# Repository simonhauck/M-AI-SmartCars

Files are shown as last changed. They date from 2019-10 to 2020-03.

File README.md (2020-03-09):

# M-AI-SmartCars
<p align="center">
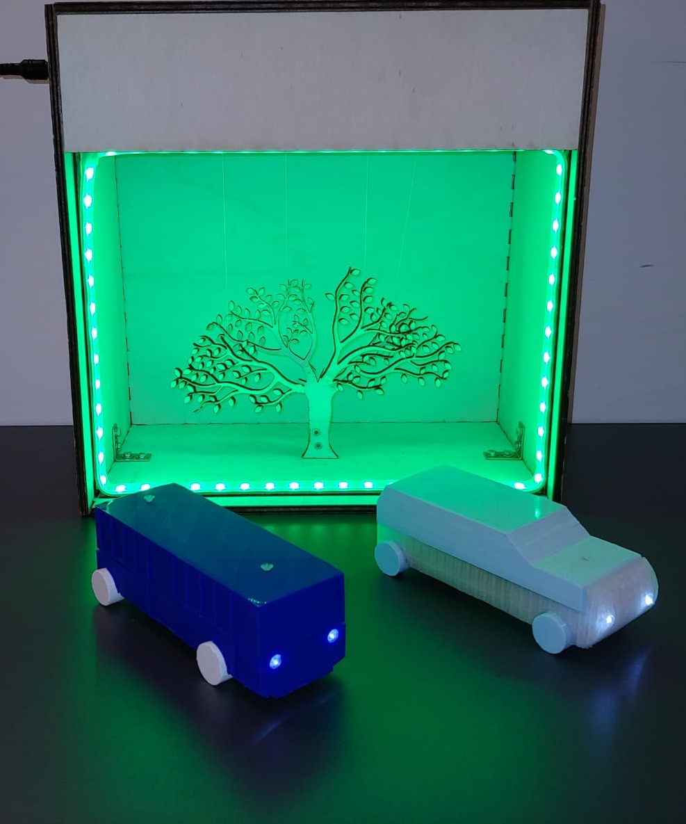
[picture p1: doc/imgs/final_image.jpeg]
  
</p>
This project is part of the course "Makers Lab - Things that think" at the Flensburg University of Applied Sciences. 
We had the motto "Flensburg goes green" and should use various prototype techniques to develop a physical prototype 
that should influence the behavior of the users to act more environmentally friendly.

Our project consist of two parts:
1. Two toy vehicles, a car and a bus, on which we track the driven distance
2. A tree that represents the environment

Our goal was to show children, and also adults the effects of driving for the environment. 
When the vehicles drive, the environment gets worse and the branches of the tree hang low. After a certain time the 
environment gets better and the tree recovers. Of course the bus had a less bad influence then the car.

## How does it work?

### The vehicles
The vehicles are 3D-printed, and contain each an [Arduino MKR 1010 Wifi](https://store.arduino.cc/arduino-mkr-wifi-1010), 
as well as an hall sensor (to be specific the SS 441A), a 3.7V lipo battery and a boost converter. The last one is 
required because the sensor requires 3.7V and with the battery connected the arduino delivers only 3.3V (even from the 5V pin).
Furthermore the vehicles contains two visible LEDs to act as headlights and indicators for the state of the arduino 
(Two in one :D).
The arduino connects on startup to a wireless network of the raspberry pi, that will be used to control the tree. More
on that later. The hall sensor detects if the vehicle is moving and sends the amount of ticks to the raspberry pi.

### The tree
The tree is controlled by a raspberry pi and contains an  LED strip and 4 servo motors. The raspberry pi also acts as an
access point to which the arduinos connect. The server is programmed in python with the flask framework and offers
a simple api to send the amount of ticks of the hall sensor. Depending on the vehicle type the generated pollution is
calculated and stored. The pollution affects the tree only for x seconds (x can be specified in the config file), after
that the entry will be deleted. 

To represent the state of the environment all stored pollution values are summed up and the hardware (the servo 
motors and the led strip) is set accordingly. Like a puppet, the branches of the tree will be moved up and down with
the servo motors. The led stripe is light up, with red and green according to the pollution.

## Structure of the repository
The for you probably most import folder is the src folder. This one contains
1. The 2d folder contains the .dxf file to create the tree and the box with a laser cutter
2. The 3d folder contains the models for the car and the bus. Note that we did some follow up manual work to screw 
both parts together and mount the sensor.
3. The arduino folder contains the wiring diagram and the sketch for the arduino
4. And the pi folder contains, (i think you could have guessed that) the wiring diagram and the python files.
The development server can be started with 
```python
sudo flask run --host=0.0.0.0
```

The other folders are just some stuff for our presentation etc.

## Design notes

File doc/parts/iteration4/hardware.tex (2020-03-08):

% !TeX spellcheck = de_DE
\documentclass[.../Dokumentation.tex]{subfiles}
\begin{document}
    \subsection{Hardware}\label{sec-ita4-hardware}
        \subsubsection*{Visualisierung}
    %Platine, LED Streifen, Autostart %
    Der Programmcode und die benötigte Hardware für die Visualisierung funktionieren bereits, trotzdem müssen noch kleine Optimierungen vorgenommen werden. Zuerst wird die Funktionsweise des LED-Streifens überarbeitet. Zuvor haben alle LEDs dieselbe Farbe angezeigt, welche sich aus Rot und Grün zusammensetzt. Die Farbe Grün ist hierbei intensiver als die Farbe Rot. Infolgedessen wirken die LEDs auch bei mittlerer Verschmutzung grün statt, wie gewünscht, orange.
    Erst bei starker Verschmutzung färben sie sich die LEDs orange und danach rot. Mit der neuen Implementierung zeigen die LEDs unterschiedliche Werte an. Je nach Verschmutzungsgrad färbt sich ein Teil der LEDs rot (Abbildung \ref{fig-hardware-tree-half-ref}). Ist die maximale Verschmutzung erreicht, sind alle LEDs rot. Hierdurch wird die gesamte Verschmutzung eindeutig dargestellt.
    \begin{figure}[H]
    	\begin{center}
    		\includegraphics[
    		width=0.5\linewidth,
    		]{imgs/tree_half_red.PNG}
    		\caption{Visualisierung mit neuer LED-Streifen Implementierung}
    		\label{fig-hardware-tree-half-ref}
    	\end{center}
    \end{figure}
	\noindent
    Im nächsten Schritt wird noch eine Platine für den Raspberry Pi erstellt. Diese kann wie ein Shield auf die Pins gesteckt werden und die Servo-Motoren sowie der LED-Streifen können direkt angeschlossen werden. Dies reduziert die Anzahl an benötigten Kabeln und erhöht die Übersichtlichkeit. Zuletzt wird die Konfiguration des Raspberry Pi überarbeitet. Der Flask-Webserver soll automatisch mit jedem Hochfahren des Systems gestartet werden. Somit muss wie auch bei den Fahrzeugen nur die Stromversorgung hergestellt werden, um den Prototypen zu benutzen.
        
    \subsubsection*{Fahrzeug}
    Für die voll funktionsfähige und getestete Schaltung muss eine Prototyp Platine erstellt werden. Die Basisplatine hat dieselbe Größe wie der Arduino. Somit kann die fertige Platine wie ein Shield auf den Arduino gesteckt werden und verbraucht wenig Platz. Allerdings muss das Layout wegen der begrenzten Größe vorher geplant werden. Eine Skizze hierfür ist in Abbildung \ref{fig-hardware-car-pcb-plan} dargestellt. 
    \begin{figure}[H]
    	\begin{center}
    		\includegraphics[
    		width=0.5\linewidth,
    		]{imgs/car_wiriring_plan.jpeg}
    		\caption{Konzept für die Fahrzeugplatine}
    		\label{fig-hardware-car-pcb-plan}
    	\end{center}
    \end{figure} 
	\noindent
    Die fertige Platine kann auf den Arduino gesteckt werden, welcher zusammen mit dem Akku, dem \textit{Step-Up Boost-Converter}, dem Sensor und den LEDs in das Auto eingebaut wird. Zusätzlich ermöglicht ein Schalter das einfache An- beziehungsweise Ausschalten der Batterie. Alle Verbindungen zwischen den Komponenten sind mit JST-Steckern realisiert. Hierdurch ist es möglich, jede Komponente einzeln auszutauschen, sollte ein Teil defekt sein oder für ein anderes Projekt wiederverwendet werden. Zudem wird so das Zusammensetzen der Fahrzeuge erleichtert, da einige Komponenten wie die LEDs fest verklebt sind.
    Zuletzt wird noch die Konfiguration der Fahrzeuge optimiert. Zuvor haben diese jede Sekunde einmal mal die erfassten Sensordaten gesendet. Da die durchschnittliche Ausführungszeit der \emph{loop}-Funktion bei ca. 100ms liegt, wird dieser Wert auf $250ms$ Sekunden reduziert. Die Fahrzeuge senden häufiger Daten und die Bewegungen des Baums werden infolgedessen weicher.

\end{document}

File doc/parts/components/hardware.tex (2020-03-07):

% !TeX spellcheck = de_DE
\documentclass[.../Dokumentation.tex]{subfiles}
\begin{document}
\subsection{Hardware}\label{sec-components-hardware}
Das Projekt besteht aus zwei Teilen, den Fahrzeugen und der Visualisierung.
Die hierfür benötigte Hardware soll im Folgenden vorgestellt werden.
Die genannten Komponenten beziehen sich auf das Konzept, welches in Kapitel 
\ref{sec-concept} vorgestellt wurde.
\subsubsection{Fahrzeuge}
Die Basis für die Fahrzeuge sollen Microcontroller sein. Diese benötigen 
wenig Strom und ermöglichen so ein längeres Spielvergnügen. 
Für die Fahrzeuge soll der Arduino MKR WiFi 1010 verwendet 
werden. Dieser ist 
ca. 62mm lang und 25mm breit und somit bedeutend kleiner als der Arduino Uno. 
Zusätzlich ist der Arduino besonders für IoT Projekte geeignet, da ein Low 
Power Prozessor (SAMD21) verwendet wird. Das Board besitzt zudem eine 
integrierte Ladeschaltung und einen Anschluss für einen Lithium-Polymer-Akku. 
Hierfür wird ein Modell mit einer Kapazität von 1000mAh verwendet, welches 
einen Kompromiss zwischen der Größe des Akkus und dem Formfaktor bietet. 
Des Weiteren besitzt der verwendete Arduino ein integriertes WiFi-Modul, welches 
später zur Kommunikation mit der Visualisierung verwendet wird.
Neben dem Microcontroller wird jedes Fahrzeug mit einem oder mehreren Magneten sowie einem 
Hall-Sensor ausgestattet. Der Hall-Sensor gibt ein Signal an den Arduino, 
wenn sich ein Magnet in dessen Nähe befindet. Diese werden später zur Erkennung 
von Radumdrehungen verwendet. Zuletzt werden zwei LEDs mit den dazugehörigen 
Widerständen als Scheinwerfer verwendet.

\subsubsection{Visualisierung}
Die Basis für die Visualisierung soll ein Raspbbery Pi 4 sein. An diesen kann 
ein Display angeschlossen werden, welches später die erfassten Daten 
aufbereitet anzeigt. Der Raspberry Pi fungiert zusätzlich als WLAN 
\textit{Access Point}. Die in den Fahrzeugen verwendeten Arduinos können sich 
direkt mit diesem verbinden womit die kabellose Übertragung der Daten 
gewährleistet ist. Dieser Aufbau hat den Vorteil, dass keine weitere 
Hardware wie zum Beispiel ein Router zwischen den Komponenten benötigt wird.

\end{document}

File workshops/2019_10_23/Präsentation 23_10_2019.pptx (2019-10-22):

## Smart Cars

Gruppe Müllteppich

## Fahrzeuge - Stand

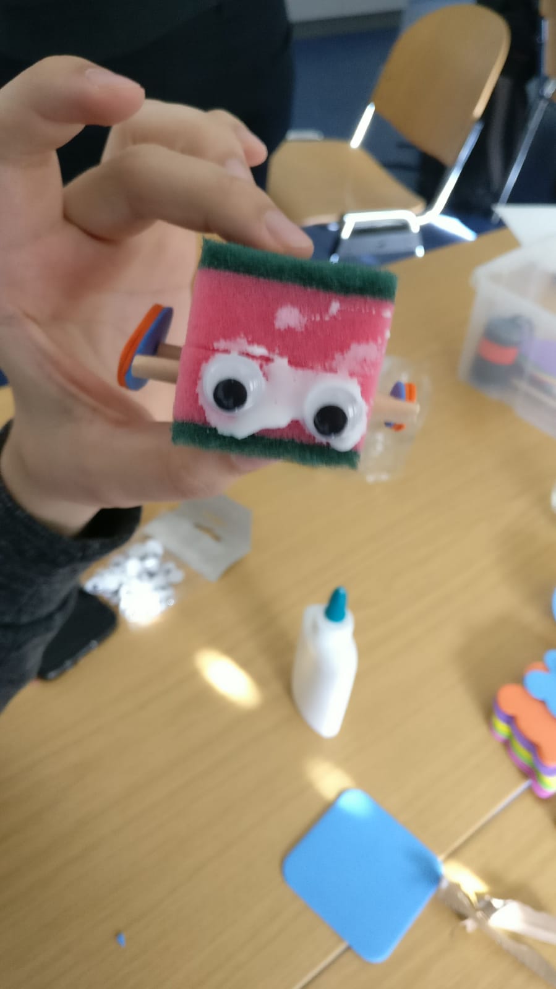
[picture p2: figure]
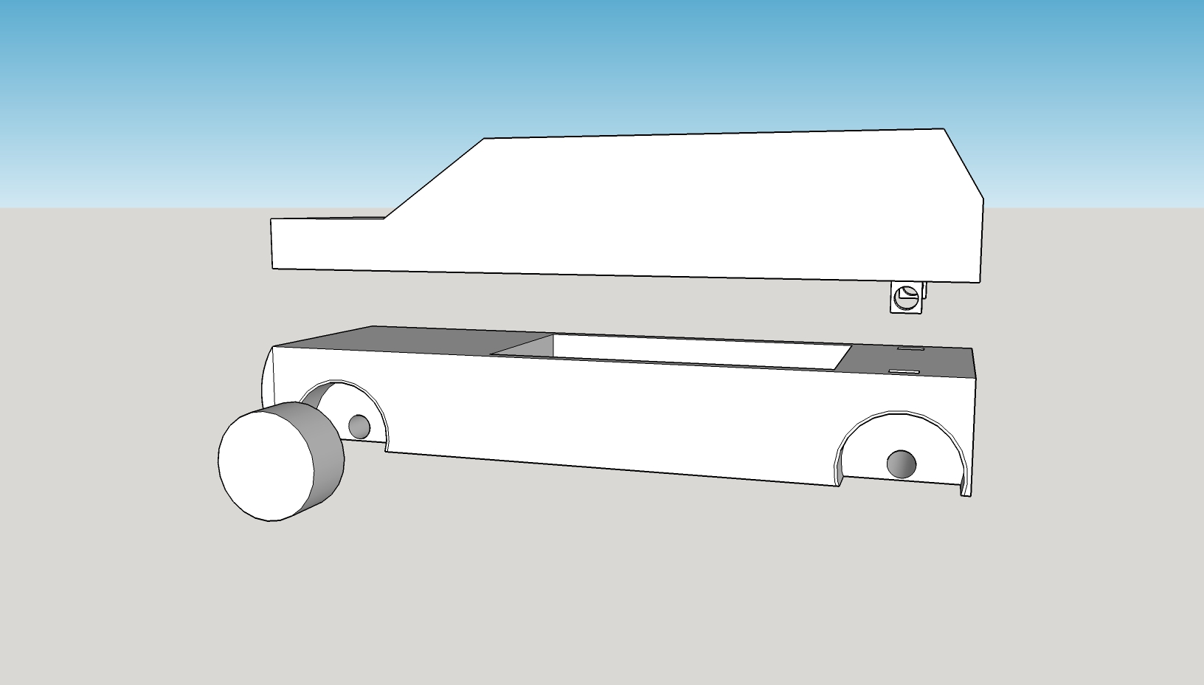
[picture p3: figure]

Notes: Nils

## Fahrzeuge - Stand

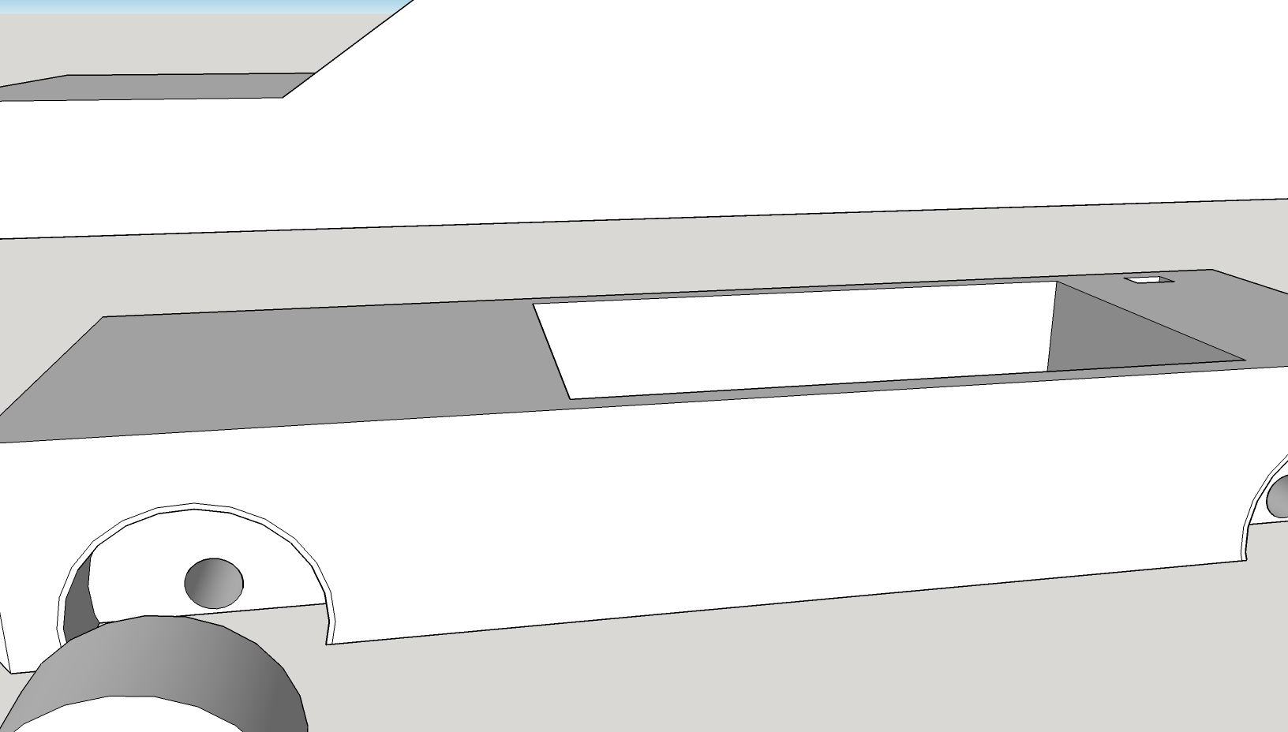
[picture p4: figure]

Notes: Nils

## Fahrzeuge - Stand

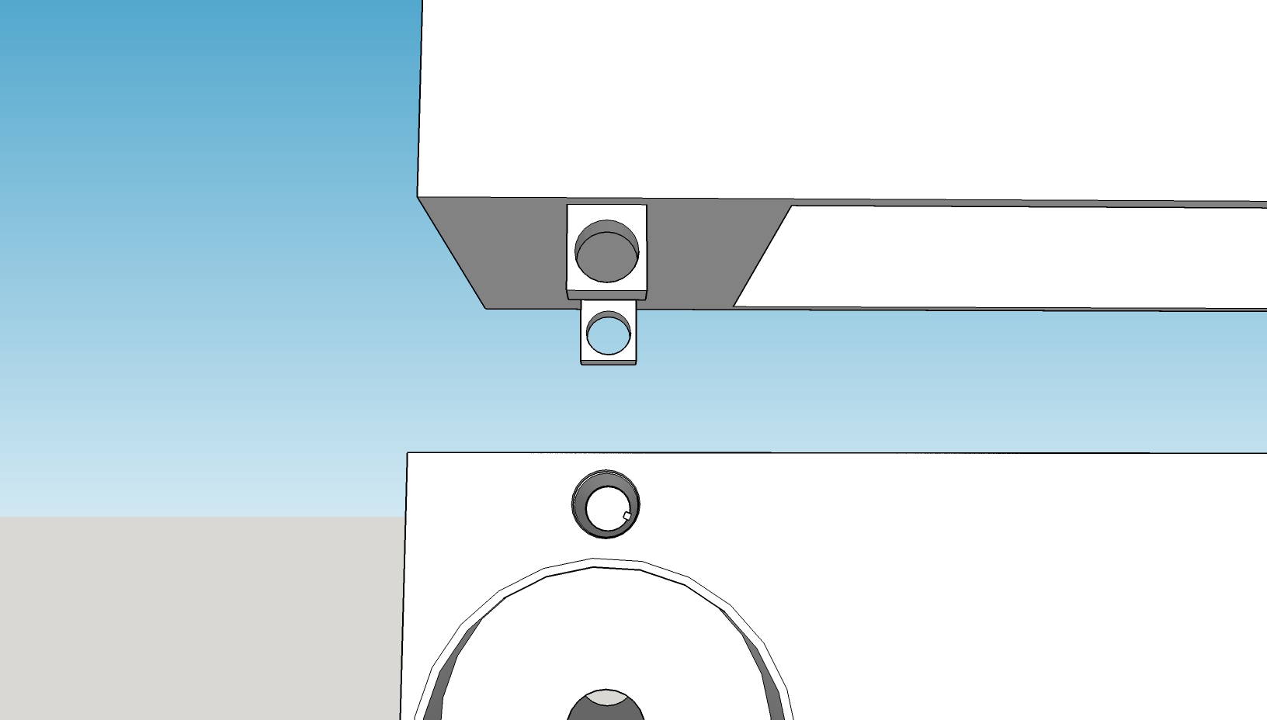
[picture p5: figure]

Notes: Nils

## Fahrzeuge - Stand

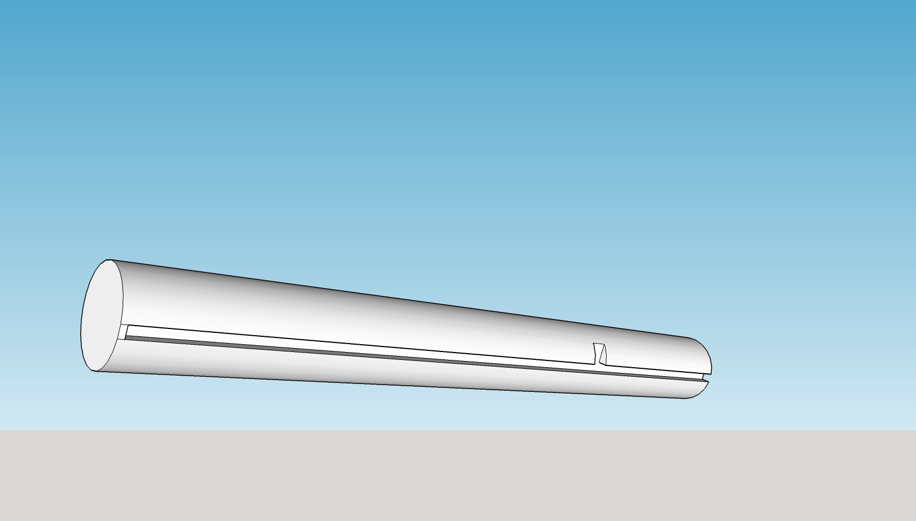
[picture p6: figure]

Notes: Nils

## Fahrzeuge - Herausforderungen

- Formfaktor
- Zusammenführung der Komponenten
- Ladebuchse einbauen

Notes: Nils

## Baum - Stand

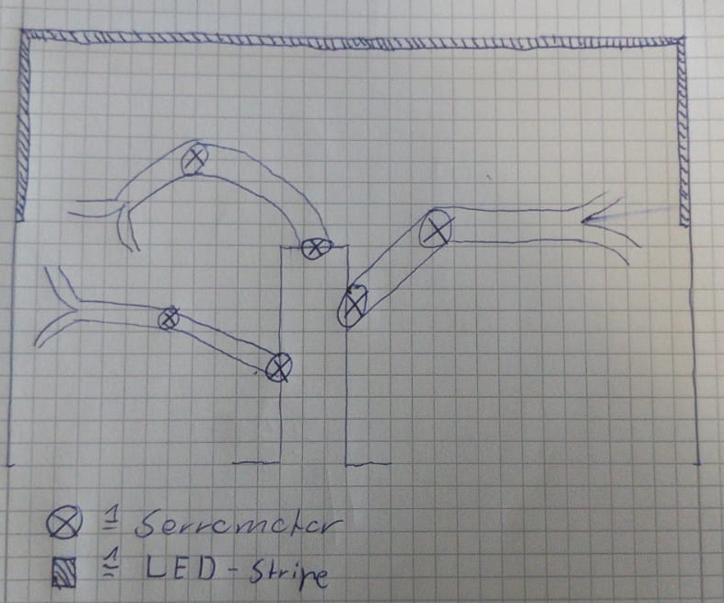
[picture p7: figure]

- Neue Form der Darstellung
- Alternative zu Display und Chart.js

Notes: Nils

## Baum - Herausforderungen

- Umsetzung
  - Lasercutter
  - 3D Druck
- Verbauen der Technik vs. Baum – „Look“
- Gehäuse und LED Integration

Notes: Nils

## Schaltplan - Stand

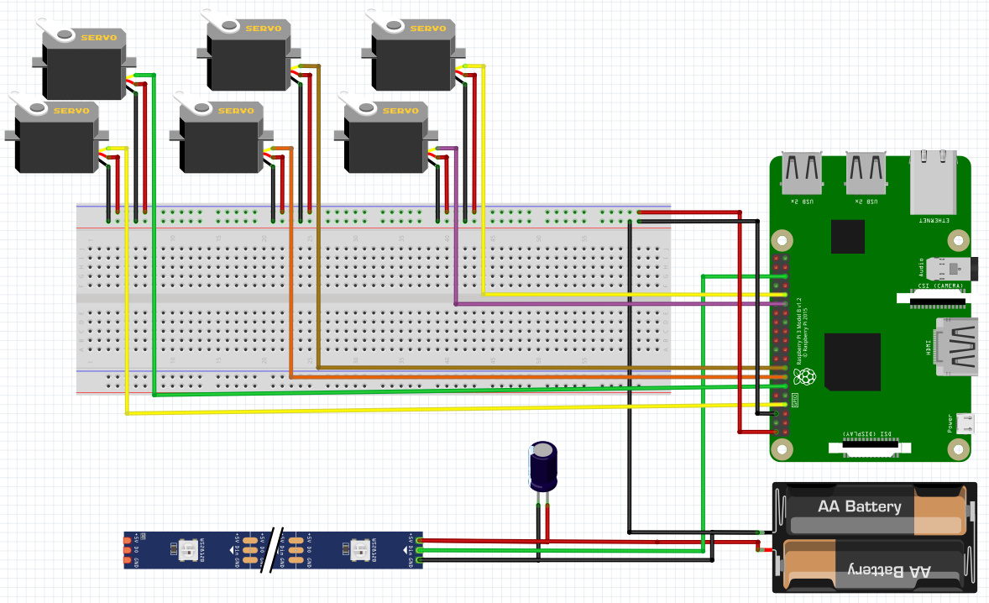
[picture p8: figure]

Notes: Nils

## Schaltplan - Stand

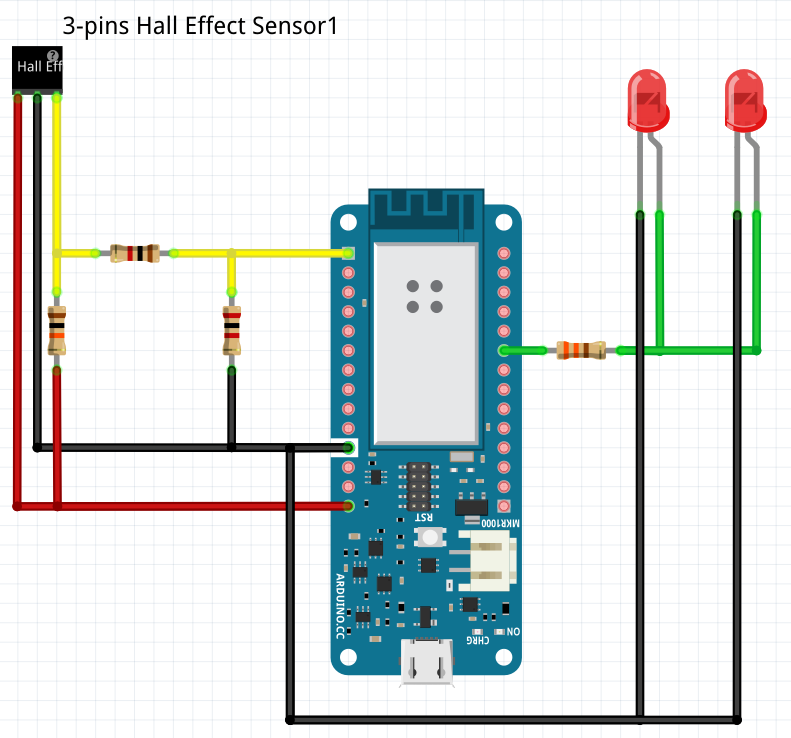
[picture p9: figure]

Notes: Nils

## Schaltplan – Herausforderungen

- Aktueller Microcontroller ungeeignet
  - Max. 3.3V vs 5V
  - Hall-Sensor benötigt mehr Volt
  - Kein Datenblatt zu Sensoren
- Daher bislang keine Tests möglich
- -> Warten auf Hardware

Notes: Nils

## Datemodell Fahrzeuge

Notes: Nils

## Datemodell Baum

- Berechnung der „Verschmutzung“ in letztem Intervall
- Verzögerung
  - Bei Auswirkung
  - Und Regeneration

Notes: Nils

## Untergrund

- Optional: sobald Fahrzeuge und Baum fertig sind
- Realistisch vs Abstrakt
- Da Darstellung bereits abstrakt
  - Abstrakter Untergrund vorzuziehen

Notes: Nils

## Next Steps

- Erster Druck (KW44)
- Backend Implementierung beenden
- Hardware Implementierung beginnen
  - Hall-Sensor testen
  - WIFI testen
  - Scheinwerfer evaluieren

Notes: Nils

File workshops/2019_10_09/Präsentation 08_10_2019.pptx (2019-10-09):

## Smart Cars

Gruppe Müllteppich

## Projektidee

- Verdeutlichung der täglichen Emissionen
- Autofahren macht einen großen Teil aus
- Ziel
  - Veranschaulichen der produzierten Emissionen
  - Steigerung des Umweltbewusstseins
- Zielgruppe:
  - (Junge) Erwachsene
  - Kinder

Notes: Nils

## Projektidee

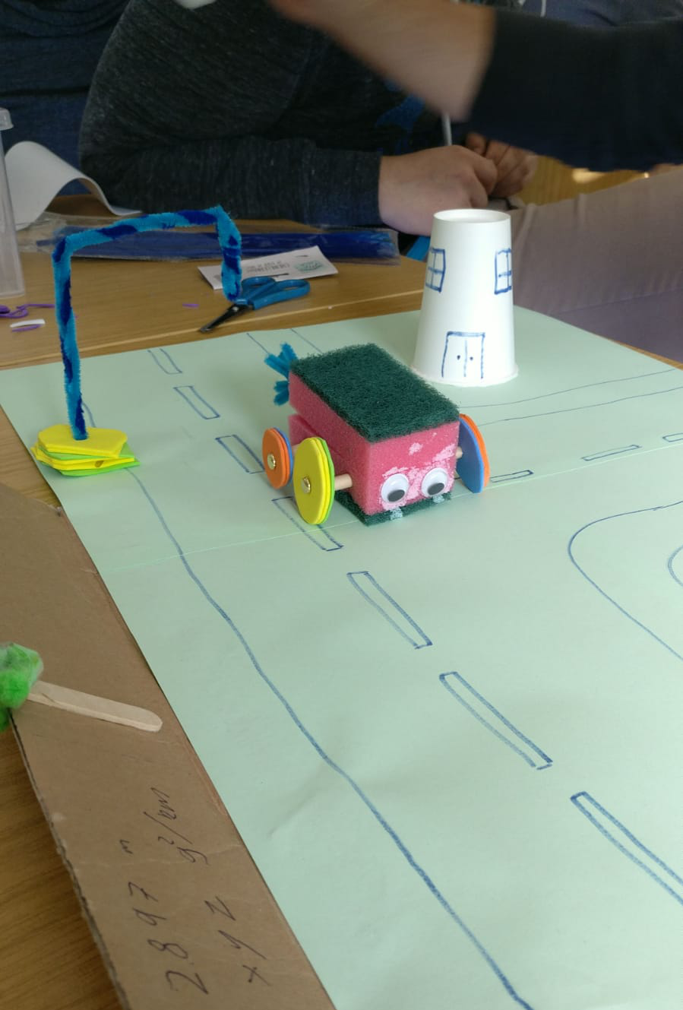
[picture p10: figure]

- Anforderung
  - Einfache Bedienung
    - Keine Konfiguration durch den Nutzer
    - Plug & Play Erfahrung
  - Einfache Visualisierung der Daten

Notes: Nils

## Komponenten & Konzept

- Zwei Pflichtkomponenten
  - 1 – n verschiedene Fahrzeugtypen
    - Verschiedene Emissionsprofile
  - Basis Station
    - Datenspeicherung
    - Datenaufbereitung
- Eine Optionale Komponente
  - Weitere Form der Visualisierung
    - Ballon der verbrauchtes CO2 darstellt
    - LEDs für gesamte CO2 Belastung


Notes: Simon

## Hardware

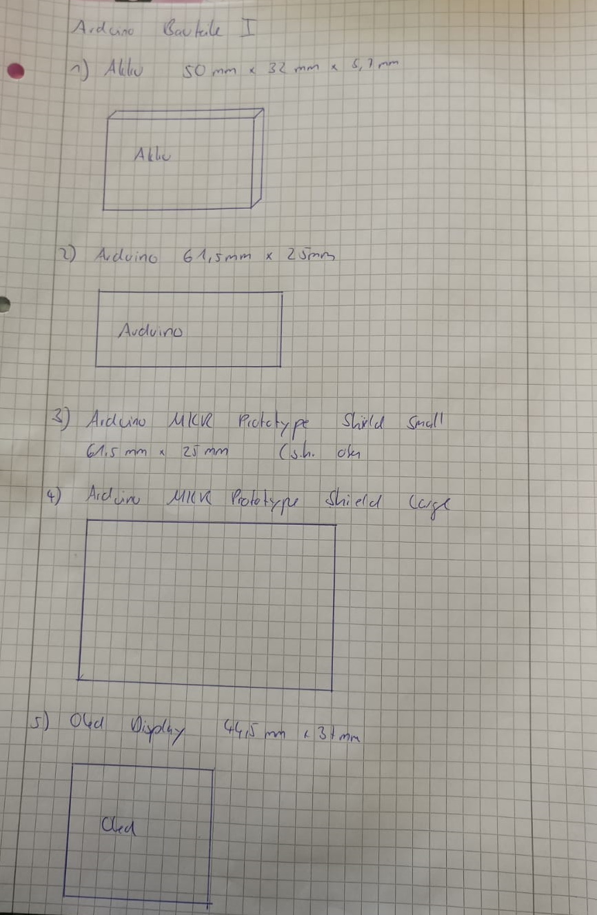
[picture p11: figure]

- Fahrzeuge
  - Arduino mit integriertem Wifi Modul
  - Batterie zur autarken Energieversorgung
  - Sensor zum Erfassen der gefahrenen Strecke / Geschwindigkeit
- Basis Station
  - Raspberry Pi 3B+ mit Wifi Modul
  - Display zur Datenvisualisierung
  - (Optional) Integrierter LEDs
  - (Optional) Luftballon

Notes: Simon

## Aktueller Stand

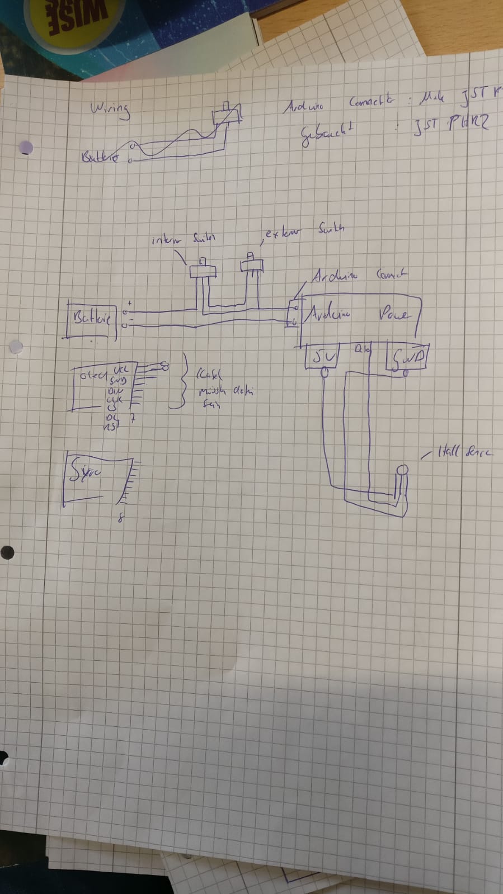
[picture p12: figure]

- Hardware Recherche
  - Auto: Erledigt, benötigt Freigabe
  - Backend: Erledigt, bis auf Ventil
- Fahrzeuge
  - Hardware Skizze
  - Konzeptskizze mit Maßen
- Erste Schritte 3D Modellierung

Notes: Simon

## Next Steps - Backend

- Evaluation
  - Web-Framework
    - Vermutlich Flask
    - Schnittstelle für Sensordaten
    - Darstellung als Website
  - Darstellung
    - Vermutlich ChartJS
  - Hardware
    - (Optional) Library für LEDs
    - (Optional) Steuerung Pumpe/Ventil für Ballon

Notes: Simon

## Next Steps – Auto

- Evaluation
  - 3D Druck für Fahrzeuge
    - Tools zum Erstellen der Modelle (Blender, …)
- Bestellung der Hardware
- Elektronik testen

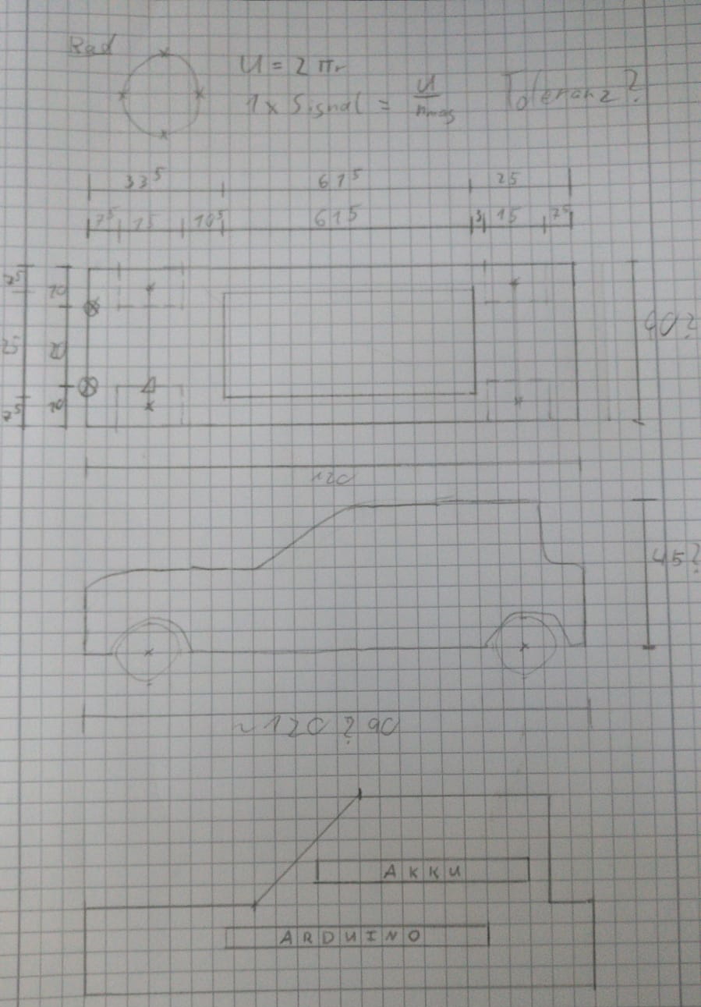
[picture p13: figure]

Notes: Nils

## Next Steps – Allgemein

- Untergrund abklären
- Möglichkeiten des FabLab abklären
- Hardwarebestellung durchführen
- Sonstige Materialien
  - Breadboard, JumperWires, Resistors

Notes: Nils

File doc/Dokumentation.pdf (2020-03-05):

## Hochschule Flensburg

# SmartCars

## Maker’s Lab - Things that Think

## Abschlussbericht

## vorgelegt von:

Simon Hauck | Nils Jensen
660158 | 670758
Hochschule Flensburg | Hochschule Flensburg
simon.hauck@stud.hs-flensburg.de | nils.jensen2@stud.hs-flensburg.de
5. März 2020

## Inhaltsverzeichnis

1 Einleitung | 2
2 Konzept | 3
3 Komponenten | 4
4 1. Design-Iteration | 5
5 2. Design-Iteration | 11
6 3. Design-Iteration | 16
7 4. Design-Iteration | 21
8 Fazit | 27

## 1 Einleitung

Im Zuge der Veranstaltung “Maker’s Lab - Things that Think“ wurde die Entwicklung interaktiver Systeme, bestehend aus Hard- sowie Software, thematisiert. Neben dem Fokus auf der Verwendung von Raspberry Pi beziehungsweise Arduino als Hardware-Komponenten lag ein weiterer Schwerpunkt auf der Verwendung von Techniken und Praktiken aus den Bereichen making und rapid prototyping. Unter Berucksichtigung die- ¨ ser Punkte galt es, eine “anfassbare“ Schnittstelle zwischen Mensch und Computer zu schaffen, welche gleichzeitig thematisch dem Klimapakt Flensburg und seiner Mission entspricht. Nachfolgend soll einerseits die Motivation und andererseits die daraus resultierende Projektidee umschrieben werden.

### 1.1 Motivation

Mit dem Ziel, die Folgen alltäglichen Handelns des Einzelnen fur die Umwelt besser ver- ¨ anschaulichen zu können, soll die tägliche Verwendung des eigenen PKWs thematisiert werden. Bei der späteren Interaktion mit dem fertigen Prototypen soll vor allem der
Fokus darauf liegen, generationsubergreifend eine m ¨ | öglichst intuitive und zugängliche
Bedienung zu bieten. Vor diesem Hintergrund sollen bereits bekannte Konzepte und Komponenten aufgegriffen werden und die Möglichkeit bieten, auf spielerische Art und Weise zu lernen.

### 1.2 Projektidee

Es soll eine Kombination aus Eingabegerät und Darstellung geschaffen werden, die sich grob an der Bewegung von Spielzeug-Autos auf einem, mit einer abstrakten Stadt und ihrer Verkehrsinfrastruktur bedruckten Teppich orientiert. Gleichzeitig soll maßstabsgetreu die Bewegung der Fahrzeuge aufgenommen und in ihre entsprechende CO2-Emmission
ubersetzt werden. Die so anfallende Belastung f ¨ | ur die Umwelt soll auf einem Display ¨
optisch ansprechend aufbereitet und mit anschaulichen, zusätzlichen Informationen zusammen gebracht werden. Hierdurch sollen die Konsequenzen des eigenen Handelns verdeutlicht und so einem Nutzer näher gebracht werden können, als es durch das Auflisten
von Statistiken oder Ahnlichem m ¨ | öglich wäre.

2

## 2 Konzept

Im Folgenden soll nun umrissen werden, wie die in 1.2 formulierte Idee zu realisieren ist. Als Kontaktpunkt des Nutzers mit dem System sollen eins oder mehrere der erwähnten Fahrzeuge eingesetzt werden. Diese sollen per Hand bewegt werden. Im Kontrast hierzu stunde eine Umsetzung, in der die Fahrzeuge zum Beispiel mit Hilfe einer App fern ¨ gesteuert werden können. Dies soll zum Einen eine einfachere, vor allem aber auch kos-
tengunstigere Umsetzung erm ¨ | öglichen und zum Anderen ein intuitiveres Bedienerleb-
nis bieten. Um hierauf aufzubauen und den thematischen Schwerpunkt des Klimapakts Flensburg aufzugreifen, soll die Möglichkeit in Betracht gezogen werden, anstelle eines generischen Teppichs eine maßstabsgetreue Darstellung der Flensburger Innenstadt sowie eventuell des Umlands zu verwenden. Auf diesem Wege wäre es weiter möglich, die Konsequenzen auch kurzerer Fahrten zu verdeutlichen. Die Darstellung mittels des Dis- ¨ plays könnte neben aufbereiteten Zahlen weiter um eine Repräsentation der Emissionen in weniger abstrakter Form, wie eine Menge an bestimmten Lebensmitteln, deren Produktion und Transport gleiche Werte verursachen, ergänzt werden. Weiter könnte das Display um eine zusätzliche Luftpumpe ergänzt werden, welche Ballons entsprechend der Emissionen aufpumpt.

### 2.1 Umsetzung

Um die Anforderungen an die Fahrzeuge erfullen zu k ¨ | önnen, wurde einerseits evaluiert,
fertige Spielzeugautos zu erwerben und um die elektronischen Komponenten zu erwei-
tern, die zur Messung der zuruck gelegten Distanz und der Kommunikation ben ¨ | ötigt
werden. Allerdings hätte sich vorab nicht ohne Zweifel sagen lassen können, ob der fur ¨ diese Erweiterungen erforderliche Platz vorhanden ist oder sich schaffen lässt, ohne das Auto seiner Funktion zu berauben. Andererseits bestand die Option, die Fahrzeuge von Grund auf selbst herzustellen. Auf diese Weise kann sichergestellt werden, dass genug Platz fur die erforderliche Technik vorhanden ist. An dieser Stelle ensteht jedoch ein ¨ Konflikt zwischen dem Platzbedarf der zu ermittelnden Komponenten und einem der Projektidee entsprechenden Formfaktor der Fahrzeuge. Weiter sollen die Fahrzeuge in einer Form geschaffen werden, die es erlaubt, ohne weitere Konfiguration ”los zu fahren”, sobald eine initiale, quasi werksseitige, Konfiguration durchgefuhrt wurde und die ¨ Stromversorgung hergestellt ist. Die Stromversorgung der Fahrzeuge soll mit Hilfe von Akkus umgesetzt werden, damit keine Kabel etwaiger Netzteile bei den Bewegungen
der Fahrzeuge berucksichtigt werden m ¨ | ussen oder diese gar behindern. Ein Verzicht auf ¨
Kabel soll auch in der Kommunikation der Fahrzeuge mit der Steuerung der Darstellung gewahrt bleiben. Hierdurch entsteht die Anforderung, beide Seiten des Systems mit solchen Bauteilen auszustatten, die eine drahtlose Kommunikation erlauben. Die erforderlichen Komponenten sollen so gewählt und installiert werden, dass eine Wartung ohne unverhältnismäßigen Aufwand möglich ist. Weiter soll durch die Durchfuhrung der Mon- ¨ tage gewährleistet werden, dass kostspieligere Bauteile entfernt und anderweitig erneut eingesetzt werden können.

3

## 3 Komponenten

### 3.1 Hardware

Das Projekt besteht aus zwei Teilen, den Fahrzeugen und der Visualisierung. Die hierfur ¨ benötigte Hardware soll im Folgenden vorgestellt werden. Die genannten Komponenten beziehen sich auf das Konzept, welches in Kapitel 2 vorgestellt wurde.

### 3.1.1 Fahrzeuge

Die Basis fur die Fahrzeuge sollen Microcontroller sein. Diese ben ¨ | ötigen wenig Strom
und ermöglichen so ein längeres Spielvergnugen. F ¨ | ur die Fahrzeuge soll der Arduino ¨
MKR Wifi 1010 verwendet werden. Dieser ist ca. 62mm lang und 25mm breit und somit bedeutend kleiner als der Arduino Uno. Zusätzlich ist der Arduino besonders fur IoT ¨ Projekte geeignet, da ein Low Power Prozessor (SAMD21) verwendet wird. Das Board besitzt zudem eine integrierte Ladeschaltung und einen Anschluss fur einen Lithium- ¨
Polymer-Akku. Hierfur wird ein Modell mit einer Kapazit ¨ | ät von 1000mAh verwendet,
welches einen Kompromiss zwischen Größe des Akkus und dem Formfaktor bietet. Des weiteren besitzt der verwendete Arduino ein integriertes Wifi Modul, welches später zur Kommunikation mit der Visualisierung verwendet wird.
Neben dem Microcontroller wird jedes Fahrzeug mit einem oder mehreren Magneten sowie einem Hall-Sensor ausgestattet. Der Hall-Sensor gibt ein Signal an den Arduino, wenn ein Magnet sich in dessen Nähe befindet. Diese werden später zur Erkennung von Radumdrehungen verwendet. Zuletzt werden zwei LEDs mit den dazugehörigen Widerständen als Scheinwerfer verwendet.

### 3.1.2 Visualisierung

Die Basis fur die Visualisierung soll ein Raspbbery Pi 4 sein. An diesen kann ein Dis- ¨ play angeschlossen werden, welches später die erfassten Daten aufbereitet anzeigt. Der Raspberry Pi fungiert zusätzlich als WLAN Access Point. Die in den Fahrzeugen verwendeten Arduinos können sich direkt mit diesem verbinden und somit ist die kabellose
Ubertragung der Daten gew ¨ | ährleistet. Dieser Aufbau hat den Vorteil, dass keine weitere
Hardware, wie zum Beispiel ein Router zwischen den Komponenten, benötigt wird.

### 3.2 Software

Fur das Projekt werden zwei verschiedene Programmiersprachen verwendet. Die Ar- ¨ duinos verwenden standardmäßig eine C- beziehungsweise C++-ähnliche Programmier-
sprache, fur welche die Entwicklungsumgebung ¨ | Arduino IDE verwendet wird. Fur die ¨
Visualisierung stehen verschiedene Programmiersprachen zur Auswahl. Fur dieses Pro- ¨ jekt soll Python 3.7 verwendet werden. Diese Sprache ermöglicht das einfache Erstellen eines Webservers, welcher zum Empfangen der Daten genutzt wird und das Ansteuern der IO-Pins beziehungsweise des Displays von dem Raspberry Pi.

4

### 3.2.1 Modellierung und Slicing

Um die fur die Herstellung der Fahrzeuge mit Hilfe von 3D-Druck ben ¨ | ötigten Modelle
anfertigen zu können, war es erforderlich, eine geeignete Software zur Modellierung auszuwählen.
Zweierlei Lösungen wurden hierfur in Betracht gezogen. Zum Einen ¨ | Blender, da das nach
eingangs erfolgter Recherche erfoderliche Dateiformat stl nativ unterstutzt wird und ¨ derartig weit verbreitete Open Source Lösungen oft eine entsprechend große Community vorweisen können. Zum Anderen SketchUp, welches zwar nur mit verringertem Funkti-
onsumfang frei verfugbar ist, aber besonders durch seine einfache Bedienung ¨ | uberzeugen ¨
kann.
Die Wahl fiel darauf, zunächst erste Gehversuche mit Blender zu unternehmen und im Fall größerer Schwierigkeiten in der Bedienung auf SketchUp zuruck zu greifen, da mit ¨
dieser Software bereits Erfahrungen gesammelt wurden. Die Unterstutzung f ¨ | ur das ¨ | stl
Format muss in diesem Fall jedoch uber Erweiterungen sichergestellt werden. ¨
Zur Vorbereitung etwaiger Modelle fur den Druck war es weiter n ¨ | ötig, eine geeignete
Software fur den ¨ | Slicing-Vorgang zu finden. Nach erfolgter Recherche und auf Anraten
des FabLab der Hochschule Flensburg fiel die Wahl auf Cura. Neben einfacher Hand-
habung uberzeugt ¨ | Cura durch die Unterstutzung der zur Durchf ¨ | uhrung des Projekts ¨
verfugbaren Drucker und dem ¨ | stl- Format.

### 3.3 Werkzeuge

## 4 1. Design-Iteration

### 4.1 Fahrzeuge

Vor Beginn erster Modellierungsarbeiten wurden zunächst bemaßte Skizzen, zu sehen in Abbildung 1, angefertigt. Hierdurch war es möglich, den ermittelten Platzbedarf der Hardware Komponenten abzuschätzen und einen ersten Eindruck der Dimensionen der Fahrzeuge zu erhalten.

5


Abbildung 1: Erste Skizze eines Fahrzeugs

Bei der eigentlichen Modellierung wurde versucht, zunächst mit so wenig Details wie möglich, die grobe Form eines PKW nachzubilden. Hierzu wurde mit Blender zunächst ein Quader geschaffen, der in seinen Dimensionen der Skizze entspricht.
Allerdings zeichnete sich bereits bei der Modellierung dieser Rohform ab, dass die Arbeiten mit Blender in keinem zufriedenstellenden Tempo voran schreiten können. Aus diesem Grund wurde die in 3.2.1 zur Sprache gekommene Ausweichlösung in Form von SketchUp fur den Rest der Arbeiten verwendet. ¨
Der auf diesem Wege, nun in SketchUp, geschaffene Quader wurde in seiner Form dahingehend manipuliert, dass er äußerlich eher als PKW zu erkennen ist. Neben einer angedeuteten Frontsektion mit Motorhaube und abgeschrägter Scheibe wurden bereits
in diesem Schritt Radkästen und Aussparungen fur die sp ¨ | äter benötigten Achsen ge-
schaffen. Bei der Dimensionierung der Räder und infolgedessen auch der Radkästen galt es zu beachten, dass die verwendeten Magneten ausreichend Platz finden, ohne später die strukturelle Integrität des Drucks zu gefährden oder sich so nah bei einander befinden, dass vom Hall-Sensor keine einzelnen Magneten mehr erkannt werden können.
Um den Raum fur die elektronischen Komponenten zu schaffen, wurde das Fahrzeug ho- ¨ rizontal in etwa in der Mitte seiner Höhe in zwei Teilmodelle aufgebrochen. In sowohl die

6

untere als auch die obere Hälfte wurde nun eine rechteckige Aussparung eingearbeitet, die der Skizze aus Abbildung 1 entsprechend, ausreichend Platz bietet. Hierbei galt es
zu beachten, Anderungen an den Dimensionen der einen H ¨ | älfte präzise auf die andere
anzuwenden.
Die hier beschriebenen Arbeitsschritte sind in den Abbildungen 2 und 3 zu sehen.


Abbildung 2: Seitenansicht des ersten Modells


Abbildung 3: Aussparung im ersten Modell

Abbildung 2 zeigt weiter einen ersten Ansatz, um beide Fahrzeughälften miteinander verbinden und so fixieren zu können. In der unteren Hälfte werden Aussparungen vorgesehen, in die entsprechende Elemente der oberen eingelassen werden können. Diese zeichnen sich durch eine ösenartige Form aus. Somit ist es möglich, entsprechend bemessene Bolzen durch beide Hälften zur gleichen Zeit zu fuhren, um diese zu fixieren. ¨
Um zu gewährleisten, dass die aus der Skizze ubernommenen Maße zufriedenstellend ¨ sind, wurde an dieser Stelle mit einem ersten Druck begonnen. Die in Cura verwendeten Einstellungen wurden unter Anleitung des FabLab Personals an den jeweiligen Drucker angepasst. Abbildung 4 zeigt das Ergebnis dieses Drucks.

7

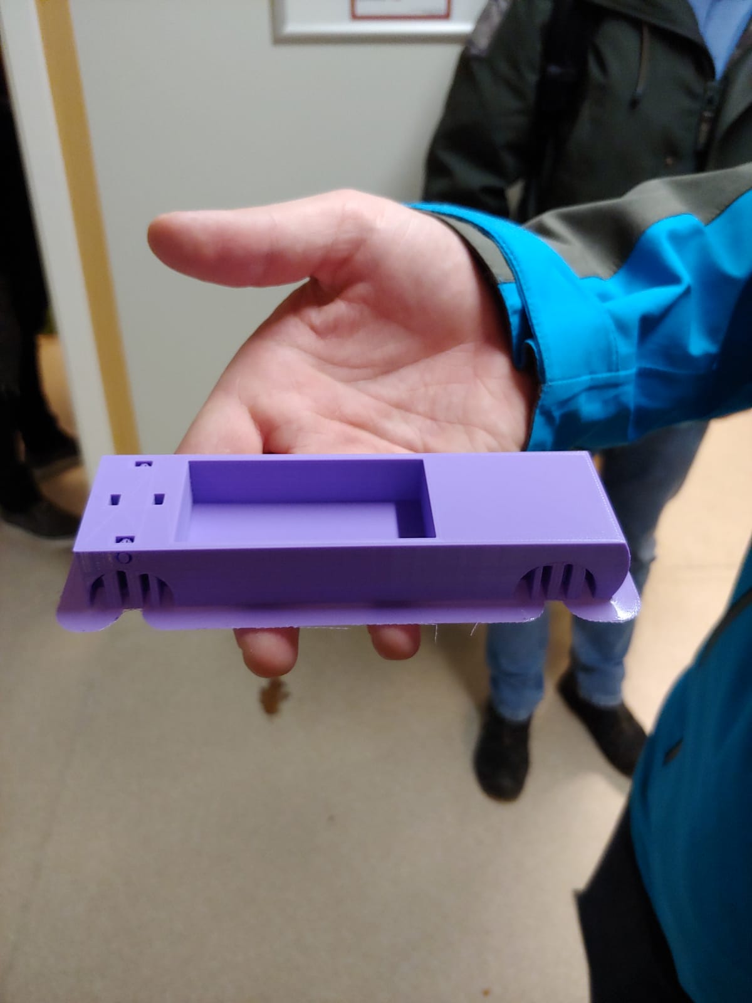
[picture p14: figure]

Abbildung 4: Druck des ersten Modells

### 4.2 Hard- und Software

Fahrzeug

Nachdem die Hardware eingetroffen ist, soll in einem ersten Schritt die Funktionalität des Hall-Sensors testweise implementiert werden. Das Ziel ist herauszufinden, bis zu welchem Abstand der Sensor die Magneten erkennt und ob der Einsatz von mehreren Magneten in den Reifen möglich ist. Fur den Sensor steht nur Dokumentation im Rahmen eines ¨ Datenblattes zur Verfugung. ¨
Hierbei erweist es sich als schwierig, die Bedeutung der drei Pins zu erkennen. Letztendlich stell sich heraus, dass der linke Pin +, der mittlere GND und der letzte das Output Signal ist.
Beim Erstellen der Schaltung entsteht ein weiteres Problem. Der Sensor benötigt fur ¨ den Betrieb mindestens 3.7V . Somit muss der + Pin an den 5V Pin des Arduinos angeschlossen werden. Der Output Pin liefert dementsprechend auch 5V muss mit einem IO-Pin des Arduinos verbunden werden, damit das Signal von diesem eingelesen werden kann. Allerdings vertragen diese maximal 3.3V oder das Board kann beschädigt werden.

8

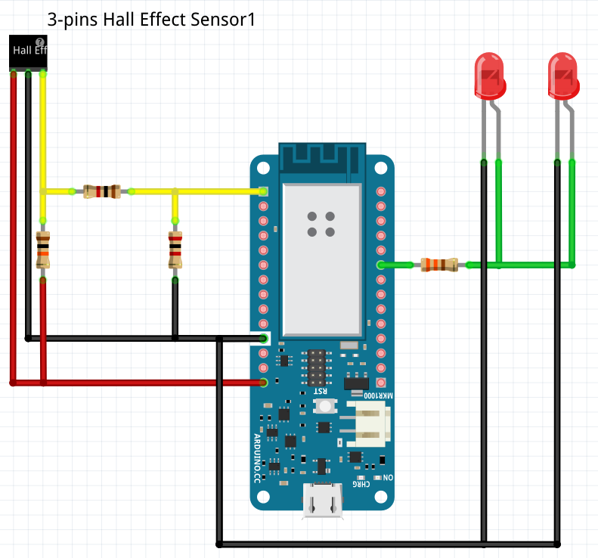
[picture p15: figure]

Abbildung 5: Erstes Konzept des Schaltplans fur die Fahrzeuge ¨

Mit einem 1k Ω und 2k Ω Widerstand können Spannungen von 5V auf 3.3V runter gesetzt werden.Zusätzlich soll ein 10k Ω Pull-Up Widerstand verwendet werden, welcher den verwendeten Pin des Arduinos auf HIGH zieht, solange kein Magnet erkannt ist. Das verwendete Diagramm ist in Abbildung 5 dargestellt. Hierbei werden zusätzlich zwei
LEDs hinzugefugt, welche sp ¨ | äter als Scheinwerfer in dem Fahrzeug verwendet werden.
Beim Testen der Schaltung wird festgestellt, dass die Kombination aus Pegelwandler und dem Pull-Up Widerstand nicht funktioniert und kein Auslesen von Sensorwerten möglich ist.

### 4.3 Darstellung

Da bereits vor der ersten Materialbestellung deutlich wurde, dass geeignete Displays den
finanziellen Rahmen des Projekts sprengen wurden, wurden Konzepte f ¨ | ur alternative ¨
Formen der Visualisierung erarbeitet.
Obwohl die Machbarkeit zu diesem fruhen Zeitpunk der Durchf ¨ | uhrung nicht abschließend ¨
geklärt werden konnte, fiel die Wahl auf eine abstraktere Art der Darstellung in Form eines Baums mit beweglichen Asten. ¨
Bei zunehmenden Emissionen sollen diese Aste mit Hilfe von Servomotoren abgesenkt ¨ und gleichermaßen nach einer bestimmten Zeit wieder angehoben werden können. Um das so entstehende Bild weiter ausprägen zu können, soll der gesamte Baum in einer Kiste montiert werden, welche in ihrem inneren mit LEDs umrandet ist. Diese sollen,
abhängig von der Position der Aste, ihre Farbe von gr ¨ | un zu rot wechseln. Abbildung 6 ¨
zeigt eine fruhe Konzeptskizze der Umsetzung dieses Baums. ¨

9


Abbildung 6: Erste Skizze des neuen Visualisierungskonzepts

### 4.4 Ergebnis

Obwohl die in 4.1 gezeigte Skizze die Dimensionen der zu installierenden Komponenten genau berucksichtigte, war der im Inneren des Fahrzeugs vorgesehene Platz nicht aus- ¨ reichend bemessen. Zu sehen ist diese Abweichung in Abbildung 7. Der Grund hierfur ¨ war, dass die Spezifikationen des gewählten Akkus nicht berucksichtigten, dass der Akku ¨
selbst zusätzlich in einer schutzenden H ¨ | ulle verpackt ist. ¨
Um diese Hulle nicht entfernen zu m ¨ | ussen, wurden die Maße der Aussparung im Inneren ¨
des Fahrzeugs angepasst. Dadurch ergab sich weiter der Bedarf, diesen Zuwachs auch auf die Außenmaße anzuwenden.
Außerdem wurde deutlich, dass das beispielsweise fur die Radk ¨ | ästen benötigte Stutzmaterial ¨
auch in den Hohlräumen der Befestigungsvorrichtung eingesetzt wurde. Cura verfugt ¨
nicht uber die Option, St ¨ | utzmaterial nur punktuell einzusetzen. Es wird entweder an ¨
jeder ermittelten Stelle verwendet oder an keiner.

10

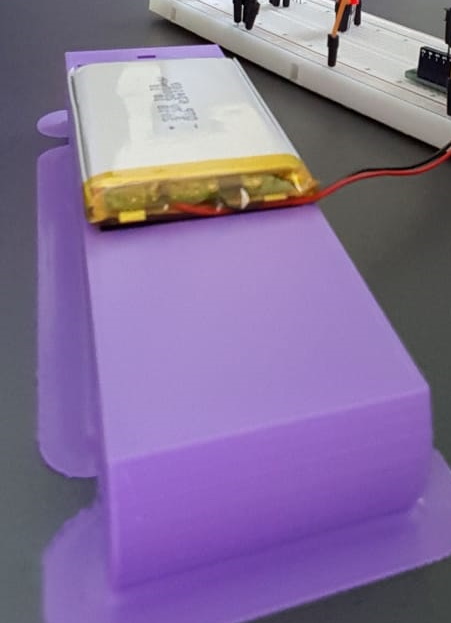
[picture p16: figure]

Abbildung 7: Abweichende Maße des Akkus durch Hulle ¨

Durch die Wahl einer abstrakteren Art der Darstellung fur die anfallenden Emissionen ¨ hätte der persönliche Bezug zu diesen, durch die Bewegung der Fahrzeuge auf der in 2 zur Sprache gekommenen Unterlage, seine Wirkung verlieren können. Obwohl also durch die Umsetzung mit Hall-Sensoren eine recht präzise Messung der zuruckgelegten ¨ Distanz möglich gewesen wäre, fiel an dieser Stelle die Entscheidung, auf jedwede Art von Untergrund fur die Fahrzeuge zu verzichten. ¨

## 5 2. Design-Iteration

### 5.1 Fahrzeuge

Um die in 4.4 identifizierten Probleme hinsichtlich des Platzbedarfs zu lösen, wurden die Maße des Fahrzeugs angepasst. Da der erste Eindruck der Beschaffenheit des in Abbildung 4 gezeigten Drucks hinsichtlich seiner Stabilität die anfänglichen Erwartungen
ubertroffen hat, wurden zun ¨ | ächst die zu den Seiten des Fahrzeugs gelegenen Außenwände
der Aussparung in ihrer Stärke halbiert. Weiter wurde das gesamte Modell in der Länge erweitert und der Hohlraum im Fahrzeug so weit wie möglich in diese Richtung ver-
größert. Hierdurch soll zukunftigen Platz-Engp ¨ | ässen vorgebeugt werden.

11

An dieser Stelle wurde ein weiterer Druck durchgefuhrt, um das Zusammenspiel mit Rei- ¨
fen und Befestigung zu prufen. Hierbei wurden alle Einzelteile f ¨ | ur den Druck in einem ¨
einzigen Drucker arrangiert.

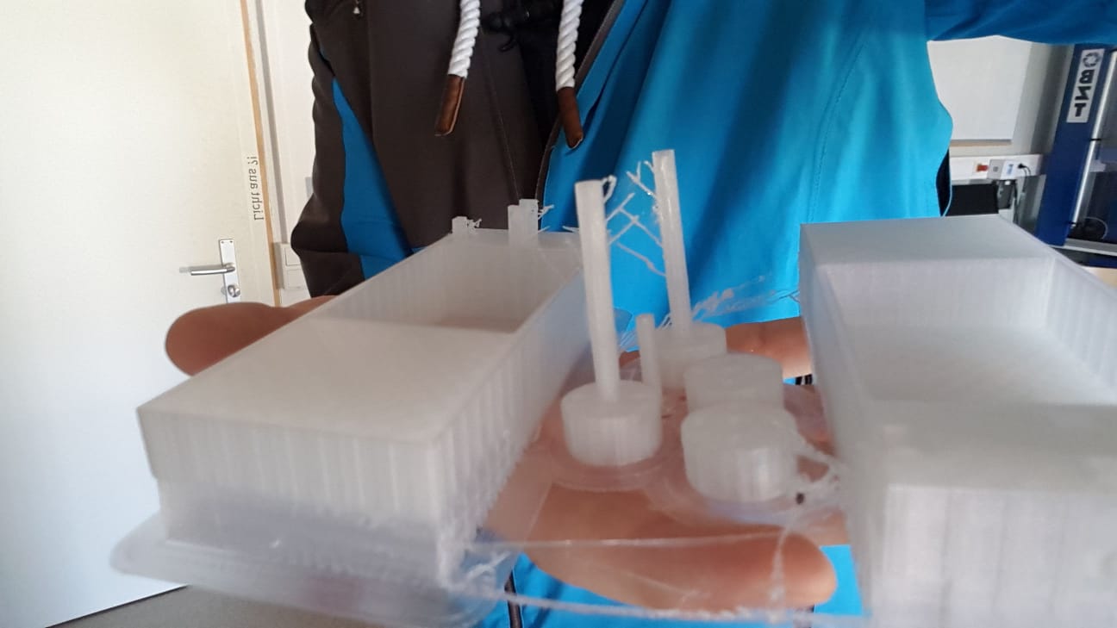
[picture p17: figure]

Abbildung 8: Alle Komponenten eines Fahrzeugs aus einem Druck

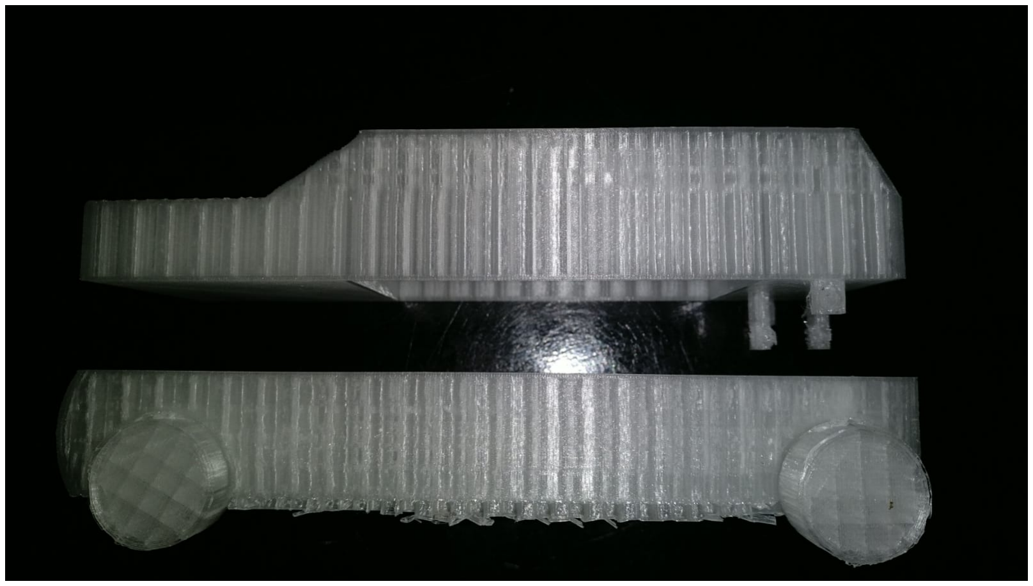
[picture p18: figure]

Abbildung 9: Fahrzeughälften mit montierten Rädern

Während Abbildung 8 das Ergebnis dieses Drucks zeigt, vermittelt Abbildung 9 einen Eindruck von Form und Dimensionen des fertigen Produkts.

12

### 5.2 Hard- und Software

Fahrzeug

Weitere Nachforschungen bezuglich der Fahrzeugschaltung haben ergeben, dass der ¨ | Output
Pin des Hall Sensor mit einem 1k Ω Widerstand an den 3.3V sowie den gewählten IO-Pin angeschlossen werden muss. Das neue Diagramm ist in Abbildung xy dargestellt.
Mit dieser Schaltung funktioniert das Auslesen des Sensors ohne Probleme. Die maximale Distanz, bis zu welcher Magnete erkannt werden können beträgt ca. 1cm. Die Magne-
te mussen sich hierf ¨ | ur direkt vor dem Sensor befinden. Somit ist es m ¨ | öglich, mehrere
Magnete in den Reifen des Fahrzeugs unterzubringen, was eine genauere Messung der
zuruckgelegten Strecke erm ¨ | | öglicht. Zusätzlich werden die LEDs, welche als Scheinwerfer
verwendet werden an je einen eigenen IO-Pin angeschlossen. Somit können diese einzeln angesteuert werden. Diese Eigenschaft wird genutzt um Statusinformationen auszugeben, wie zum Beispiel wenn der Controller sich mit dem Wlan Netzwerk verbindet oder Fehler beim Sendern der Daten auftreten. Somit ist ein leichtes Erkennen von Fehlern möglich, auch wenn das Fahrzeug nicht per USB-Kabel an einen PC angeschlossen ist. Mit der funktionierenden Hardware wird das komplette Programm entworfen. Eine Anderung des Signals vom Hall Sensor wird durch einen Interrupt erkannt. Somit gehen ¨ keine Messerwerte verloren, auch wenn der Arduino eine lange Aktion, wie das Senden von Daten, ausfuhrt. ¨
Der Arduino wartet eine Zeit x ab, welcher von der Konfiguration abhängt. Danach uberpr ¨ uft er, ob das Fahrzeug sich bewegt hat und Messwerte vorliegen. Ist dies der Fall ¨ werden diese in ein JSON Objekt kodiert und anschließend an die Visualisierung gesendet. Liegen mehrere Messwerte vor, werden diese kombiniert. Neben den Messwerten enthalten die Nachrichten zusätzlich den Fahrzeugtyp. Dieser wird fur die Berechnung ¨ der erzeugten Emissionen verwendet.
Zum Senden der Daten wird das integrierte WLAN Modul genutzt. Mit diesem und den erfassten Daten wird ein Post-Request durchgefuhrt. ¨
Ist das Senden erfolgreich, startet der gesamte Prozess von vorne. Verliert der Arduino die Verbindung zum WLAN, versucht er diese wiederherzustellen und zeigt dies durch ein abwechselndes Blinken der LEDs an. In dieser Zeit werden alle vom Sensor erfassten Daten ignoriert. Scheitert der Sendevorgang wird uber die LEDs ein schnelles Blinken ¨ abgegeben und mit dem Programmablauf wird normal fortgefahren.

### 5.3 Darstellung

Die im Zuge der vorangegangenen Iteration erdachte Umsetzung einer abstrakteren Darstellungsweise wurde in diesem Arbeitsschritt vorangetrieben.
Anhand eines ersten Papierprototypen, zu sehen in Abbildung 10, wurde begonnen, das bereits bei der Herstellung der Fahrzeugprototypen gewonnene Wissen auf die Schaffung eines druckfähigen Baummodels anzuwenden.

13

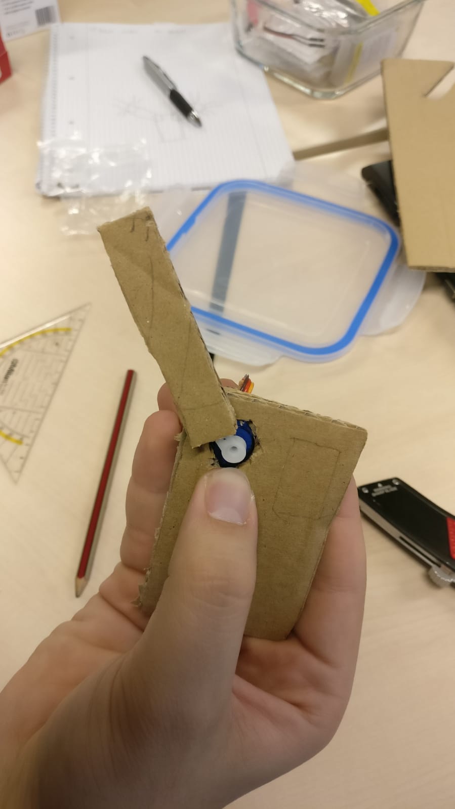
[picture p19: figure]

Abbildung 10: Papierprototyp des Baums

Mit den Maßen der Servomotoren als Referenz wurde mit den Modellierungsarbeiten begonnen. Eben diese Maße fuhrten jedoch dazu, dass die geplante Umsetzung des Baums ¨ zu verhältnismäßig dicken Asten f ¨ uhrt. Die daraus resultierenden Dimensionen, insbe- ¨ sondere in die Tiefe, zeigt Abbildung 11.

14

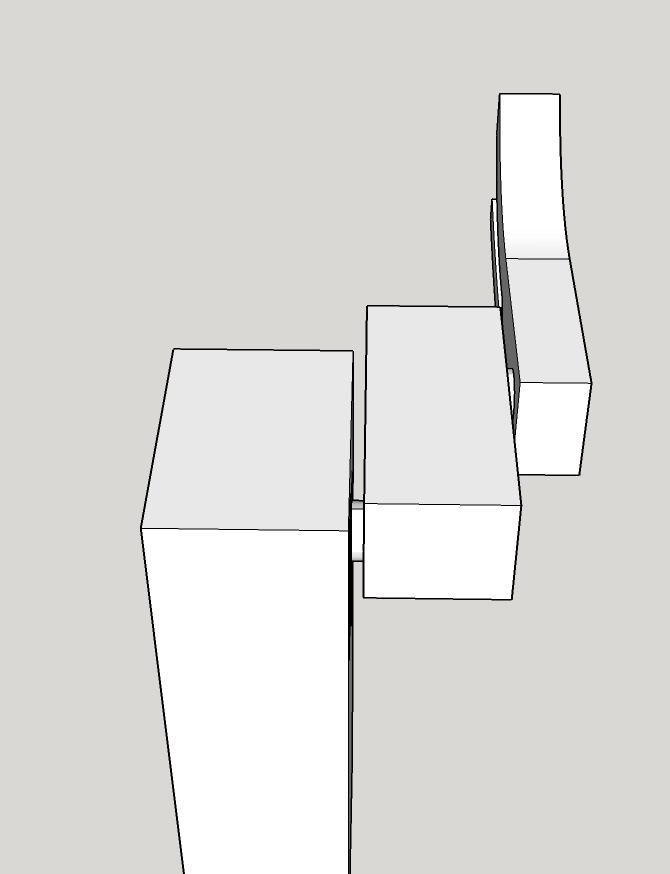
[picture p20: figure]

Abbildung 11: Dimensionen des Baummodels

### 5.4 Ergebnis

Während das in 4 zum Vorschein gekommene Problem des Platzmangels im Fahrzeuginneren gelöst werden konnte, wurde deutlich, dass es nicht möglich ist, wie in 5.1 beschrieben, alle Komponenten in einem Druckvorgang herzustellen. Obwohl die beiden
Hälften des Fahrzeugs mit einer Fullmaterialdichte von 30% eine ausreichende Stabilit ¨ | ät
erreichen, ist dies bei den Achsen und Bolzen zur Befestigung nicht der Fall. Bereits bei der zweiten Montage sind die an den Rädern befindlichen Achsen, wie in Abbildung 12 gezeigt, gebrochen.

15

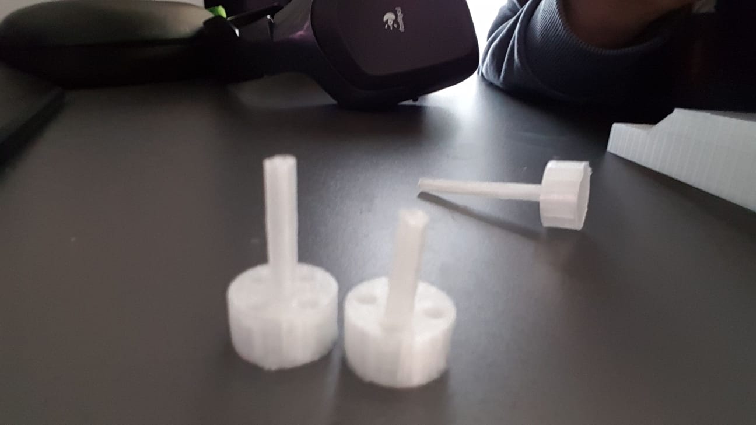
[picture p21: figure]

Abbildung 12: Achsbruch durch Mangel an Fullmaterial ¨

Daruber hinaus konnte auch das Problem des St ¨ | utzmaterials in eigentlich dringend ¨
benötigten Hohlräumen zur Befestigung noch nicht behoben werden. Auch die in 5.3 beschriebene Lösung zur Darstellung der Verschmutzung ist in dieser Form noch nicht zufriedenstellend.

## 6 3. Design-Iteration

### 6.1 Fahrzeuge

Um alle Komponenten so einfach wie möglich montieren zu können, wurden weitere Anpassungen am Modell vorgenommen. Zunächst wurden im Frontbereich Aussparungen fur die LED-“Scheinwerfer“ geschaffen. Hierzu wurde der Durchmesser der LEDs auf- ¨ genommen und in Form von zwei “Tunneln“ durch das Modell eingearbeitet. Mit dem Ziel einen sichereren Halt zu realisiern, wurde dieser Tunnel in etwa hinter der Länge der LEDs verengt. Auf diesem Wege soll eine LED an ihrem Platz bleiben können, während die erforderlichen Kabel trotzdem weiter in das Innere des Fahrzeugs gefuhrt ¨ werden können. Nach dem selben Prinzip wurde daruber hinaus ein Platz zur Montage ¨ des Hall-Sensors im Radkasten geschaffen. Da keine genauen Maße zur Verfugung stan- ¨ den, wurde der Platzbedarf näherungsweise per Hand bestimmt und etwas erweitert, um etwaigen Messfehlern vorzubeugen. Da sich das Problem um die ubereifrige Platzie- ¨
rung von Stutzmaterial durch ¨ | Cura in den vorherigen Iterationen nicht ausmerzen ließ,
sollte dieser Stand des Modells nun zu Evaluationszwecken gänzlich ohne Stutzmaterial ¨ gedruckt werden.

### 6.2 Hard- und Software

Visualisierung

Die erste funktionsfähige Fahrzeugsoftware bildet die Grundlage fur die Implementation ¨
der Visualisierung. Die Basis hierfur ist das Webframework ¨ | Flask. Mit diesem wird eine
REST-Schnittstelle entworfen, welche die gesendeten Fahrzeugdaten empfängt.
In einer Konfigurationsdatei werden die verschiedenen Fahrzeugtypen und die zugehörigen

16

Fahrzeugeigenschaften gespeichert. Die Eigenschaften umfassen eine eindeutige ID, den Namen des Typs, den Radius der Räder, die Anzahl an Magneten in diesen und die verursachte Verschmutzung pro gefahrenem Zentimeter. Somit muss der Programmcode
auch bei zukunftigen ¨ | Anderungen nicht angepasst werden und verschiedene Fahrzeugty- ¨
pen können einfach eingefugt und abgebildet werden. ¨
Wenn ein Fahrzeug sich bewegt, sendet es die Anzahl an erfassten Magnetkontakten und die ID des Fahrzeugs an den Raspberry Pi. Dieser berechnet im ersten Schritt, mithilfe der spezifizierten Werten in der Konfigurationsdatei, die verursachte Verschmutzung. Das Ergebnis wird im zweiten Schritt mit einem Zeitstempel versehen und gespeichert. Da die Messwerte nur wenige Sekunden aktuell sind und keine persistente Speicherung benötigen, wird keine Datenbank aufgesetzt. Die Werte werden lediglich im RAM gespeichert.
Das Programm startet zu Beginn einen weiteren Thread. Dieser ist fur die Steuerung der ¨
Hardwarekomponenten verantwortlich. Hierfur wird alle ¨ | x Sekunden eine Funktion auf-
gerufen. Diese iteriert zuerst uber alle gespeicherten Verschmutzungseintr ¨ | äge und löscht
die veralteten. Hierfur wird die aktuelle Systemzeit und der Zeitstempel des Eintrags ¨ verglichen. Die Gultigkeit von diesen kann in der Konfigurationsdatei angepasst werden. ¨ Danach werden die verbleibenden gultigen Werte addiert und ergeben die gesamte Ver- ¨ schmutzung. Diese wird an die einzelnen Hardware Komponenten weitergeleitet.
Fur die Steuerung der Servo Motoren wird ein PWM Signal verwendet. Mit der zuvor ¨ berechneten Verschmutzung wird die Rotation von diesen bestimmt. Dabei entspricht 0° keiner und 180° der maximalen Verschmutzung.
Fur die LEDs wird der WS2812B LED-Streifen von der Firma Adafruit verwendet. Die- ¨
ser wird uber die dazugeh ¨ | örige Python Bibliothek angesteuert. Je nach Verschmutzung
setzt sich die Farbe aus Grun und Rot zusammen. ¨
Die hierfur verwendet Schaltung ist in Abbildung xy dargestellt. Diese enth ¨ | ält zusätzlich
einen Kondensator und eine Schnittstelle fur eine externe Stromversorgung. Der Kon- ¨ densator soll Schwankungen der Spannung ausgleichen. Das Netzteil wird verwendet, da der Raspberry Pi nicht genug Strom fur die LEDs bereitstellen kann. Mit der vorgestell- ¨ ten Schaltung kann das externe Netzteil zusätzlich den Raspberry Pi uber den 5V Pin ¨
mit Strom versorgen. Somit wird nur ein Netzeil fur alle Komponenten ben ¨ | ötigt.

Fahrzeug

Beim Testen der Visualisierung mit der Fahrzeugschaltung ist ein Problem aufgetreten. Ist das Fahrzeug mit einem USB Kabel an den PC angeschlossen funktioniert die Sensorerkennung. Wird diese nur mit dem Akku betrieben, können keine Sensorwerte erkannt werden.
Beim Ausmessen der verfugbaren Spannung zeigt sich, dass im Betrieb mit dem Akku ¨
nur 3.3V an dem 5V Pin verfugbar sind. Wie in Kapitel 4.2 beschrieben, ben ¨ | ötigt der
Hall-Sensor mindestens 3.7V .
Zum lösen dieses Problems muss die Spannung angehoben werden, was kein triviales Problem ist. Der erste Lösungsansatz ist ein Logic-Level-Converter, welcher zwischen dem Sensor und dem Arduino eingebaut werden kann. Dieser kann Signale in bidirektio-

17 naler Richtung zwischen zwei Spannungen, wie zum Beispiel 5V ←→ 3.3V wandeln. Das Problem hierbei ist, dass an einem Pin des Moduls eine 5V Spannung angelegt werden muss, welche nicht verfugbar ist. ¨
Der zweite Ansatz ist das verwenden eines Step − U pBoost − Converters, mit welchem das Problem erfolgreich gelöst werden kann. Das in Abbildung xy dargestellte Modul wird in diesem Fall verwendet. Dieses akzeptiert eine Eingangsspannung zwischen 2 − 24V und hat eine Ausgangsspannung von 5 − 28V . Die Ausgangsspannung kann mit einem Potentiometer eingestellt werden. Die Schaltung des Fahrzeugs wird mit diesem Modul abgeändert. Die neue Version ist in Abbildung xy dargestellt. Der + und GND Pin des Sensors werden an den Output des Step − U pBoost − Converters angeschlossen, welcher auf 5V eingestellt wird. Die benötigte Eingangsspannung fur das Modul wird vom ¨ 3.3V Pin des Arduinos geliefert. Somit funktioniert die Schaltung sowohl im Betrieb mit einem USB Kabel als auch mit einem Akku.

### 6.3 Darstellung

Da wegen der Dimensionen der Servomotoren keine zufriedenstellende Lösung mit in den Asten integrierten Motoren gefunden werden konnte, wurde ein neues Konzept erarbei- ¨ tet. Während an der Idee, den Baum in einer mit LEDs umrandeten Kiste zu montieren,
festgehalten wurde, sah der neue Ansatz vor, die Aste des Baums ¨ | uber Schn ¨ | ure oder ¨
Ahnliches zu bewegen. Diese sollen idealerweise von oberhalb des Baums, bewegt durch ¨ die Servomotoren, eine marionettenartige Funktionalität herstellen. Der schematische Aufbau dieser Lösung ist in Abbildung 13 dargestellt.

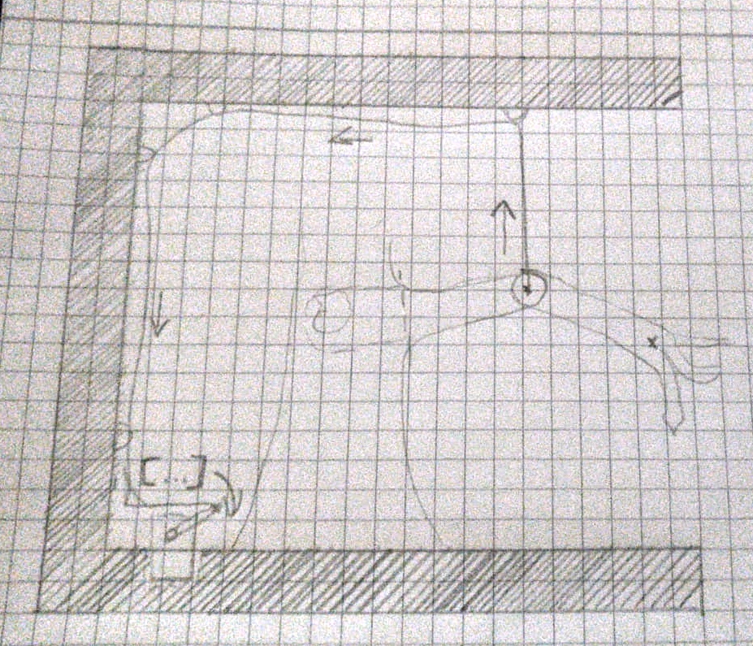
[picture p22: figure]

Abbildung 13: Uberarbeitetes Darstellungskonzept ¨

Aufgrund der Tatsache, dass sich keine geeignete Umsetzung des Baums mittels 3D Druck erzielen ließ, wurde ein Bild einer Baumsilhouette gesucht. Mit diesem war es, ein geeignetes Format vorausgesetzt möglich, einen qualitativ hochwertigen Baum mit

18

Hilfe des Lasercutters des FabLabs herzustellen. Auf dem gleichen Weg war es weiter ein Leichtes, die benötigte Kiste zu realisieren. In Abbildung 14 ist ein erster Eindruck hiervon zu sehen.

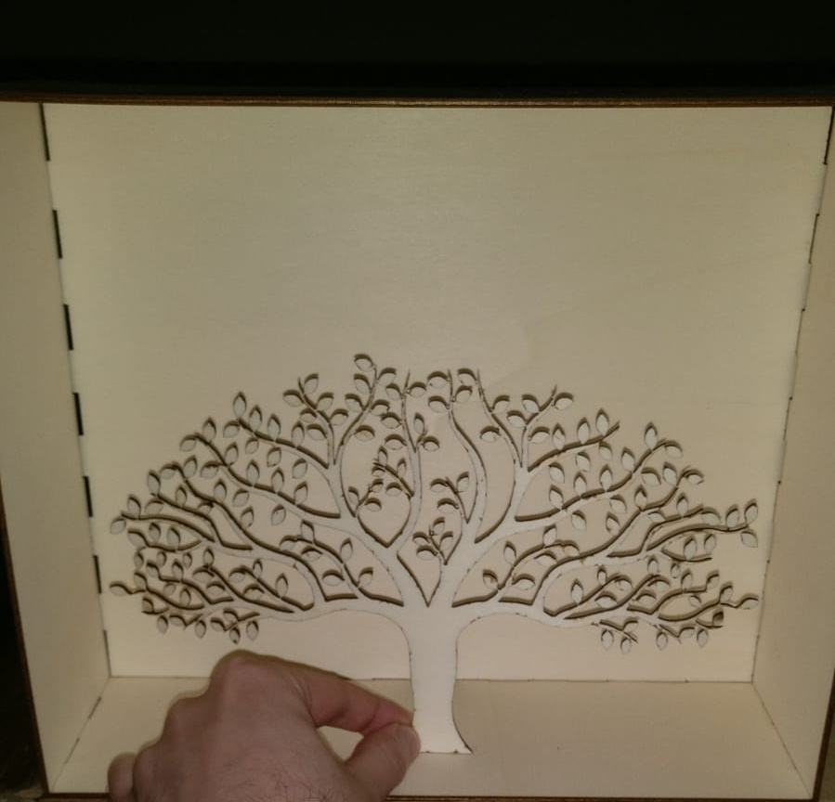
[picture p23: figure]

Abbildung 14: Ausgeschnittener Baum in Kiste

### 6.4 Ergebnis

Obgleich die gewunschten Freir ¨ | äume im Fahrzeuginneren erhalten werden konnten, in-
dem ohne Stutzmaterial gedruckt wurde, ergaben sich hierdurch neue Probleme. Da nun ¨
gar keine Stutzen mehr gesetzt wurden, konnten einige Außenfl ¨ | ächen wie beispielsweise
an der Motorhaube nicht zufriedenstellend gedruckt werden. Auch die Unterseite des Fahrzeugs ist betroffen, wenn auch weniger stark. Beide Stellen sind in Abbildung 15 zu sehen. Des Weiteren wurde deutlich, dass sich durch Zusammenspiel aus modellierten Maßen und den vom Drucker erreichbaren Präzisionsintervallen Aussparungen ergaben, die kleiner als geplant produziert wurden. Hiervon betroffen waren die Scheinwerfer und der Hall-Sensor.

19

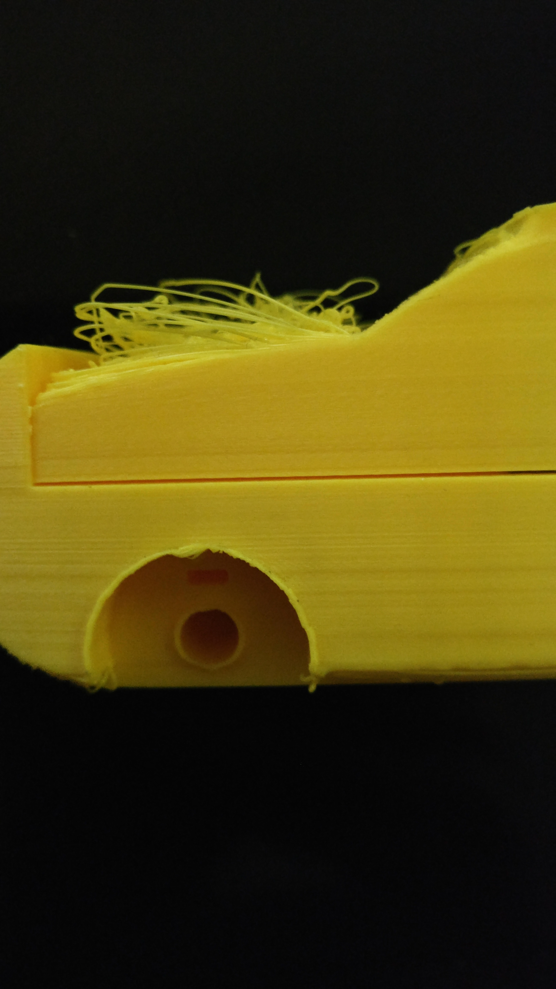
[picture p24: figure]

Abbildung 15: Probleme beim Druck ohne Stutzmaterial ¨

Während der neue Ansatz zur Visualisierung konzeptionell durchaus vielversprechend schien, so konnte mit den in Abbildung 14 gezeigten Bauteilen nicht fortgefahren werden. Sowohl die Box als auch der Baum selbst wurden aus Holzplatten von 3mm Stärke ausgeschnitten. Insbesondere der Baum war auf Grund der Kombination aus filigranen
Blättern und Asten mit dem zu schwach gew ¨ | ählten Material nicht weiter zu verwenden.
Bereits durch den Transport aus den Räumlichkeiten des FabLab verlor er eine Vielzahl
an Blättern. Weiter hätten die Aste geteilt werden m ¨ | ussen, um das in 6.3 vorgestellte ¨
Konzept umzusetzen.
Die Box selbst wurde als zu instabil beurteilt, als dass sie die Montage der Motoren und des Raspberry Pi hätte verkraften können.

20

## 7 4. Design-Iteration

### 7.1 Fahrzeuge

Da die vorangegangene Iteration 6 gezeigt hat, dass auch ohne Stutzmaterial kein zu- ¨ friedenstellendes Ergebnis erzielt werden kann, wurde der Versuch unternommen, ein alternative Befestigungslösung zu erarbeiten. Die dem Druck mit Stutzmaterial zugrun- ¨ de liegende Problematik äußert sich in den horizontal durch das Fahrzeug gefuhrten ¨ Hohlräumen fur die Bolzen. Deshalb wurde der Versuch unternommen, diese nun verti- ¨
kal anzubringen. Daruber hinaus sollte zus ¨ | ätzliche Stabilität in Längsrichtung gewonnen
werden, indem eine Vorrichtung zum “Einhängen“ geschaffen wird. Beides ist in den Abbildungen 16 und 17 zu sehen.

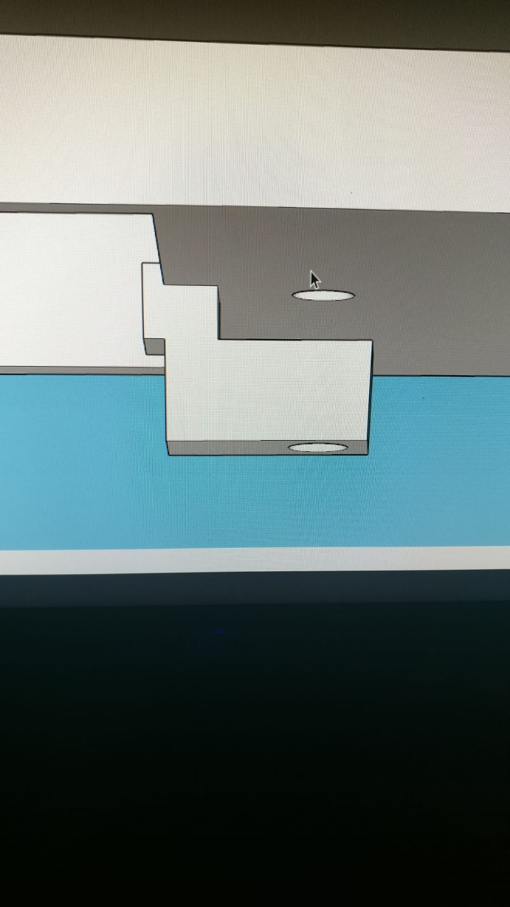
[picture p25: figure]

Abbildung 16: Neues Befestigungskonzept (obere Hälfte)

21


Abbildung 17: Neues Befestigungskonzept (untere Hälfte)

Außerdem wurden die Aussparungen fur Scheinwerfer und Hall-Sensor erweitert, um ¨ umständlichen Berechnungen und Probedrucken entgegen zu wirken.

### 7.2 Hardware

Visualisierung

Der Programmcode und die benötigte Hardware fur die Visualisierung funktionieren be- ¨ reits, trotzdem mussen noch kleine Optimierungen vorgenommen werden. Zuerst wird die ¨ Funktionsweise des LED-Streifens uberarbeitet. Zuvor haben alle LEDs dieselbe Farbe ¨
angezeigt, welche sich aus Rot und Grun zusammensetzt. Die Farbe Gr ¨ | un ist viel domi- ¨
nanter, sodass die LEDs auch bei mittlerer Verschmutzung noch die Farbe grun anzeigen. ¨ Erst bei starker Verschmutzung färben sie sich orange und danach rot. Mit der neuen

22

Implementierung zeigen die LEDs unterschiedliche Werte an. Je nach Verschmutzungsgrad färbt sich ein Teil der LEDs rot (Abbildung xy). Ist die maximale Verschmutzung erreicht, sind alle LEDs rot. Hierdurch wird die gesamte Verschmutzung eindeutig dargestellt
Im nächsten Schritt wird noch eine Platine fur den Raspberry Pi erstellt. Diese kann wie ¨ ein Shield auf die Pins gesteckt werden und die Servo Motoren sowie der LED-Streifen können direkt angeschlossen werden. Dies reduziert die Anzahl an benötigten Kabeln und erhöht die Ubersichtlichkeit. ¨
Zuletzt wird die Konfiguration des Raspberry Pi uberarbeitet. Der Flask-Webserver soll ¨ automatisch mit jedem hochfahren des Systems gestartet werden. Somit muss, wie auch bei den Fahrzeugen, nur die Stromversorgung hergestellt werden, um den Prototypen zu benutzen.

Fahrzeug

Fur die voll funktionsf ¨ | ähige und getestete Schaltung muss eine Prototyp Platine erstellt
werden. Die Basisplatine hat dieselbe Größe wie der Arduino. Somit kann die fertige Platine wie ein Shield auf den Arduino gesteckt werden und verbraucht wenig Platz. Allerdings muss das Layout wegen der begrenzten Größe vorher geplant werden. Eine Skizze hierfur ist in Abbildung xy dargestellt. Die fertige Platine kann auf den Arduino ¨ gesteckt werden, welcher zusammen mit dem Akku, dem Step − U pBoost − Converter, dem Sensor und den LEDs in das Auto eingebaut wird. Zusätzlich ermöglicht ein Schalter das einfache an- beziehungsweise ausschalten der Batterie.
Alle Verbindungen zwischen den Komponenten sind mit JST-Steckern realisiert. Dies ermöglicht es, jede Komponente einzeln austauschen, sollte ein Teil defekt sein oder fur ¨ ein anderes Projekt wiederverwendet werden. Zudem wird so das Zusammensetzen der Fahrzeuge erleichtert, da einige Komponenten wie die LEDs fest in diesen verklebt sind. Zuletzt wird noch die Konfiguration der Fahrzeuge optimiert. Zuvor haben diese jede Sekunde 1 mal die erfassten Sensordaten gesendet. Da die durchschnittliche Ausfuhrungszeit ¨ der loop-Funktion bei ca. 100ms liegt, wird dieser Wert auf 250ms Sekunden reduziert. Die Fahrzeuge senden häufiger Daten und die Animation bei der Visualisierung werden infolgedessen weicher.

### 7.3 Darstellung

Aufbauend auf den in 6 gewonnenen Erkenntnissen wurden ein neuer Baum und eine neue Box aus 6mm dickem Holz ausgeschnitten. Obgleich auch hier wieder einige Blätter verloren gingen, war das Resultat weitaus stabiler und wurde fur die folgenden Monta- ¨ geschritte als geeignet befunden.
Das in 13 gezeigte Konzept sah noch eine Montage der Servomotoren hinter dem Baum, am Boden der Kiste vor. Um die Bewegung einfacher umsetzen zu können und die Montage des Raspberry Pis im Inneren zu erleichtern, wurde aus Holzresten des FabLab eine
Art Zwischenboden uber dem Baum geschaffen. Die Aufh ¨ | ängung der Aste soll auf diesem ¨
Weg ohne weitere Umwege am Rand der Box realisiert werden können.

23

### 7.4 Ergebnis

Mit den in 7.1 vorgenommenen Anderungen am Modell konnte zwar gen ¨ | ugend Platz f ¨ | ur ¨
die Montage der kleineren Komponenten geschaffen werden, jedoch musste nun mit einer Klebepistole nachgeholfen werden, um einen sicheren Halt der Bauteile zu gewährleisten. Auch wenn die vertikale Anordnung der Befestigung die Problematik um das Stutzmaterial ¨ lösen konnte, wurde der Mangel an Fullung, der in Abbildung 16 gezeigten Vorrichtung, ¨ bei der Montage zum Verhängnis. Da eine Erhöhung der Fulldichte bei den ohnehin ¨ schon größeren Fahrzeughälften die Druckzeit unverhältnismäßig verlängert hätte und die vorgesehenen Schächte fur die Bolzen einwandfrei waren, wurde eine rustikalere Form ¨ der Befestigung gewählt. In den Räumen der Analog-Werkstatt des FabLab fanden sich geeignete Werkzeuge. Nach kurzer Recherche nach den genauen Maßen wurden die bereits vorhandenen Löcher in der unteren Hälfte und die eigentlich fur Bolzen vorgesehe- ¨ nen Schächte mittels eines Bohrers erweitert. In die untere Hälfte wurden nun fur M3 ¨ Schrauben passende Muttern eingearbeitet. Unter Zuhilfenahme eines Hammers und der Heißklebepistole konnten diese fest mit dem Druck vereint werden. Mittels den Maßen
des Fahrzeugs entsprechend gekurzten Schrauben war es nun m ¨ | öglich, die Hälften sicher
zu vereinigen.
Abbildung 18 zeigt das Ergebnis all dieser Arbeitsschritte. Auch die transparenten Plastik-Muttern sind hier zu erkennen.

24


Abbildung 18: Befestigung mit konventionellen Mitteln

Da das erste Fahrzeug die gestellten Anforderungen erfullt, wurde ein weiteres in Form ¨ eines Busses hergestellt. Hierzu war es ausreichend, die äußere Form des Modells zu bearbeiten und einige Details hinzuzufugen, die den Wiedererkennungswert steigern. ¨ Hinsichtlich der Befestigung wurde jedoch gleich auf die oben ausgefuhrte Methode mit ¨ Schrauben und Muttern gesetzt.
Auch die stabileren Ausfuhrungen von Baum und Box konnten nun montiert werden. ¨ Zunächst wurden die Aste des Baums an ihren jeweils dicksten Stellen mit einer feinen ¨ Holzsäge getrennt. An beiden so entstandenen Verbindungsstellen wurden mit einem Bohrer Löcher geschaffen, die in ihrem Durchmesser leicht uber die Maße einer M3- ¨ Schraube hinaus gehen. Solche Schrauben wurden nun durch die Löcher gefuhrt und ¨
die Aste mit Muttern in Position gebracht. Auf diese Weise konnten die ¨ | Aste beweglich ¨
gemacht werden.
Der Baum selbst wurde mit Hilfe eines einfachen Winkels an seiner endgultigen Position ¨ fixiert.
Auf die gleiche Weise wurde der in 7.3 erdachte Zwischenboden montiert. Im Anschluss konnten die Servomotoren hier angebracht werden. Um diese etwas kostspieligeren Komponenten wiederverwendbar zu halten, kam erneut die Klebepistole zum Einsatz.
Die Verbindung zwischen den Servomotoren und den Asten, die sie bewegen sollen, ¨

25

ubernahm konventioneller Faden, auch wenn die Befestigung ¨ | uber Knoten unerwartet ¨
zeitintensiv war. Der Grund hierfur war, dass es sich schwierig gestaltete, ein Gleichge- ¨ wicht zwischen erforderlichem Halt und optisch ansprechender Anfangs- sowie Endposition zu finden.
Weiter fand die Steuerung der Visualisierung ihren Platz auf Abstandhaltern auf dem Zwischenboden, welche ebenfalls mit Schmelzkleber fixiert wurden. In die Außenwand der Kiste wurde auf dieser Höhe ein Loch gebohrt, um die Stromversorgung ins Innere
fuhren zu k ¨ | önnen. Abschließend wurde der LED-Streifen um den Baum herum montiert,
wobei statt der oberen Hulle der Box nun die Unterseite des Zwischenbodens gew ¨ | ählt
wurde. Auch hier konnte sicher gestellt werden, dass das Bauteil erneut verwendbar ist, indem die Befestigung mit doppelseitigem Klebeband realisiert wurde.
Um den Fokus des Betrachters nicht vom Baum abzulenken, wurde weiter eine Blende installiert, welche die Vorgänge auf dem Zwischenboden verbirgt.

26

## 8 Fazit

Der im Zuge der vier genannten Iterationen entwickelte und geschaffene Prototyp wird nachfolgend mit Bezug auf die Projektidee bewertet. Mit den beiden Fahrzeugen ist eine anfassbare Schnittstelle zum System realisiert worden. Die Fahrzeuge sind mittels 3D-Druck hergestellt und mit je einem Arduino ausgestattet. Hierdurch ist die drahtlose Kommunikation mit dem dahinterstehenden System möglich. Die Kombination aus der verwendeten Hardware und dem Herstellungsprozess der Fahrzeuge ermöglicht es, den gewunschten Formfaktor zu erreichen. Trotz der verbauten Hardware sind die Fahrzeuge ¨ leicht und können auch von Kindern in eine Hand genommen und bedient werden. Zur Inbetriebnahme muss lediglich die Stromversorgung der Fahrzeuge mittels eines Schalters hergestellt werden. Die Arduinos sind so programmiert und konfiguriert, dass sie automatisch die Kommunikation mit dem dahinterliegenden System aufnehmen.
Dieses System ubernimmt Empfang und Verarbeitung der ¨ | ubermittelten Daten sowie ¨
die Koordination der Darstellung. Obwohl die ursprungliche Idee der Verwendung eines ¨ Displays verworfen werden musste, wird eine gleichwertige Darstellung auf Basis eines beweglichen Baums erzielt. Auch wenn es so nicht mehr möglich ist, genaue Messwerte anzuzeigen, wird der Umwelteinfluss verschiedener Fahrzeugtypen deutlich. Dieser Eindruck wurde durch den Kontakt mit projektfremden Personen, unter anderem im FabLab, bestätigt. Wie zuvor bei den Fahrzeugen auch, muss fur den Betrieb lediglich ¨ der Raspberry Pi mit Strom versorgt werden.
Abschließend lässt sich festhalten, dass die zu Beginn formulierte Idee trotz angefallener Anderungen erfolgreich umgesetzt werden konnte. Die Komponenten des Gesamtsystems ¨ interagieren reibungslos miteinander und können den gewunschten Lerneffekt bieten, be- ¨ ziehungsweise damit zu einer Verhaltensänderung anregen.

### 8.1 Ausblick

Da im Rahmen der Veranstaltung auf Grund der begrenzten Zeit und Ressourcen nur die Entwicklung eines einfachen Prototypen möglich ist, werden im Folgenden etwaige Erweiterungen und Optimierungen vorgestellt.

- Anpassung des SUV-Modells:
Das erste SUV-Fahrzeugmodell diente nur zum Herstellen der Funktionalität. Deshalb wurde auf eine detailreiche Modellierung verzichtet. Vor einem weiteren Druck des Modells sollte es uberarbeitet werden. ¨
- Weitere Fahrzeugtypen:
Da die fur die Funktion erforderliche Elektronik einen fest definierten Platzbedarf ¨ hat, können weitere Fahrzeuge einfach erstellt werden. Hierzu muss lediglich die äußere Form angepasst und auf dem Arduino der Fahrzeugtyp hinterlegt werden.
- Baum:
Fur den Baum wurde eine Vorlage aus dem Internet verwendet. F ¨ | ur einen lang- ¨

27 fristigen Einsatz sollte eine auf den Anwendungskontext zugeschnittene Version erstellt werden.

- Kiste fur den Baum ¨ | :
Fur eine einfachere Montage und ein stimmigeres Gesamtbild kann die Kiste mit ¨ Aussparungen und Einbauhilfen fur die Komponenten ausgestattet werden. Somit ¨ sind keine manuellen Anpassungen mehr nötig.
- Display:
Mit weiteren finanziellen Mitteln kann die Darstellung, entsprechend dem ursprunglichen Konzept, um ein Display erweitert werden. ¨
- Unterlage:
Mit dem Hall-Sensor kann die gefahrene Strecke sehr genau ermittelt werden. Stunden eine maßstabsgetreue Karte als Unterlage und das oben genannte Display ¨
zur Verfugung, k ¨ | önnten gefahrene Strecken und deren Emissionen genau berechnet
und abgebildet werden.
- Platine:
Da die manuelle Fertigung der Platinen sehr aufwändig ist, sollten diese bei größeren Produktionsmengen professionell hergestellt werden.

28

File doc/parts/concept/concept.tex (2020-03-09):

% !TeX spellcheck = de_DE
\documentclass[.../Dokumentation.tex]{subfiles}
\begin{document}
\section{Konzept}\label{sec-concept}
Im Folgenden soll nun umrissen werden, wie die in \ref{sec-intr-idea} 
formulierte Idee zu realisieren ist.
Als Kontaktpunkt des Nutzers mit dem System sollen eines oder mehrere 
der erwähnten Fahrzeuge eingesetzt werden. Diese sollen per Hand bewegt werden. 
Im Kontrast hierzu stünde eine Umsetzung, in der die Fahrzeuge zum Beispiel mit 
Hilfe einer App und entsprechender Technik ferngesteuert werden können.
Diese Wahl soll zum einen eine einfachere, vor allem aber auch kostengünstigere 
Umsetzung ermöglichen und zum Anderen ein intuitiveres Bedienerlebnis bieten.
Um hierauf aufzubauen und den thematischen Schwerpunkt des Klimapakts Flensburg 
aufzugreifen, wird die Möglichkeit in Betracht gezogen, anstelle 
eines generischen Teppichs eine maßstabsgetreue Darstellung der Flensburger 
Innenstadt sowie eventuell des Umlands zu verwenden.
Auf diesem Wege wäre es weiter möglich, die Konsequenzen auch kürzerer Fahrten 
zu verdeutlichen.
Die Darstellung mittels des Displays könnte neben aufbereiteten Zahlen weiter 
um eine Repräsentation der Emissionen in weniger abstrakter Form wie eine 
Menge an bestimmten Lebensmitteln, deren Produktion und Transport gleiche Werte 
verursachen, ergänzt werden.
\end{document}

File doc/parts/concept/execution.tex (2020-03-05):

\documentclass[.../Dokumentation.tex]{subfiles}
\begin{document}
\subsection{Umsetzung}\label{sec-concept-execution}
Um die Anforderungen an die Fahrzeuge erfüllen zu können, wurde 
einerseits evaluiert, fertige Spielzeugautos zu erwerben und um die 
elektronischen Komponenten zu erweitern, die zur Messung der zurückgelegten 
Distanz und der Kommunikation benötigt werden. Allerdings hätte sich vorab 
nicht ohne Zweifel sagen lassen können, ob der für diese Erweiterungen 
erforderliche Platz vorhanden ist oder sich schaffen lässt, ohne das Auto 
seiner Funktion zu berauben. 
Andererseits bestand die Option, die Fahrzeuge von 
Grund auf selbst herzustellen. 
Auf diese Weise kann sichergestellt werden, 
dass genug Platz für die erforderliche Technik vorhanden ist.
An dieser Stelle ensteht jedoch ein Konflikt zwischen dem Platzbedarf der zu 
ermittelnden Komponenten und 
einem der Projektidee entsprechenden Formfaktor der Fahrzeuge.
Weiter sollen die Fahrzeuge in einer Form geschaffen werden, die es erlaubt, 
ohne weitere Konfiguration "loszufahren", sobald eine initiale, 
gleichsam werksseitige, Konfiguration durchgeführt wurde und die 
Stromversorgung hergestellt ist. 
Die Stromversorgung der Fahrzeuge soll mit Hilfe von Akkus umgesetzt werden, 
damit keine Kabel etwaiger Netzteile bei den Bewegungen der Fahrzeuge 
berücksichtigt werden müssen oder diese gar behindern.
Ein Verzicht auf Kabel soll auch in der Kommunikation der Fahrzeuge mit 
der Steuerung der Darstellung gewahrt bleiben.
Hierdurch entsteht die Anforderung, beide Seiten des Systems mit solchen 
Bauteilen auszustatten, die eine drahtlose Kommunikation erlauben.
Die erforderlichen Komponenten sollen so gewählt und installiert werden, 
dass eine Wartung ohne unverhältnismäßigen Aufwand möglich ist. Weiter soll 
durch die Durchführung der Montage gewährleistet werden, dass kostspieligere 
Bauteile entfernt und anderweitig erneut eingesetzt werden können.
\end{document}

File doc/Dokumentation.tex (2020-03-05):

\documentclass[a4paper, 11pt]{article}
\usepackage{float}
\usepackage{amsmath,amssymb,amsfonts}
\usepackage{algorithmic}
\usepackage{graphicx}
\usepackage{textcomp}
\usepackage{xcolor}
\usepackage{float}
\usepackage{amsthm}
\usepackage{geometry} 
\usepackage{pgfplots}
\usepackage{tikz}
\usepackage{listings}
\usepackage{authblk}
\usepackage{import}
\usepackage{subfiles}
\usepackage{hyperref}
\usepackage[ngerman]{babel}
\usepackage{gensymb}

\lstloadlanguages{Python}
\definecolor{bluekeywords}{rgb}{0,0,1}
\definecolor{greencomments}{rgb}{0,0.5,0}
\definecolor{redstrings}{rgb}{0.64,0.08,0.08}
\definecolor{xmlcomments}{rgb}{0.5,0.5,0.5}
\definecolor{types}{rgb}{0.17,0.57,0.68}

\lstset{language=Python,
    captionpos=b,
    frame=lines,
    showspaces=false,
    showtabs=false,
    breaklines=true,
    showstringspaces=false,
    breakatwhitespace=true,
    escapeinside={(*@}{@*)},
    commentstyle=\color{greencomments},
    morekeywords={partial, var, value, get, set},
    keywordstyle=\color{bluekeywords},
    stringstyle=\color{redstrings},
    basicstyle=\ttfamily\small,
}
\begin{document}
\pagenumbering{arabic}
\begin{titlepage}
    \begin{center}
        \vspace{3cm}
        {\LARGE\bfseries Hochschule Flensburg \par}
        \vspace{1.5cm}
        {\huge\bfseries SmartCars\par}
        \vspace{0.5cm}
        {\LARGE\bfseries Maker's Lab - Things that Think \par}
        \vspace{0.25cm}
        {\LARGE Abschlussbericht\par}
        \vspace{2cm}
        {\Large vorgelegt von: \par}
        \vspace{1cm}
        {\bfseries Simon Hauck \hfill \bfseries Nils Jensen\par}
        { 660158 \hfill  670758\par}
        { Hochschule Flensburg \hfill Hochschule Flensburg \par}
        { simon.hauck@stud.hs-flensburg.de \hfill  nils.jensen2@stud.hs-flensburg.de\par}
        \vfill
        \vfill
    % Bottom of the page
        {\large \today\par}
    \end{center}
\end{titlepage}
    \clearpage
    \thispagestyle{empty}
    \tableofcontents
    \pagebreak
    % Einleitung
    \subfile{parts/introduction/introduction.tex}    
        % Motivation
        \subfile{parts/introduction/motivation.tex}
        % Projektidee (Schwammprototyp)
        \subfile{parts/introduction/idea.tex}
    \pagebreak
    % Konzept
    \subfile{parts/concept/concept.tex}
        % Umsetzung
        \subfile{parts/concept/execution.tex}
        % etc
        % TODO maybe
    \pagebreak
    % Komponenten
    \subfile{parts/components/components.tex}
        % Hardware
        \subfile{parts/components/hardware.tex}
        % Software
        \subfile{parts/components/software.tex}
        % Werkzeuge
        %\subfile{parts/components/tools.tex}
    % 1. Iteration                          flieder
    \subfile{parts/iteration1/iteration.tex}
        % Auto
        \subfile{parts/iteration1/cars.tex}
        % Elektronik
        \subfile{parts/iteration1/hardware.tex}
        % Software
        %\subfile{parts/iteration1/software.tex}
        % Darstellung 
        \subfile{parts/iteration1/visualization.tex}
        % Lessons Learned / Ergebnis
        \subfile{parts/iteration1/iteration_result.tex}
    % 2. Iteration                          transparent
        \subfile{parts/iteration2/iteration.tex}
        % Auto
        \subfile{parts/iteration2/cars.tex}
        % Elektronik
        \subfile{parts/iteration2/hardware.tex}
        % Software
        %\subfile{parts/iteration2/software.tex}
        % Darstellung 
        \subfile{parts/iteration2/visualization.tex}
        % Lessons Learned / Ergebnis
        \subfile{parts/iteration2/iteration_result.tex}
    % 3. Iteration                          gelb
    \subfile{parts/iteration3/iteration.tex}
        % Auto
        \subfile{parts/iteration3/cars.tex}
        % Elektronik
        \subfile{parts/iteration3/hardware.tex}
        % Software
        %\subfile{parts/iteration3/software.tex}
        % Darstellung 
        \subfile{parts/iteration3/visualization.tex}
        % Lessons Learned / Ergebnis
        \subfile{parts/iteration3/iteration_result.tex}
    % 4. Iteration                          gemischt
    \subfile{parts/iteration4/iteration.tex}
        % Auto
        \subfile{parts/iteration4/cars.tex}
        % Elektronik
        \subfile{parts/iteration4/hardware.tex}
        % Software
        %\subfile{parts/iteration4/software.tex}
        % Darstellung 
        \subfile{parts/iteration4/visualization.tex}
        % Lessons Learned / Ergebnis
        \subfile{parts/iteration4/iteration_result.tex}
    % Ergebnis
    \newpage
    \subfile{parts/result/result.tex}
    % Ausblick 
    \subfile{parts/outlook/outlook.tex}
\end{document}

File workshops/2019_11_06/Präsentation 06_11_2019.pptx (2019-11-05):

## Smart Cars

Gruppe Müllteppich

## Fahrzeuge - Stand


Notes: Nils

## Fahrzeuge - Stand


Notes: Nils

## Baum - Stand


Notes: Nils

## Baum - Stand


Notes: Nils

## Schaltplan - Stand


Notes: Simon

## Schaltplan - Stand


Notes: Simon

## Next Steps

- Auto anpassen
- Baum Konzept 2.0
- 2. Auto
- Kompletter Autodruck (2. Hälfte, Räder, Befestigungsbolzen, ..)
- Arduino Optimierungen

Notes: Simon

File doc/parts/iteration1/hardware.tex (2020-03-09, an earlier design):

% !TeX spellcheck = de_DE
\documentclass[.../Dokumentation.tex]{subfiles}
\begin{document}
\subsection{Hard- und Software}
\label{sec-ita1-hardware}

\subsubsection*{Fahrzeug}
Nachdem die Hardware eingetroffen ist, soll in einem ersten Schritt 
die Funktionalität des Hall-Sensors testweise implementiert werden. Das Ziel 
ist herauszufinden, bis zu welchem Abstand der Sensor die Magneten erkennt und 
ob der Einsatz von mehreren Magneten in den Reifen möglich ist. Für den Sensor 
steht nur Dokumentation im Rahmen eines Datenblattes zur Verfügung. Hierbei erweist es sich als schwierig, die Bedeutung der drei Pins zu 
erkennen. Letztendlich stellt sich heraus, dass der linke Pin $+$, der 
mittlere \textit{GND} und der rechte das $Output$ Signal ist.\\
Beim Erstellen der Schaltung entsteht ein weiteres Problem. Der Sensor benötigt für den Betrieb mindestens $3.7V$. Somit muss der $+$-Pin an den $5V$ Pin des 
Arduinos angeschlossen werden. Der $Output$-Pin liefert dementsprechend auch $5V$ und muss mit einem IO-Pin des Arduinos verbunden werden, damit das 
Signal von diesem eingelesen werden kann. Laut Datenblatt dürfen an die Pins maximal $3.3V$ angelegt werden, ansonsten droht eine Beschädigung des Arduinos.
\begin{figure}[H]
\begin{center}
    \includegraphics[
    width=0.5\linewidth,
    ]{imgs/hardware_car_iteration1.png}
    \caption{Erstes Konzept des Schaltplans für die Fahrzeuge}
    \label{fig-hardware-car-iteration1}
\end{center}
\end{figure}
\noindent
Mit einem Spannungsteiler, bestehend aus einem $1k\ \Omega$ und einem $2k\ \Omega$ Widerstand, können $5V$ 
auf $3.3V$ runter-gesetzt werden. Zusätzlich soll ein 
$10k\ \Omega$ Pull-Up Widerstand verwendet werden, welcher den verwendeten Pin 
des Arduinos auf \textit{HIGH} setzt, solange kein Magnet erkannt ist. Die verwendete Schaltung ist in Abbildung \ref{fig-hardware-car-iteration1} dargestellt. 
Hierbei werden zusätzlich zwei LEDs hinzugefügt, welche später als Scheinwerfer im Fahrzeug verwendet werden. 
\end{document}

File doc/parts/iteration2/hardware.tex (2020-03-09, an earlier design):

% !TeX spellcheck = de_DE
\documentclass[.../Dokumentation.tex]{subfiles}
\begin{document}
    \subsection{Hard- und Software}\label{sec-ita2-hardware}
    \subsubsection*{Fahrzeug}
    Weitere Nachforschungen bezüglich der Fahrzeugschaltung haben ergeben, dass der $Out\-put$-Pin des Hall-Sensor mit einem $1k\ \Omega$  Widerstand an den $3.3V$- sowie den gewählten IO-Pin angeschlossen werden muss. Das neue Diagramm ist in Abbildung \ref{fig-hardware-car-iteration2} dargestellt.
       	\begin{figure}[H]
    	\begin{center}
    		\includegraphics[
    		width=0.7\linewidth,
    		]{imgs/hardware_car_iteration2.PNG}
    		\caption{Schaltung für die Fahrzeuge in der zweiten Iteration }
    		\label{fig-hardware-car-iteration2}
    	\end{center}
    \end{figure}
    \noindent
    Mit dieser Schaltung funktioniert das Auslesen des Sensors ohne Probleme. Die maximale Distanz, bis zu welcher Magnete erkannt werden können, beträgt ca. $1 cm$. Die Magnete müssen sich hierfür direkt vor dem Sensor befinden. Somit ist es möglich, mehrere Magnete in den Rädern des Fahrzeugs unterzubringen, was eine genauere Messung der zurückgelegten Strecke ermöglicht. Zusätzlich werden die LEDs, welche als Scheinwerfer verwendet werden an, je einen eigenen IO-Pin angeschlossen. Somit können diese einzeln angesteuert werden. Diese Eigenschaft wird genutzt, um Statusinformationen auszugeben, zum Beispiel wenn der Controller sich mit dem WLAN Netzwerk verbindet oder Fehler beim Senden der Daten auftreten. Somit ist ein leichtes Erkennen von Fehlern möglich, auch wenn das Fahrzeug nicht per USB-Kabel an einen Computer angeschlossen ist. 
    Mit der funktionierenden Hardware wird das komplette Programm entworfen. Eine Änderung des Signals vom Hall-Sensor wird durch einen \emph{Interrupt} erkannt. Somit gehen keine Messwerte verloren, auch wenn der Arduino eine andere Funktion wie das Senden von Daten ausführt. Der Arduino wartet eine Zeit $x$ ab, welche von der Konfiguration abhängt. Danach überprüft er, ob das Fahrzeug sich bewegt hat und Messwerte vorliegen. Ist dies der Fall, werden die Daten in ein JSON-Objekt kodiert und anschließend an die Visualisierung gesendet. Liegen mehrere Messwerte vor, werden diese kombiniert. Neben den Messwerten enthalten die Nachrichten zusätzlich den Fahrzeugtyp, welcher für die Berechnung der erzeugten Emissionen verwendet wird. Zum Senden der Daten wird das integrierte WLAN-Modul genutzt, welches einen \emph{Post-Request} durchführt. 
   	Ist das Senden erfolgreich, startet der gesamte Prozess von vorne. Verliert der Arduino die Verbindung zum WLAN, versucht er diese wiederherzustellen und zeigt dies durch ein abwechselndes Blinken der LEDs an. In dieser Zeit werden alle vom Sensor erfassten Daten ignoriert. Scheitert der Sendevorgang, wird über die LEDs ein schnelles  Blinken abgegeben und mit dem Programmablauf wird normal fortgefahren. 

\end{document}

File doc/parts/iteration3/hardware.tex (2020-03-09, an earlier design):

% !TeX spellcheck = de_DE
\documentclass[.../Dokumentation.tex]{subfiles}
\begin{document}
    \subsection{Hard- und Software}
    \label{sec-ita3-hardware}
    \subsubsection*{Visualisierung}
    Die erste funktionsfähige Fahrzeugsoftware bildet die Grundlage für die Implementation der Visualisierung. Die Basis hierfür ist das Webframework \emph{Flask}. Mit diesem wird eine REST-Schnittstelle entworfen, welche die gesendeten Fahrzeugdaten empfängt. \\
    In einer Konfigurationsdatei werden die verschiedenen Fahrzeugtypen und die zugehöri\-gen Fahrzeugeigenschaften gespeichert. Die Eigenschaften umfassen eine eindeutige ID, den Namen des Typs, den Radius der Räder, die Anzahl an Magneten in diesen und die verursachte Umweltverschmutzung pro gefahrenem Zentimeter. Somit muss der Programmcode auch bei zukünftigen Änderungen nicht angepasst werden und verschiedene Fahrzeugtypen können einfach eingefügt und abgebildet werden. Wenn ein Fahrzeug sich bewegt, sendet es die Anzahl an erfassten Magnetkontakten und die ID des Fahrzeugs an den Raspberry Pi. Dieser berechnet im ersten Schritt mithilfe der spezifizierten Werten in der Konfigurationsdatei die verursachte Umweltverschmutzung. Das Ergebnis wird im zweiten Schritt mit einem Zeitstempel versehen und gespeichert. Da die Messwerte nur wenige Sekunden aktuell sind und keine persistente Speicherung benötigen, wird keine Datenbank aufgesetzt. Die Werte werden lediglich im RAM gespeichert.\\
    Das Programm startet zu Beginn einen weiteren Thread. Dieser ist für die Steuerung der Hardware-Komponenten verantwortlich. Hierfür wird alle $x$ Sekunden eine Funktion aufgerufen. Diese iteriert zuerst über alle gespeicherten Verschmutzungseinträge und löscht die veralteten. Hierfür wird die aktuelle Systemzeit und der Zeitstempel des Eintrags verglichen. Die Gültigkeit von diesen kann in der Konfigurationsdatei angepasst werden. Danach werden die verbleibenden, gültigen Werte addiert und ergeben die gesamte Verschmutzung. Diese wird an die einzelnen Hardware Komponenten weitergeleitet. Für die Steuerung der Servo Motoren wird ein PWM Signal verwendet. Mit der zuvor berechneten Verschmutzung wird die Rotation von diesen bestimmt. Dabei entspricht $0 \degree$ keiner und $180 \degree$ der maximalen Verschmutzung. Für die LEDs wird der WS2812B LED-Streifen der Firma Adafruit verwendet. Dieser wird über die dazugehörige Python Bibliothek angesteuert. Je nach Verschmutzung setzt sich die Farbe aus grün und rot zusammen. Die hierfür verwendet Schaltung ist in Abbildung \ref{fig-tree_iteration3_wiring} dargestellt. 
       	\begin{figure}[H]
    	\begin{center}
    		\includegraphics[
    		width=0.8\linewidth,
    		]{imgs/tree_wiriring_iteration3.PNG}
    		\caption{Schaltung für den Baum}
    		\label{fig-tree_iteration3_wiring}
    	\end{center}
    \end{figure}
    \noindent
   	Diese enthält zusätzlich einen Kondensator und eine Schnittstelle für eine externe Stromversorgung. Der Kondensator soll Schwankungen der Spannung ausgleichen. Das Netzteil wird verwendet, da der Raspberry Pi nicht genug Strom für die LEDs bereitstellen kann. Mit der vorgestellten Schaltung kann das externe Netzteil zusätzlich den Raspberry Pi über den $5V$-Pin mit Strom versorgen. Somit wird nur ein Netzteil für alle Komponenten  benötigt.
   	
   	\subsubsection*{Fahrzeug}
   	Beim Testen der Visualisierung mit der Fahrzeugschaltung ist ein Problem aufgetreten. Ist das Fahrzeug mit einem USB Kabel an einen Computer angeschlossen, funktioniert die Sensorerkennung. Wird diese nur mit dem Akku betrieben, können keine Sensorwerte erkannt werden. Beim Ausmessen der verfügbaren Spannung zeigt sich, dass im Betrieb mit dem Akku nur $3.3V$ an dem $5V$-Pin verfügbar sind. Wie in Kapitel \ref{sec-ita1-hardware} beschrieben, benötigt der Hall-Sensor mindestens $3.7V$.\\
   	Zum Lösen dieses Problems muss die Spannung angehoben werden. Der erste Lösungs\-ansatz ist ein \emph{Logic-Level-Converter}, welcher zwischen dem Sensor und dem Arduino eingebaut werden kann. Dieser kann Signale in bidirektionaler Richtung zwischen zwei Spannungen, wie zum Beispiel $5V \longleftrightarrow 3.3V$, wandeln. Das Problem hierbei ist, dass an einem Pin des Moduls eine $5V$ Spannung angelegt werden muss, welche nicht verfügbar ist. Der zweite Ansatz ist das Verwenden eines \textit{Step-Up Boost-Converters}, mit welchem das Problem erfolgreich gelöst werden kann.
   	Dieses Modul akzeptiert eine Eingangsspannung zwischen $2-24V$ und hat eine Ausgangsspannung von $5-28V$. Die Ausgangsspannung kann mit einem Potentiometer eingestellt werden. Die Schaltung des Fahrzeugs wird mit diesem Modul abgeändert. Die neue Version ist in Abbildung \ref{fig-hardware-car-iteration3} dargestellt.
   	\begin{figure}[H]
   		\begin{center}
   			\includegraphics[
   			width=0.8\linewidth,
   			]{imgs/car_wiring_iteration3.png}
   			\caption{Schaltung eines Fahrzeugs mit Boost-Converter}
   			\label{fig-hardware-car-iteration3}
   		\end{center}
   	\end{figure}
   \noindent
   	Der $+$- und \textit{GND}-Pin des Sensors werden an den Output des \textit{Step-Up Boost-Converters} angeschlossen, welcher auf $5V$ eingestellt wird. Die benötigte Eingangsspannung für das Modul wird vom $3.3V$-Pin des Arduinos geliefert. Somit funktioniert die Schaltung sowohl im Betrieb mit einem USB-Kabel als auch mit einem Akku. 

\end{document}

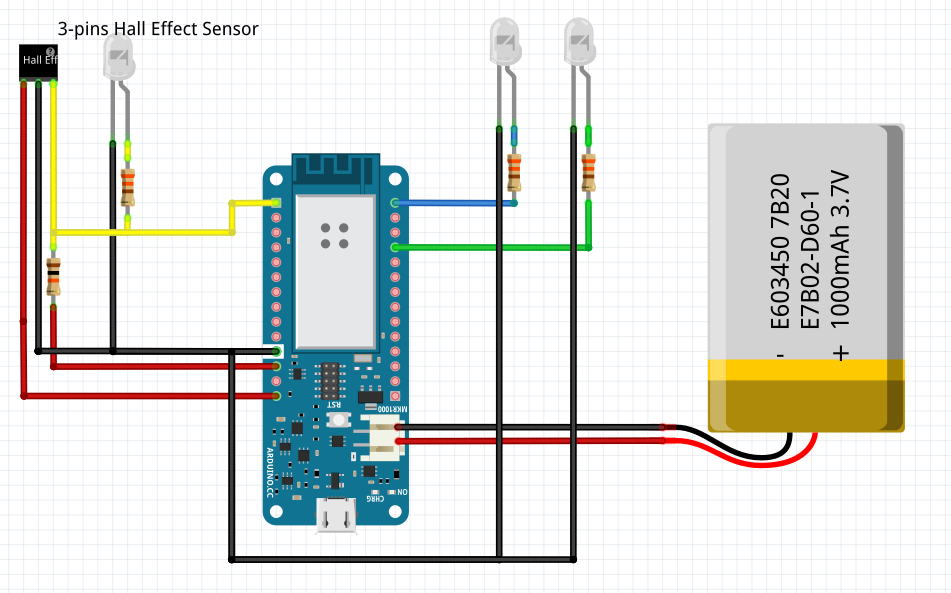
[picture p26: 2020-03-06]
doc/imgs/hardware_car_iteration2.PNG

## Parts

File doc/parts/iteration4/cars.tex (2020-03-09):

\documentclass[.../Dokumentation.tex]{subfiles}
\begin{document}
\subsection{Fahrzeuge}\label{sec-ita4-cars}
Da die vorangegangene Iteration in Kapitel \ref{sec-ita3} gezeigt hat, dass auch ohne 
Stützmaterial kein zufriedenstellendes Ergebnis erzielt werden kann, 
wurde der Versuch unternommen, eine alternative Befestigungslösung zu erarbeiten. 
Die dem Druck mit Stützmaterial zugrunde liegende Problematik äußert sich in 
den horizontal durch das Fahrzeug geführten Hohlräumen für die Bolzen.
Deshalb wurde der Versuch unternommen, diese nun vertikal anzubringen.
Darüber hinaus sollte zusätzliche Stabilität in Längsrichtung gewonnen werden, 
indem eine Vorrichtung zum \grqq Einhängen\grqq{} geschaffen wird. 
Beides ist in den Abbildungen \ref{fig-new-fixture-upper} und 
\ref{fig-new-fixture-lower} zu sehen.
\begin{figure}[H]
\begin{center}
    \includegraphics[
        width=0.4\linewidth,
    ]{imgs/new_fixture_upper.jpg}
    \caption{Neues Befestigungskonzept (obere Hälfte)}
    \label{fig-new-fixture-upper}
\end{center}
\end{figure}
\noindent
\begin{figure}[H]
\begin{center}
    \includegraphics[
        width=0.4\linewidth,
    ]{imgs/new_fixture_lower.jpg}
    \caption{Neues Befestigungskonzept (untere Hälfte)}
    \label{fig-new-fixture-lower}
\end{center}
\end{figure}
\noindent 
Außerdem wurden die Aussparungen für Scheinwerfer und Hall-Sensor erweitert, 
um umständlichen Berechnungen und Probedrucken entgegenzuwirken.
\end{document}

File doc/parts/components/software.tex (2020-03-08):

% !TeX spellcheck = de_DE
\documentclass[.../Dokumentation.tex]{subfiles}
\begin{document}
\subsection{Software}\label{sec-components-software}
Für das Projekt werden zwei verschiedene Programmiersprachen verwendet. 
Die Arduinos verwenden standardmäßig eine C- beziehungsweise C++-ähnliche 
Programmiersprache, für welche die Entwicklungsumgebung 
\textit{Arduino IDE} verwendet wird. 
Für die Visualisierung stehen verschiedene Programmiersprachen zur Auswahl. 
Für dieses Projekt soll Python 3.7 verwendet werden. Mit dieser Sprache wird das einfache Erstellen eines Webservers, welcher zum Empfangen 
der Daten genutzt wird und das Ansteuern der IO-Pins beziehungsweise des 
Displays vom Raspberry Pi ermöglicht.

\subsubsection{Modellierung und Slicing}\label{sec-components-software-model}
Um die Fahrzeuge mit Hilfe von 3D-Druck herstellen zu können, musste eine 
Software gefunden werden mit der die benötigten Modelle erschaffen und angepasst 
werden können. Zweierlei Lösungen wurden hierfür in Betracht gezogen.
Zum einen \textit{Blender}\footnote{https://www.blender.org/},
da das erfoderliche Dateiformat 
\textit{stl} nativ unterstützt wird und derartig weit verbreitete Open 
Source Lösungen oft eine entsprechend große Community vorweisen können.
Zum anderen \textit{SketchUp} \footnote{https://www.sketchup.com/de},
welches zwar nur mit verringertem 
Funktionsumfang frei verfügbar ist, aber besonders durch seine einfache 
Bedienung überzeugt. Die Wahl fiel darauf, zunächst erste Gehversuche mit \textit{Blender} 
zu unternehmen und im Fall größerer Schwierigkeiten in der Bedienung auf 
\textit{SketchUp} zurückzugreifen, da bei dieser Software auf bereits 
vorhandene Erfahrungen zurückgegriffen werden kann. 
Die Unterstützung für das \textit{stl}-Format 
muss in diesem Fall jedoch über Erweiterungen sichergestellt werden. Zur Vorbereitung etwaiger Modelle für den Druck war es weiter nötig, 
eine geeignete Software für den \textit{Slicing}-Vorgang zu finden.
Nach erfolgter Recherche und auf Anraten des \textit{FabLab} der Hochschule 
Flensburg fiel die Wahl auf 
\textit{Cura}\footnote{https://ultimaker.com/de/software/ultimaker-cura}.
Neben einfacher Handhabung überzeugt \textit{Cura} durch die Unterstützung 
der zur Durchführung des Projekts verfügbaren Drucker und dem 
\textit{stl}-Format.
\end{document}

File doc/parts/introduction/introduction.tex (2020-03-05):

% !TeX spellcheck = de_DE
\documentclass[.../Dokumentation.tex]{subfiles}
\begin{document}
\section{Einleitung}\label{sec-intr}
Im Zuge der Veranstaltung \grqq Maker's Lab - Things that Think\grqq{} wird die 
Entwicklung interaktiver Systeme, bestehend aus Hard- sowie Software, 
thematisiert.
Neben dem Fokus auf der Verwendung von Raspberry Pi und Arduino als 
Hardware-Komponenten liegt ein weiterer Schwerpunkt auf der 
Verwendung von Techniken und Praktiken aus den Bereichen \textit{making} und 
\textit{rapid prototyping}.
Unter Berücksichtigung dieser Punkte gilt es, eine \grqq anfassbare\grqq{} Schnittstelle 
zwischen Mensch und Computer zu schaffen, welche gleichzeitig thematisch dem 
Klimapakt Flensburg und seiner Mission entspricht.
Nachfolgend soll einerseits die Motivation und andererseits die daraus 
resultierende Projektidee umschrieben werden.
\end{document}

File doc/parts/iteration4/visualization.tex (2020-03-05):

\documentclass[.../Dokumentation.tex]{subfiles}
\begin{document}
\subsection{Darstellung}\label{sec-ita4-visualization}
Aufbauend auf den in \ref{sec-ita3} gewonnenen Erkenntnissen wurden ein neuer 
Baum und eine neue Box aus 6mm dickem Holz ausgeschnitten. Obgleich auch hier 
wieder einige Blätter verloren gingen, war das Resultat weitaus stabiler und 
wurde für die folgenden Montageschritte als geeignet befunden.\\
Das in \ref{fig-treeNew} gezeigte Konzept sah noch eine Montage der 
Servomotoren hinter dem Baum, am Boden der Kiste vor. 
Um die Bewegung einfacher umsetzen zu können und die Montage des Raspberry 
Pis im Inneren zu erleichtern, wurde aus Holzresten des \textit{FabLab}s eine 
Art Zwischenboden über dem Baum geschaffen. Die Aufhängung der Äste soll 
auf diesem Weg ohne weitere Umwege am Rand der Box realisiert werden können.
\end{document}

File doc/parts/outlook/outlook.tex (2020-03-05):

% !TeX spellcheck = de_DE
\documentclass[.../Dokumentation.tex]{subfile}
\begin{document}
\subsection{Ausblick}\label{sec-outlook}
Da im Rahmen der Veranstaltung auf Grund der begrenzten Zeit und Ressourcen nur die Entwicklung eines einfachen Prototypen möglich ist, werden im Folgenden etwaige Erweiterungen und Optimierungen vorgestellt.
\begin{itemize}
	\item \textbf{Anpassung des SUV-Modells}:\\
	Das erste SUV-Fahrzeugmodell diente nur zum Herstellen der Funktionalität. 
	Deshalb wurde auf eine detailreiche Modellierung verzichtet. 
	Vor einem weiteren Druck des Modells sollte es überarbeitet werden.
	\item \textbf{Weitere Fahrzeugtypen}:\\
	Da die für die Funktion erforderliche Elektronik einen fest definierten 
	Platzbedarf hat, können weitere Fahrzeuge einfach erstellt werden. Hierzu 
	muss lediglich die äußere Form angepasst und auf dem Arduino der 
	Fahrzeugtyp hinterlegt werden. 
	\item \textbf{Baum}:\\
	Für den Baum wurde eine Vorlage aus dem Internet verwendet. Für einen 
	langfristigen Einsatz sollte eine auf den Anwendungskontext zugeschnittene 
	Version erstellt werden.
	\item \textbf{Kiste für den Baum}:\\
	Für eine einfachere Montage und ein stimmigeres Gesamtbild kann die Kiste 
	mit Aussparungen und Einbauhilfen für die Komponenten ausgestattet werden. 
	Somit sind keine manuellen Anpassungen mehr nötig.
	\item \textbf{Display}:\\
	Mit weiteren finanziellen Mitteln kann die Darstellung, entsprechend dem 
	ursprünglichen Konzept, um ein Display erweitert werden.
	\item \textbf{Unterlage}:\\
	Mit dem Hall-Sensor kann die gefahrene Strecke sehr genau ermittelt werden. 
	Stünden eine maßstabsgetreue Karte als Unterlage und das oben genannte 
	Display zur Verfügung, könnten gefahrene Strecken und die Emissionen daraus
	genau berechnet und abgebildet werden.
	\item \textbf{Platine}:\\
	Da die manuelle Fertigung der Platinen sehr aufwändig ist, sollten diese 
	bei größeren Produktionsmengen professionell hergestellt werden.
\end{itemize}
   
\end{document}

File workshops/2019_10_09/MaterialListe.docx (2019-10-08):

Bestell Liste

Name | Anzahl | Preis pro Stück | Link zum Produkt
Arduino MKR Wifi 1010 | 4 | 33,20 € | https://www.exp-tech.de/plattformen/arduino/9177/arduino-mkr-wifi-1010
Akku Pack | 4 | 6,95 | https://www.exp-tech.de/zubehoer/batterien-akkus/lipo-akkus/6329/lipo-akku-2000mah-3.7-v-2-mm-jst
Arduino MKR Prototype Shield (klein) | 5 | 8,21 € | https://www.exp-tech.de/module/prototyping/7825/mkr-proto-shield-fuer-arduino-mkr1000-klein
Slide Switch Steckanschluss | 5 | 1,40 € | https://www.exp-tech.de/zubehoer/tasterschalter/5075/mini-slide-switch-3-pin-spdt-0.3a-3-pack
Slide Switch Lötanschluss | 5 | 0,19 € | https://www.reichelt.de/schiebeschalter-miniatur-loetanschluss-1x-um-t-215-p19975.html?&trstct=pol_3
HallSensor Unipolar | 5 | 1,35 € | https://www.reichelt.de/hallsensor-unipolar-digital-to-92-ss-441-a-p151345.html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
Magnet | 10 | 0,95 € | https://www.reichelt.de/magnet-4mm-staerke-2mm-magnet-4-2-p151644.html?&trstct=pos_0
Led Stripe | 2 | 19,22 € | https://www.exp-tech.de/zubehoer/led-leuchtmittel/8712/adafruit-neopixel-led-side-light-strip-black-60-led
Led Stripe Adapter | 2 | 1,10 € | https://www.reichelt.de/kupplung-aussen-5-5-mm-innen-2-1-mm-delock-65421-p127462.html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
Led Netzteil | 2 | 7,85 € | https://www.exp-tech.de/zubehoer/netzteile/7423/hnp06-050l6-5v-1.5a-steckernetzteil-7.5w
Beschleunigungssensor | 5 | 3,50 € | https://www.reichelt.de/entwicklerboards-beschleunigung-gyroskop-mit-header-mpu-60-debo-sens-3axish-p266105.html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
Kondensator | 3 | 0,23 € | https://www.reichelt.de/elko-1000-f-6-3-v-105-c-rad-lxz-6-3-1k0-p166328.html?r=1
Raspberry Pi | 1 | 36,50 € | https://www.reichelt.de/raspberry-pi-3-b-4x-1-4-ghz-1-gb-ram-wlan-bt-raspberry-pi-3b-p217696.html

Kabel

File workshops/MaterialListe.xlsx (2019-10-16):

Absolutes Minimum 1 Auto
Name | Anzahl | Preis pro Stück | Preis Gesamt | Link zum Produkt
Arduino MKR Wifi 1010 | 1 | 33.20 € | 33.20 € | https://www.exp-tech.de/plattformen/arduino/9177/arduino-mkr-wifi-1010
Akku Pack | 1 | 6.95 € | 6.95 € | https://www.exp-tech.de/zubehoer/batterien-akkus/lipo-akkus/6329/lipo-akku-2000mah-3.7-v-2-mm-jst
Akku Verlängerungskabel | 1 | 2.08 € | 2.08 € | https://www.exp-tech.de/plattformen/adafruit-flora/4945/jst-ph-akku-verlaengerungskabel-500mm
Arduino MKR Prototype Shield (klein) | 2 | 8.21 € | 16.42 € | https://www.exp-tech.de/module/prototyping/7825/mkr-proto-shield-fuer-arduino-mkr1000-klein
Slide Switch Steckanschluss | 2 | 1.40 € | 2.80 € | https://www.exp-tech.de/zubehoer/tasterschalter/5075/mini-slide-switch-3-pin-spdt-0.3a-3-pack
Slide Switch Lötanschluss | 2 | 0.19 € | 0.38 € | https://www.reichelt.de/schiebeschalter-miniatur-loetanschluss-1x-um-t-215-p19975.html?&trstct=pol_3
HallSensor Unipolar | 2 | 1.35 € | 2.70 € | https://www.reichelt.de/hallsensor-unipolar-digital-to-92-ss-441-a-p151345.html?PROVID=2788&r=1
Magnet | 5 | 0.95 € | 4.75 € | https://www.reichelt.de/magnet-4mm-staerke-2mm-magnet-4-2-p151644.html?&trstct=pos_0
Led Stripe | 1 | 19.22 € | 19.22 € | https://www.exp-tech.de/zubehoer/led-leuchtmittel/8712/adafruit-neopixel-led-side-light-strip-black-60-led
Led Stripe Adapter | 1 | 1.10 € | 1.10 € | https://www.reichelt.de/kupplung-aussen-5-5-mm-innen-2-1-mm-delock-65421-p127462.html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
Led Netzteil | 1 | 7.85 € | 7.85 € | https://www.exp-tech.de/zubehoer/netzteile/7423/hnp06-050l6-5v-1.5a-steckernetzteil-7.5w
Kondensator | 3 | 0.23 € | 0.69 € | https://www.reichelt.de/elko-1000-f-6-3-v-105-c-rad-lxz-6-3-1k0-p166328.html?r=1
Raspberry Pi | 1 | 36.50 € | 36.50 € | https://www.reichelt.de/raspberry-pi-3-b-4x-1-4-ghz-1-gb-ram-wlan-bt-raspberry-pi-3b-p217696.html
Servo Motoren | 6 | 4.00 € | 24.00 €
 |  | Gesamt Kosten: | 158.64 €
2 Autos
Name | Anzahl | Preis pro Stück | Preis Gesamt | Link zum Produkt
Arduino MKR Wifi 1010 | 2 | 33.20 € | 66.40 € | https://www.exp-tech.de/plattformen/arduino/9177/arduino-mkr-wifi-1010
Akku Pack | 2 | 5.80 € | 11.60 € | https://www.exp-tech.de/zubehoer/batterien-akkus/lipo-akkus/5801/lipo-akku-1000mah-3.7-v-2-mm-jst
Akku Verlängerungskabel | 2 | 2.08 € | 4.16 € | https://www.exp-tech.de/plattformen/adafruit-flora/4945/jst-ph-akku-verlaengerungskabel-500mm
Arduino MKR Prototype Shield (klein) | 3 | 8.21 € | 24.63 € | https://www.exp-tech.de/module/prototyping/7825/mkr-proto-shield-fuer-arduino-mkr1000-klein
Slide Switch Steckanschluss | 3 | 1.40 € | 4.20 € | https://www.exp-tech.de/zubehoer/tasterschalter/5075/mini-slide-switch-3-pin-spdt-0.3a-3-pack
Slide Switch Lötanschluss | 3 | 0.19 € | 0.57 € | https://www.reichelt.de/schiebeschalter-miniatur-loetanschluss-1x-um-t-215-p19975.html?&trstct=pol_3
HallSensor Unipolar | 3 | 1.35 € | 4.05 € | https://www.reichelt.de/hallsensor-unipolar-digital-to-92-ss-441-a-p151345.html?PROVID=2788&r=1
Magnet | 9 | 0.95 € | 8.55 € | https://www.reichelt.de/magnet-4mm-staerke-2mm-magnet-4-2-p151644.html?&trstct=pos_0
Led Stripe | 1 | 19.22 € | 19.22 € | https://www.exp-tech.de/zubehoer/led-leuchtmittel/8712/adafruit-neopixel-led-side-light-strip-black-60-led
Led Stripe Adapter | 1 | 1.10 € | 1.10 € | https://www.reichelt.de/kupplung-aussen-5-5-mm-innen-2-1-mm-delock-65421-p127462.html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
Led Netzteil | 1 | 7.85 € | 7.85 € | https://www.exp-tech.de/zubehoer/netzteile/7423/hnp06-050l6-5v-1.5a-steckernetzteil-7.5w
Kondensator | 3 | 0.23 € | 0.69 € | https://www.reichelt.de/elko-1000-f-6-3-v-105-c-rad-lxz-6-3-1k0-p166328.html?r=1
Raspberry Pi | 1 | 36.50 € | 36.50 € | https://www.reichelt.de/raspberry-pi-3-b-4x-1-4-ghz-1-gb-ram-wlan-bt-raspberry-pi-3b-p217696.html
Servo Motoren | 6 | 4.00 € | 24.00 €
 |  | Gesamt Kosten: | 213.52 €
3 Autos
Name | Anzahl | Preis pro Stück | Preis Gesamt | Link zum Produkt
Arduino MKR Wifi 1010 | 3 | 33.20 € | 99.60 € | https://www.exp-tech.de/plattformen/arduino/9177/arduino-mkr-wifi-1010
Akku Pack | 3 | 5.80 € | 17.40 € | https://www.exp-tech.de/zubehoer/batterien-akkus/lipo-akkus/5801/lipo-akku-1000mah-3.7-v-2-mm-jst
Akku Verlängerungskabel | 3 | 2.08 € | 6.24 € | https://www.exp-tech.de/plattformen/adafruit-flora/4945/jst-ph-akku-verlaengerungskabel-500mm
Arduino MKR Prototype Shield (klein) | 4 | 8.21 € | 32.84 € | https://www.exp-tech.de/module/prototyping/7825/mkr-proto-shield-fuer-arduino-mkr1000-klein
Slide Switch Steckanschluss | 4 | 1.40 € | 5.60 € | https://www.exp-tech.de/zubehoer/tasterschalter/5075/mini-slide-switch-3-pin-spdt-0.3a-3-pack
Slide Switch Lötanschluss | 4 | 0.19 € | 0.76 € | https://www.reichelt.de/schiebeschalter-miniatur-loetanschluss-1x-um-t-215-p19975.html?&trstct=pol_3
HallSensor Unipolar | 4 | 1.35 € | 5.40 € | https://www.reichelt.de/hallsensor-unipolar-digital-to-92-ss-441-a-p151345.html?PROVID=2788&r=1
Magnet | 14 | 0.95 € | 13.30 € | https://www.reichelt.de/magnet-4mm-staerke-2mm-magnet-4-2-p151644.html?&trstct=pos_0
Led Stripe | 1 | 19.22 € | 19.22 € | https://www.exp-tech.de/zubehoer/led-leuchtmittel/8712/adafruit-neopixel-led-side-light-strip-black-60-led
Led Stripe Adapter | 1 | 1.10 € | 1.10 € | https://www.reichelt.de/kupplung-aussen-5-5-mm-innen-2-1-mm-delock-65421-p127462.html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
Led Netzteil | 1 | 7.85 € | 7.85 € | https://www.exp-tech.de/zubehoer/netzteile/7423/hnp06-050l6-5v-1.5a-steckernetzteil-7.5w
Kondensator | 3 | 0.23 € | 0.69 € | https://www.reichelt.de/elko-1000-f-6-3-v-105-c-rad-lxz-6-3-1k0-p166328.html?r=1
Raspberry Pi | 1 | 36.50 € | 36.50 € | https://www.reichelt.de/raspberry-pi-3-b-4x-1-4-ghz-1-gb-ram-wlan-bt-raspberry-pi-3b-p217696.html
Servo Motoren | 6 | 4.00 € | 24.00 €
 |  | Gesamt Kosten: | 270.50 €

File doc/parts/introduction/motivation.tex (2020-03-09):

\documentclass[.../Dokumentation.tex]{subfiles}
\begin{document}
\subsection{Motivation}\label{sec-intr-motivation}
Mit dem Ziel, die Folgen alltäglichen Handelns des Einzelnen für die Umwelt 
besser veranschaulichen zu können, soll die tägliche 
Verwendung des eigenen PKWs thematisiert werden.
Bei der späteren Interaktion mit dem fertigen Prototypen soll vor 
allem der Fokus darauf liegen, generationsübergreifend eine möglichst intuitive 
und zugängliche Bedienung zu bieten.
Vor diesem Hintergrund sollen bereits bekannte Konzepte und Komponenten 
aufgegriffen werden welche die Möglichkeit bieten, auf spielerische Art und 
Weise zu lernen.
\end{document}

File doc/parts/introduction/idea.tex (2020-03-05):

\documentclass[.../Dokumentation.tex]{subfiles}
\begin{document}
\subsection{Projektidee}\label{sec-intr-idea}
Es soll eine Kombination aus Eingabegerät und Darstellung geschaffen werden, 
die sich grob an der Bewegung von Spielzeug-Autos auf einem 
mit einer abstrakten Stadt und ihrer Verkehrsinfrastruktur bedruckten Teppich 
orientiert. Gleichzeitig soll maßstabsgetreu die Bewegung der Fahrzeuge 
aufgenommen und in ihre entsprechende CO\textsubscript{2}-Emmission übersetzt 
werden. Die so anfallende Belastung für die Umwelt soll auf einem Display 
optisch ansprechend aufbereitet und mit anschaulichen, zusätzlichen 
Informationen zusammengebracht werden. 
Hierdurch sollen die Konsequenzen des eigenen Handelns verdeutlicht 
und so einem Nutzer näher gebracht werden können, als es durch das 
Auflisten von Statistiken oder Ähnlichem möglich wäre. In Abbildung 
\ref{fig-sponge} ist ein erster \textit{Low-Fidelity}-Prototyp der hier 
beschriebenen Idee zu sehen
\begin{figure}[H]
    \begin{center}
    \includegraphics[
        width=0.5\linewidth,
    ]{imgs/sponge_prototype.jpeg}
    \caption{Erster Prototyp}
    \label{fig-sponge}
\end{center}
\end{figure}
\end{document}

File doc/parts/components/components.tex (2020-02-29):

\documentclass[.../Dokumentation.tex]{subfiles}
\begin{document}
\section{Komponenten}\label{sec-components}
\end{document}

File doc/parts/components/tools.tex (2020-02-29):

\documentclass[.../Dokumentation.tex]{subfiles}
\begin{document}
    \subsection{Werkzeuge}\label{sec-components-tools}
\end{document}

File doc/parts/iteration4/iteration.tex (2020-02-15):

\documentclass[.../Dokumentation.tex]{subfiles}
\begin{document}
    \section{4. Design-Iteration}\label{sec-ita4}
\end{document}

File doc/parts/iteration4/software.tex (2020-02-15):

\documentclass[.../Dokumentation.tex]{subfiles}
\begin{document}
    \subsection{Software}\label{sec-ita4-software}
\end{document}

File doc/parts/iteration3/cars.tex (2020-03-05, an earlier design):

\documentclass[.../Dokumentation.tex]{subfiles}
\begin{document}
\subsection{Fahrzeuge}\label{sec-ita3-cars}
Um alle Komponenten so einfach wie möglich montieren zu können, wurden 
weitere Anpassungen am Modell vorgenommen. 
Zunächst wurden im Frontbereich Aussparungen für die LED-\grqq 
Scheinwerfer\grqq{} geschaffen. Hierzu wurde der Durchmesser der LEDs 
aufgenommen und in Form von zwei \grqq Tunneln\grqq{} durch das Modell 
eingearbeitet. Mit dem Ziel einen sichereren Halt zu realisiern, wurde dieser 
Tunnel in etwa hinter der Länge der LEDs verengt. Auf diesem Wege soll eine 
LED an ihrem Platz bleiben können, während die erforderlichen Kabel trotzdem 
weiter in das Innere des Fahrzeugs geführt werden können.
Nach demselben Prinzip wurde darüber hinaus ein Platz zur Montage des 
Hall-Sensors im Radkasten geschaffen. Da keine genauen Maße zur Verfügung 
standen, wurde der Platzbedarf näherungsweise per Hand bestimmt und etwas 
erweitert, um etwaigen Messfehlern vorzubeugen.
Da sich das Problem um die übereifrige Platzierung von Stützmaterial durch 
\textit{Cura} in den vorherigen Iterationen nicht umgehen ließ, sollte 
dieser Stand des Modells nun zu Evaluationszwecken gänzlich ohne Stützmaterial 
gedruckt werden.
\end{document}

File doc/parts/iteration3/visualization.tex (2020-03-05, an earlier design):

\documentclass[.../Dokumentation.tex]{subfiles}
\begin{document}
\subsection{Darstellung}\label{sec-ita3-visualization}
Da wegen der Dimensionen der Servomotoren keine zufriedenstellende Lösung 
mit in den Ästen integrierten Motoren gefunden werden konnte, wurde ein neues 
Konzept erarbeitet.
Während an der Idee, den Baum in einer mit LEDs umrandeten Kiste zu montieren, 
festgehalten wurde, sah der neue Ansatz vor, die Äste des Baums über Schnüre 
oder Ähnliches zu bewegen.
Diese sollen idealerweise von oberhalb des Baums, bewegt durch die Servomotoren, 
eine marionettenartige Funktionalität herstellen.
Der schematische Aufbau dieser Lösung ist in Abbildung \ref{fig-treeNew} 
dargestellt.
\begin{figure}[H]
\begin{center}
    \includegraphics[
        width=0.5\linewidth,
    ]{imgs/treeNew.jpg}
    \caption{Überarbeitetes Darstellungskonzept}
    \label{fig-treeNew}
\end{center}
\end{figure}
\noindent
Aufgrund der Tatsache, dass sich keine geeignete Umsetzung des Baums  
mittels 3D-Druck erzielen ließ, wurde ein Bild einer Baumsilhouette gesucht.
Mit diesem war es unter der Vorraussetzung eines geeigneten Formats möglich, 
einen qualitativ 
hochwertigen Baum mit Hilfe des Lasercutters des \textit{FabLab}s herzustellen.
Auf dem gleichen Weg war es weiter ein Leichtes, die benötigte Kiste zu 
realisieren \footnote{https://de.makercase.com/\#/basicbox}.
In Abbildung \ref{fig-tree-in-box} ist ein erster Eindruck hiervon zu sehen.
\begin{figure}[H]
\begin{center}
    \includegraphics[
        width=0.5\linewidth,
    ]{imgs/tree_in_box.jpeg}
    \caption{Ausgeschnittener Baum in Kiste}
    \label{fig-tree-in-box}
\end{center}
\end{figure}
\end{document}

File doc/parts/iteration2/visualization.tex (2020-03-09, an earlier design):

\documentclass[.../Dokumentation.tex]{subfiles}
\begin{document}
\subsection{Darstellung}\label{sec-ita2-visualization}
Die im Zuge der vorangegangenen Iteration erdachte Umsetzung einer abstrakteren 
Darstellungsweise wurde in diesem Arbeitsschritt vorangetrieben. 
Anhand eines ersten Papierprototypen, zu sehen in Abbildung 
\ref{fig-tree-paper}, wurde begonnen, das bereits bei der Herstellung der 
Fahrzeugprototypen gewonnene Wissen auf die Schaffung eines druckfähigen 
Baummodels anzuwenden.
\begin{figure}[H]
\begin{center}
    \includegraphics[
        width=0.35\linewidth,
    ]{imgs/tree_paper.jpg}
    \caption{Papierprototyp des Baums}
    \label{fig-tree-paper}
\end{center}
\end{figure}
\noindent
Mit den Maßen der Servomotoren als Referenz wurde mit den Modellierungsarbeiten 
begonnen. Ebendiese Maße bedingten jedoch verhältnismäßig dicke Äste in der 
geplanten Umsetzung des Baums. 
Die daraus resultierenden Dimensionen, insbesondere in die Tiefe, zeigt 
Abbildung \ref{fig-tree-side}.
\begin{figure}[H]
\begin{center}
    \includegraphics[
        width=0.5\linewidth,
    ]{imgs/tree_side.jpg}
    \caption{Dimensionen des Baummodels}
    \label{fig-tree-side}
\end{center}
\end{figure}
\end{document}

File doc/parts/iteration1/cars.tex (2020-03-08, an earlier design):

\documentclass[.../Dokumentation.tex]{subfiles}
\begin{document}
\subsection{Fahrzeuge}\label{sec-ita1-cars}
Vor Beginn erster Modellierungsarbeiten wurden zunächst bemaßte Skizzen, 
zu sehen in Abbildung \ref{fig-car-sketch}, angefertigt. 
Hierdurch war es möglich, den ermittelten Platzbedarf der Hardware-Komponenten abzuschätzen und einen ersten Eindruck der Dimensionen der 
Fahrzeuge zu erhalten.\\
\begin{figure}[H]
    \begin{center}
    \includegraphics[
        width=0.5\linewidth,
    ]{imgs/car_sketch.jpeg}
    \caption{Erste Skizze eines Fahrzeugs}
    \label{fig-car-sketch}
\end{center}
\end{figure}
\noindent
Bei der eigentlichen Modellierung wurde versucht, zunächst mit so wenig 
Details wie möglich, die grobe Form eines PKWs nachzubilden. Hierzu wurde mit 
\textit{Blender} zunächst ein Quader geschaffen, der in seinen Dimensionen 
der Skizze entspricht.\\
Allerdings zeigte sich, dass das Tempo der Modellierung mit \textit{Blender} 
auf Grund mangelnder Erfahrung in der Bedienung unverhältnismäßig langsam und 
somit als nicht zufriedenstellend zu bewerten ist.
Aus diesem Grund wurde die in 
\ref{sec-components-software-model} zur Sprache gekommene Ausweichlösung in 
Form von \textit{SketchUp} für den Rest der Arbeiten verwendet.\\
Der auf diesem Wege, nun in \textit{SketchUp}, geschaffene Quader wurde in 
seiner Form dahingehend manipuliert, dass er äußerlich eher als PKW zu erkennen 
ist. Neben einer angedeuteten Frontsektion mit Motorhaube und abgeschrägter 
Scheibe wurden bereits in diesem Schritt Radkästen und Aussparungen für die 
später benötigten Achsen geschaffen. 
Bei der Dimensionierung der Räder und infolgedessen auch der Radkästen galt 
es zu beachten, dass die verwendeten Magneten ausreichend Platz finden, 
ohne später die strukturelle Integrität des Drucks zu gefährden oder sich so 
nah bei einander befinden, dass vom Hall-Sensor keine einzelnen Magneten 
mehr erkannt werden können.\\
Um den Raum für die elektronischen Komponenten zu schaffen, wurde das Fahrzeug 
horizontal in etwa in der Mitte seiner Höhe in zwei Teilmodelle aufgebrochen.
In beide Hälften wurde nun eine rechteckige 
Aussparung eingearbeitet, die der Skizze aus Abbildung \ref{fig-car-sketch} 
entsprechend, ausreichend Platz bietet.
Hierbei galt es zu beachten, Änderungen an den Dimensionen der einen 
Hälfte präzise auf die andere anzuwenden. Die hier beschriebenen Arbeitsschritte sind in den Abbildungen 
\ref{fig-car-side} und \ref{fig-car-slot} zu sehen.
\begin{figure}[H]
\begin{center}
    \includegraphics[
        width=0.5\linewidth,
    ]{imgs/car_side.jpg}
    \caption{Seitenansicht des ersten Modells}
    \label{fig-car-side}
\end{center}
\end{figure}
\begin{figure}[H]
\begin{center}
    \includegraphics[
        width=0.5\linewidth,
    ]{imgs/car_hardware_slot.jpg}
    \caption{Aussparung im ersten Modell}
    \label{fig-car-slot}
\end{center}
\end{figure}
\noindent
Abbildung \ref{fig-car-side} zeigt weiter einen ersten Ansatz, um beide 
Fahrzeughälften miteinander verbinden und so fixieren zu können. 
In der unteren Hälfte werden Aussparungen vorgesehen, in die entsprechende 
Elemente der oberen eingelassen werden können. Diese zeichnen sich durch eine 
ösenartige Form aus. Somit ist es möglich, entsprechend bemessene Bolzen 
gleichzeitig durch beide Hälften zu führen, um diese zu fixieren. Um zu gewährleisten, dass die aus der Skizze übernommenen Maße 
passend sind, wurde an dieser Stelle mit einem ersten Druck begonnen.
Die in \textit{Cura} verwendeten Einstellungen wurden unter Anleitung 
des \textit{FabLab}-Personals an den jeweiligen Drucker angepasst. 
Abbildung \ref{fig-car-firstPrint} zeigt das Ergebnis dieses Drucks.
\begin{figure}[H]
    \begin{center}
        \includegraphics[
            width=0.5\linewidth,
        ]{imgs/car_firstPrint.jpg}
        \caption{Druck des ersten Modells}
        \label{fig-car-firstPrint}
    \end{center}
    \end{figure}
\end{document}

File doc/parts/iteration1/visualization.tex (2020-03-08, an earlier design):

\documentclass[.../Dokumentation.tex]{subfiles}
\begin{document}
\subsection{Darstellung}\label{sec-ita1-visualization}
Da bereits vor der ersten Materialbestellung deutlich wurde, 
dass geeignete Displays den finanziellen Rahmen des Projekts sprengen 
würden, wurden Konzepte für alternative Formen der Visualisierung erarbeitet.
Obwohl die Machbarkeit zu diesem frühen Zeitpunkt der Durchführung nicht 
abschließend geklärt werden konnte, fiel die Wahl auf eine abstraktere Art 
der Darstellung in Form eines Baums mit beweglichen Ästen.
Bei zunehmenden Emissionen sollen diese Äste mit Hilfe von 
Servomotoren abgesenkt und gleichermaßen nach einer bestimmten Zeit wieder 
angehoben werden können. Um das so entstehende Bild weiter ausprägen zu können, 
soll der gesamte Baum in einer Kiste montiert werden, welche in ihrem inneren 
mit LEDs umrandet ist. Diese sollen, abhängig von der Position der Äste, 
ihre Farbe von grün zu rot wechseln.
Abbildung \ref{fig-tree-sketch} zeigt eine frühe Konzeptskizze der Umsetzung 
dieses Baums.
\begin{figure}[H]
    \begin{center}
    \includegraphics[
        width=0.5\linewidth,
    ]{imgs/tree_sketch.jpg}
    \caption{Erste Skizze des neuen Visualisierungskonzepts}
    \label{fig-tree-sketch}
    \end{center}
\end{figure}
\end{document}

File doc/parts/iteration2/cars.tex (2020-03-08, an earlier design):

\documentclass[.../Dokumentation.tex]{subfiles}
\begin{document}
\subsection{Fahrzeuge}\label{sec-ita2-cars}
Um die in \ref{sec-ita1-result} identifizierten Probleme hinsichtlich des 
Platzbedarfs zu lösen, wurden die Maße des Fahrzeugs angepasst.
Da der erste Eindruck der Beschaffenheit des in Abbildung 
\ref{fig-car-firstPrint} gezeigten Drucks hinsichtlich seiner Stabilität 
die anfänglichen Erwartungen übertroffen hat, wurden zunächst die zu den Seiten 
des Fahrzeugs gelegenen Außenwände der Aussparung in ihrer Stärke halbiert.
Weiter wurde das gesamte Modell in der Länge erweitert und der Hohlraum im 
Fahrzeug so weit wie möglich in diese Richtung vergrößert. Hierdurch soll 
zukünftigen Platz-Engpässen vorgebeugt werden. An dieser Stelle wurde ein weiterer Druck durchgeführt, um das 
Zusammenspiel mit Rädern und Befestigung zu prüfen. Hierbei wurden alle 
Einzelteile für den Druck in einem einzigen Drucker arrangiert.
\begin{figure}[H]
\begin{center}
    \includegraphics[
        width=0.5\linewidth,
    ]{imgs/car_2ndPrint.jpeg}
    \caption{Alle Komponenten eines Fahrzeugs aus einem Druck}
    \label{fig-car-2ndPrint}
\end{center}
\end{figure}
\begin{figure}[H]
\begin{center}
    \includegraphics[
        width=0.5\linewidth,
        angle=90,
        origin=c,
    ]{imgs/car_2ndPrint_assembled.jpeg}
    \vspace*{-2.75cm}
    \caption{Fahrzeughälften mit montierten Rädern}
    \label{fig-car-2ndPrint-assembled}
\end{center}
\end{figure}
\noindent
Während Abbildung \ref{fig-car-2ndPrint} das Ergebnis dieses Drucks zeigt, 
vermittelt Abbildung \ref{fig-car-2ndPrint-assembled} einen Eindruck 
von Form und Dimensionen des fertigen Produkts.
\end{document}

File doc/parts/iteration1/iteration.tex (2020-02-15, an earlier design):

\documentclass[.../Dokumentation.tex]{subfiles}
\begin{document}
    \section{1. Design-Iteration}\label{sec-ita1}
\end{document}

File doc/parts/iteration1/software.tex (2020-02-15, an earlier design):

\documentclass[.../Dokumentation.tex]{subfiles}
\begin{document}
    \subsection{Software}\label{sec-ita1-software}
\end{document}

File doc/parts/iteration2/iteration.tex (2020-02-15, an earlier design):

\documentclass[.../Dokumentation.tex]{subfiles}
\begin{document}
    \section{2. Design-Iteration}\label{sec-ita2}
\end{document}

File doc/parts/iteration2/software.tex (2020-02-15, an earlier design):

\documentclass[.../Dokumentation.tex]{subfiles}
\begin{document}
    \subsection{Software}\label{sec-ita2-software}
\end{document}

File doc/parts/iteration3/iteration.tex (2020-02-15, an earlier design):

\documentclass[.../Dokumentation.tex]{subfiles}
\begin{document}
    \section{3. Design-Iteration}\label{sec-ita3}
\end{document}

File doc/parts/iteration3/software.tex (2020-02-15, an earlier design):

\documentclass[.../Dokumentation.tex]{subfiles}
\begin{document}
    \subsection{Software}\label{sec-ita3-software}
\end{document}

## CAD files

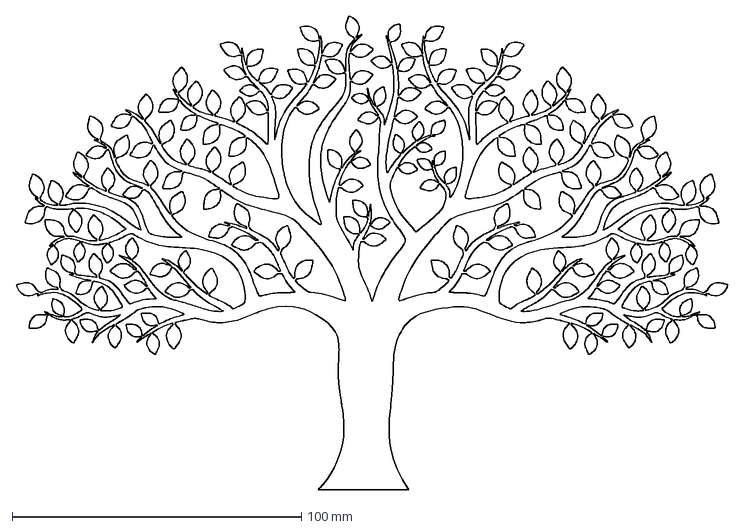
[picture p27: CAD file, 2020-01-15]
src/2d/tree.dxf
245.9 x 163.8 mm

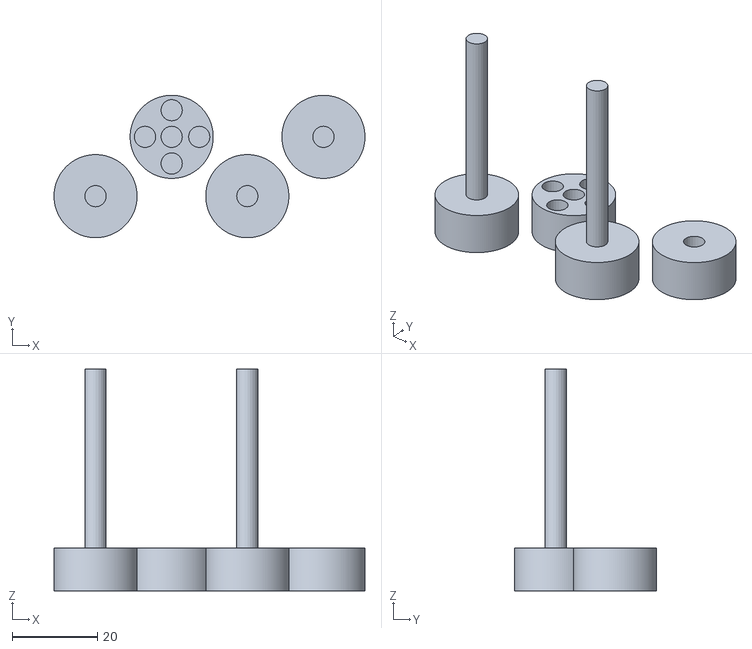
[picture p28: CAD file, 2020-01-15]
src/3d/raw/stl/wheels.stl
73.0 x 33.4 x 52.0

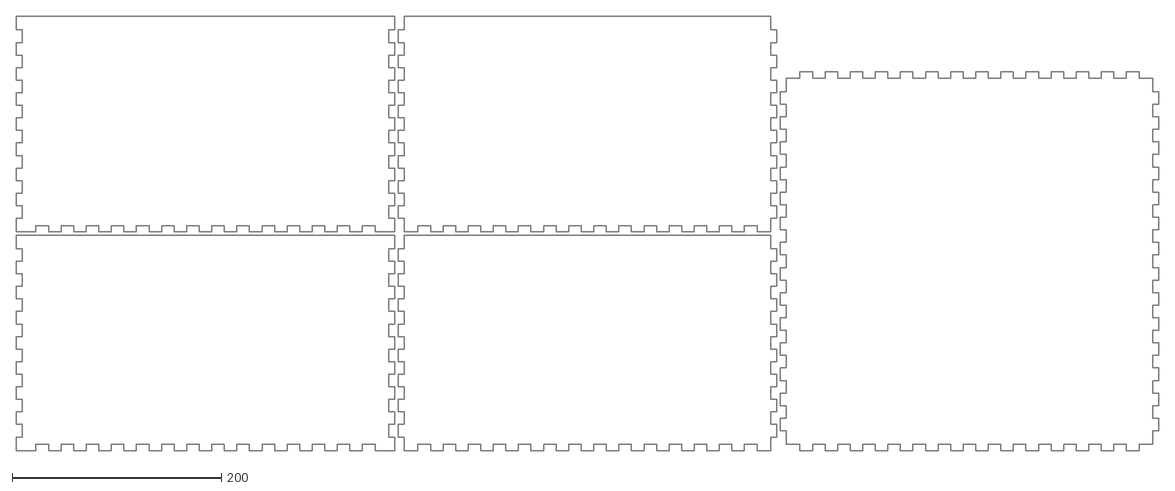
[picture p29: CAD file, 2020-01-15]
src/2d/box.dxf
1092.0 x 415.0

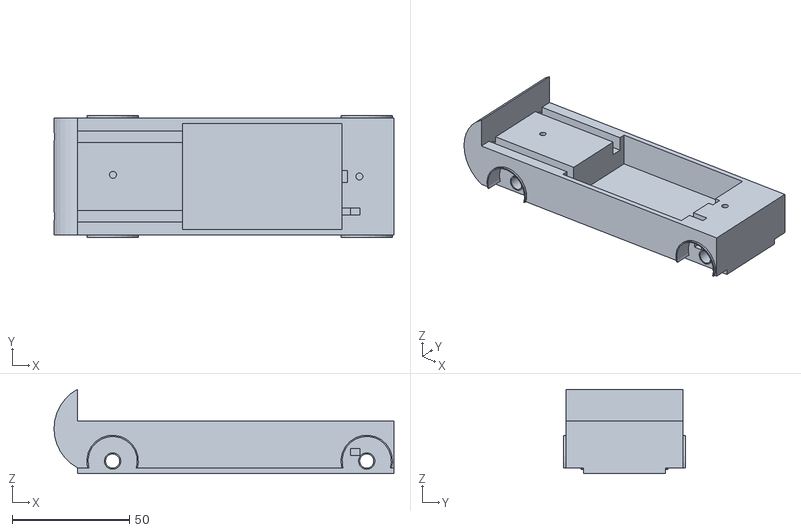
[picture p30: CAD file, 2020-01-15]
src/3d/raw/stl/lower_alt.stl
145.0 x 52.0 x 36.0

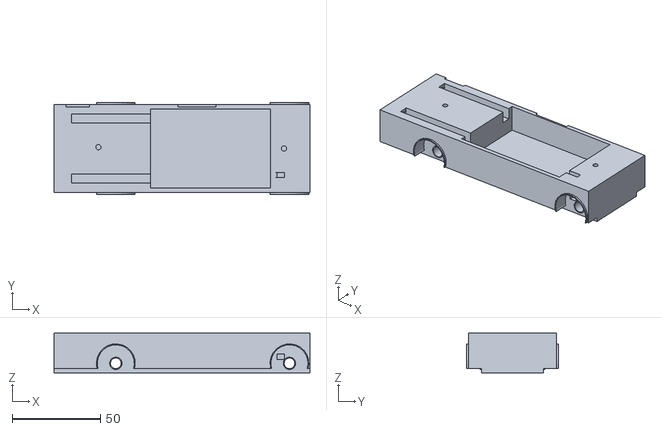
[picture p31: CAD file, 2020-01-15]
src/3d/raw/stl/bus_lower.stl
145.0 x 52.0 x 22.5

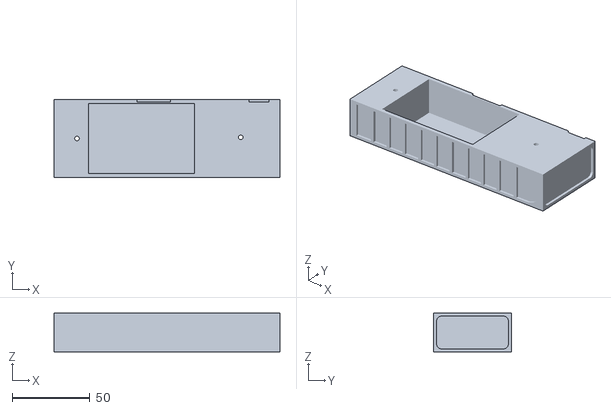
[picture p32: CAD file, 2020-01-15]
src/3d/raw/stl/bus_upper.stl
145.0 x 50.0 x 25.0

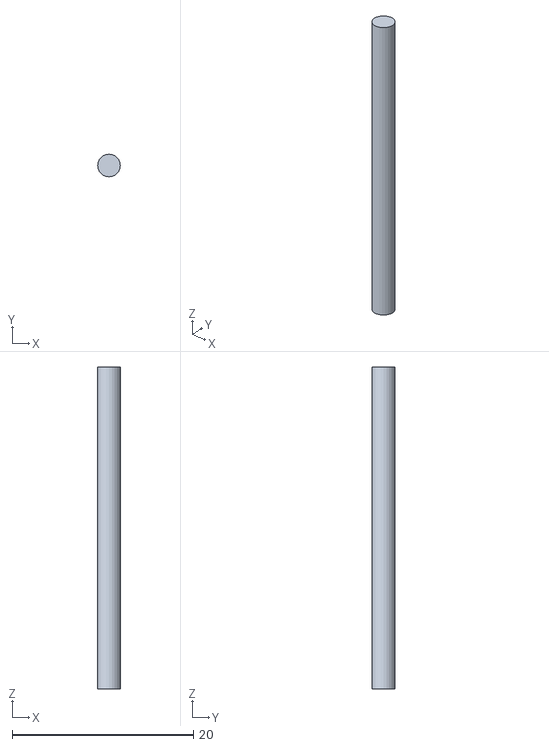
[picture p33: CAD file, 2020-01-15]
src/3d/raw/stl/fastening_vertical_long.stl
2.50 x 2.50 x 35.5

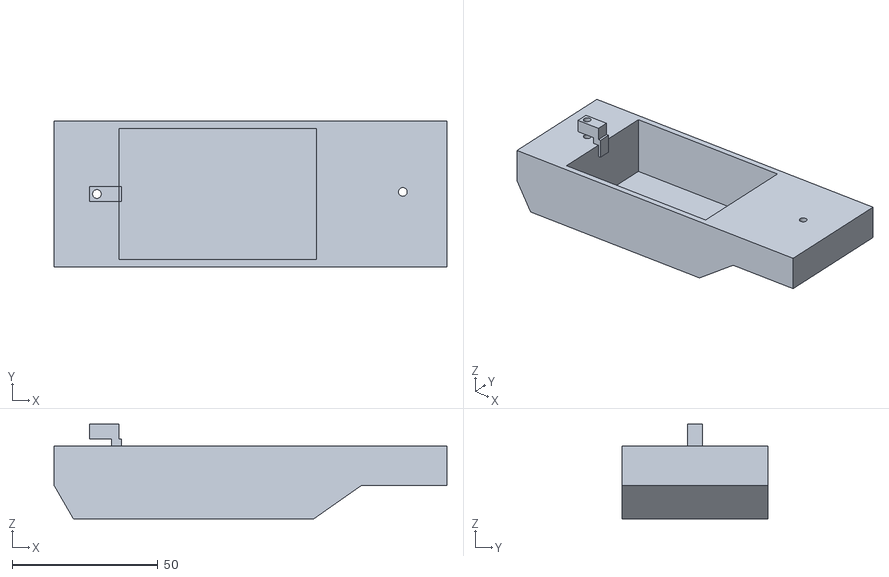
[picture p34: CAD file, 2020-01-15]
src/3d/raw/stl/upper_alt.stl
135.0 x 50.0 x 32.5

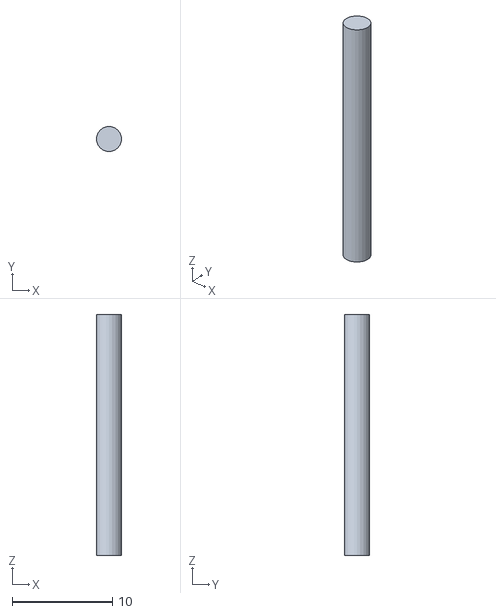
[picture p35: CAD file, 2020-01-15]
src/3d/raw/stl/fastening_vertical_short.stl
2.50 x 2.50 x 24.0

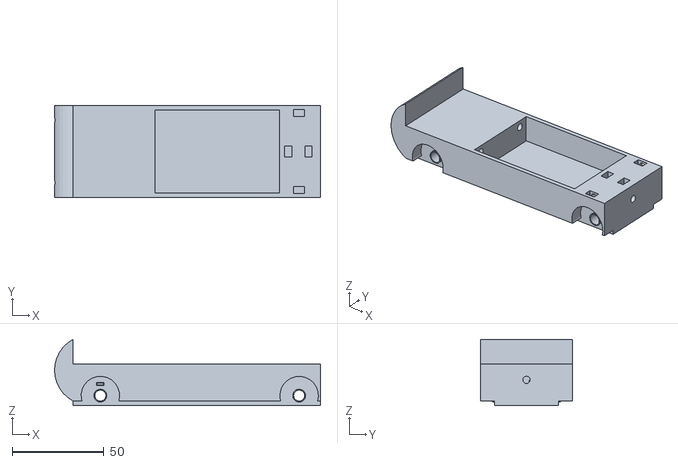
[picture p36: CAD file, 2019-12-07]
src/3d/raw/stl/lower.stl
145.0 x 50.0 x 36.0

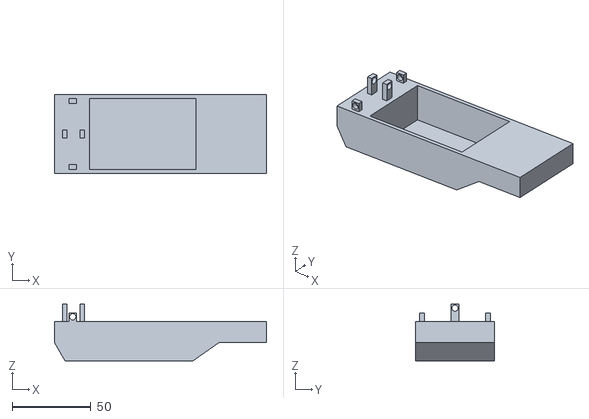
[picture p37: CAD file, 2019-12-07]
src/3d/raw/stl/upper.stl
135.0 x 50.0 x 36.0

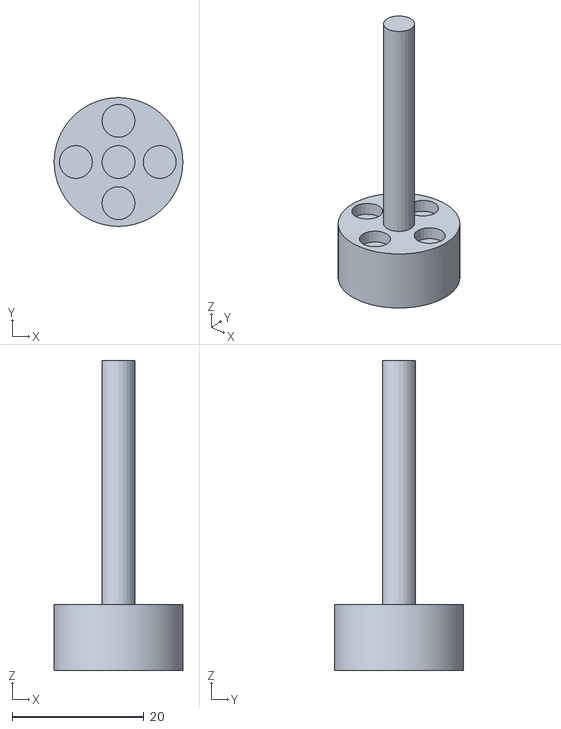
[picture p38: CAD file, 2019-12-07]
src/3d/raw/stl/wheel_axis.stl
19.5 x 19.5 x 47.0

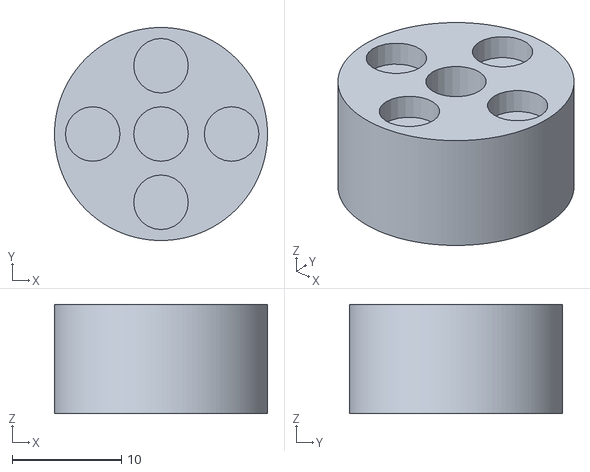
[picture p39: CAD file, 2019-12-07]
src/3d/raw/stl/wheel.stl
19.5 x 19.5 x 10.0

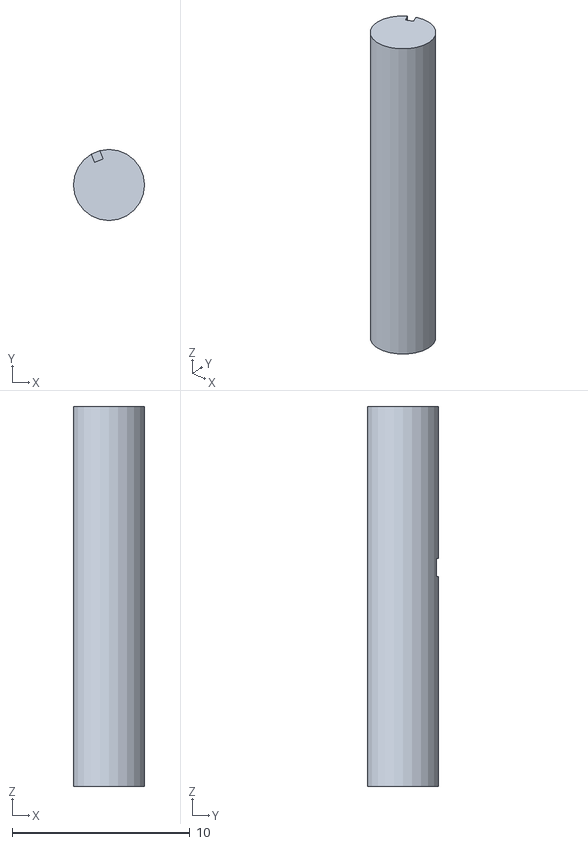
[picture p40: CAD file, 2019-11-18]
src/3d/raw/stl/fastening_back_back2front.stl
4.00 x 4.00 x 21.4

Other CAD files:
src/3d/raw/stl/fastening_back_left2right.stl
src/3d/raw/draft.skp
src/3d/raw/tree.skp

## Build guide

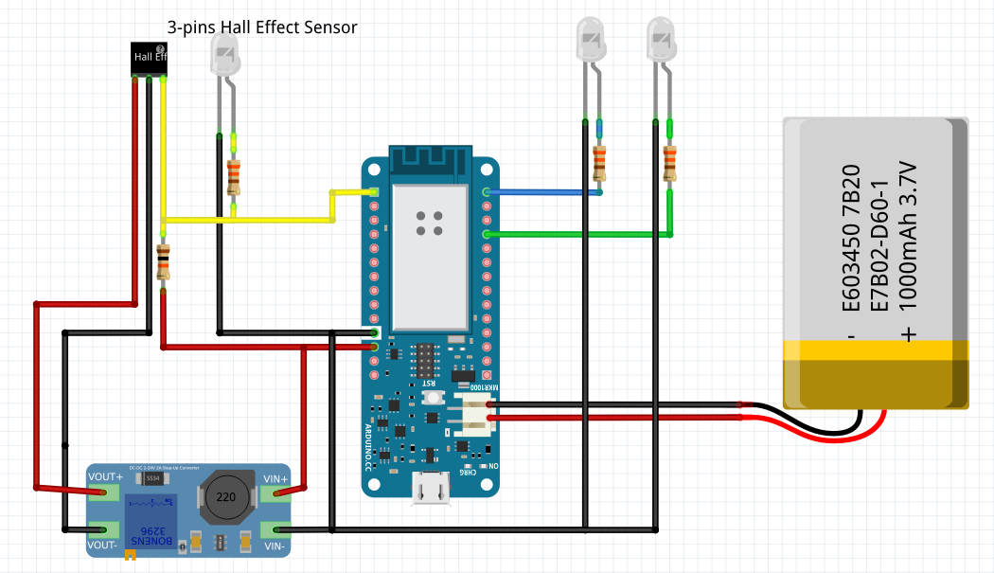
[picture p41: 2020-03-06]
doc/imgs/car_wiring_iteration3.png

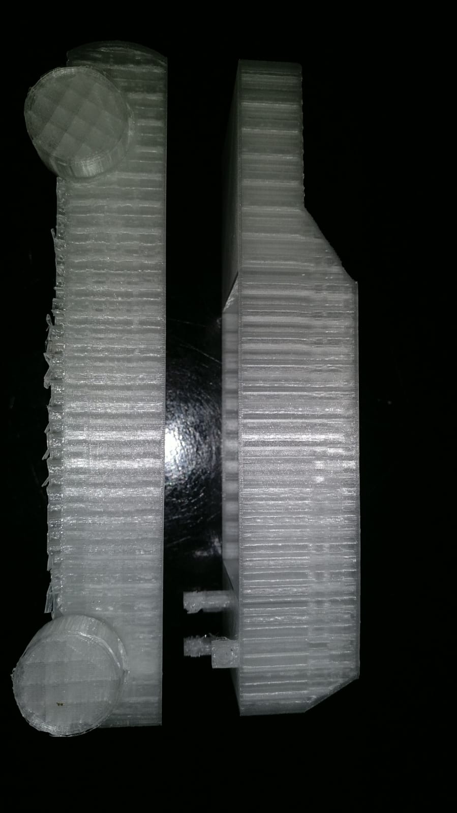
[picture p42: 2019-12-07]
doc/imgs/car_2ndPrint_assembled.jpeg

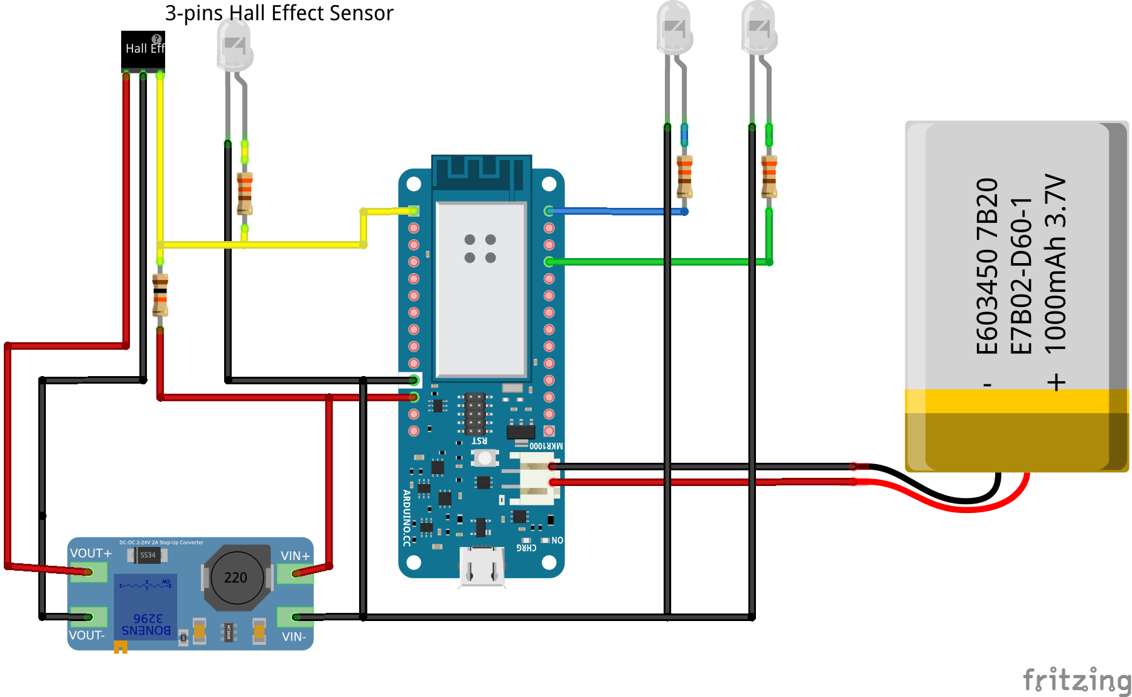
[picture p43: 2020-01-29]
src/arduino/WireDiagram/CarWiring_final.png

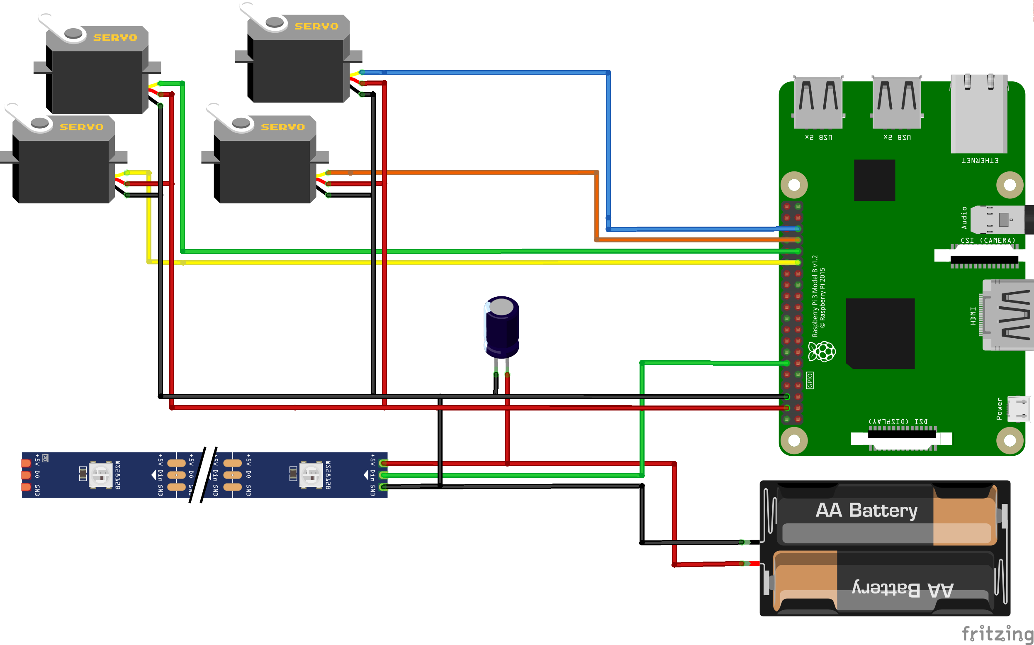
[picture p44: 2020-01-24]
src/pi/WireDiagram/BackendWiring_final.png

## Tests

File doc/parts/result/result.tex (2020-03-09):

% !TeX spellcheck = de_DE
\documentclass[.../Dokumentation.tex]{subfile}
\begin{document}
\section{Fazit}\label{sec-result}
\begin{figure}[H]
\begin{center}
    \includegraphics[
        width=0.55\linewidth,
    ]{imgs/final_image.jpeg}
    \caption{Fertiger Prototyp}
    \label{fig-final-prototype}
\end{center}
\end{figure}
\noindent 
Der im Zuge der vier genannten Iterationen entwickelte und geschaffene Prototyp, 
zu sehen in Abbildung \ref{fig-final-prototype},  
wird nachfolgend mit Bezug auf die Projektidee bewertet. Mit den beiden 
Fahrzeugen ist eine anfassbare Schnittstelle zum System realisiert worden. Die 
Fahrzeuge sind mittels 3D-Druck hergestellt und mit je einem Arduino 
ausgestattet. Hierdurch ist die drahtlose Kommunikation mit dem 
dahinterstehenden System möglich. Die Kombination aus der verwendeten Hardware 
und dem Herstellungsprozess der Fahrzeuge ermöglicht es, den gewünschten 
Formfaktor zu erreichen. Trotz der verbauten Hardware sind die Fahrzeuge leicht 
und können auch von Kindern in eine Hand genommen und bedient werden. 
Zur Inbetriebnahme muss lediglich die Stromversorgung der Fahrzeuge mittels 
eines Schalters hergestellt werden. Die Arduinos sind so programmiert und 
konfiguriert, dass sie automatisch die Kommunikation mit dem dahinterliegenden 
System aufnehmen. \\
Dieses System übernimmt Empfang und Verarbeitung der übermittelten Daten sowie 
die Koordination der Darstellung. 
Obwohl die ursprüngliche Idee der Verwendung 
eines Displays verworfen werden musste, wird eine gleichwertige Darstellung auf 
Basis eines beweglichen Baums erzielt. Auch wenn es so nicht mehr möglich ist, 
genaue Messwerte anzuzeigen, wird der Umwelteinfluss verschiedener 
Fahrzeugtypen deutlich. Dieser Eindruck wurde durch den Kontakt mit 
projektfremden Personen, unter anderem im \emph{FabLab}, bestätigt. Wie zuvor 
bei den Fahrzeugen auch muss für den Betrieb lediglich der Raspberry Pi mit 
Strom versorgt werden.\\
Abschließend lässt sich festhalten, dass die zu Beginn formulierte Idee trotz 
angefallener Änderungen erfolgreich umgesetzt werden konnte. Die Komponenten 
des Gesamtsystems interagieren reibungslos miteinander und können den 
gewünschten Lerneffekt bieten, beziehungsweise damit zu einer 
Verhaltensänderung anregen.
\end{document}

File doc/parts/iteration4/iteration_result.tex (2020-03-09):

% !TeX spellcheck = de_DE
\documentclass[.../Dokumentation.tex]{subfiles}
\begin{document}
\subsection{Ergebnis}\label{sec-ita4-result}
Mit den in \ref{sec-ita4-cars} vorgenommenen Änderungen am Modell konnte 
zwar genügend Platz für die Montage der kleineren Komponenten geschaffen 
werden, jedoch war der Einsatz einer Heißklebepistole erforderlich, um einen 
sicheren Halt der Bauteile zu gewährleisten.\\
Auch wenn die vertikale Anordnung der Befestigung die Problematik um das 
Stützmateri\-al löste, so konnte die in Abbildung 
\ref{fig-new-fixture-upper} gezeigte Vorrichtung die Montage nicht 
überdauern.
Da eine Erhöhung der Fülldichte bei den ohnehin schon größeren 
Fahrzeughälften die Druckzeit unverhältnismäßig verlängert hätte und die 
vorgesehenen Schächte für die Bolzen einwandfrei waren, wurde eine 
konventionellere Form der Befestigung gewählt. In den Räumen der 
Analog-Werkstatt des \textit{FabLab} fanden sich geeignete Werkzeuge. 
Nach kurzer Recherche nach den 
genauen Maßen wurden die bereits vorhandenen Löcher in der unteren Hälfte und 
die eigentlich für Bolzen vorgesehenen Schächte mittels eines Bohrers erweitert. 
In die untere Hälfte wurden nun für M3 Schrauben passende Muttern eingearbeitet. 
Unter Zuhilfenahme eines Hammers und der 
Heißklebepistole konnten diese fest mit dem Druck vereint werden. Mit 
den Maßen des Fahrzeugs wurden entsprechend gekürzte Schrauben hergestellt mit welchen es möglich ist, 
die Hälften sicher zu vereinigen. Abbildung \ref{fig-final-fixture} zeigt das Ergebnis der hier beschriebenen 
Arbeitsschritte. Auch die transparenten Plastik-Muttern sind hier zu erkennen.
\begin{figure}[H]
\begin{center}
    \includegraphics[
        width=0.5\linewidth,
    ]{imgs/final_fixture.jpg}
    \caption{Befestigung mit konventionellen Mitteln}
    \label{fig-final-fixture}
\end{center}
\end{figure}
\noindent 
Da das erste Fahrzeug die gestellten Anforderungen erfüllt, wurde ein weiteres 
in Form eines Busses hergestellt. Hierzu war es ausreichend, die äußere Form 
des Modells zu bearbeiten und einige Details hinzuzufügen, die den 
Wiedererkennungswert steigern. Hinsichtlich der Befestigung wurde jedoch 
gleich auf die oben ausgeführte Methode mit Schrauben und Muttern gesetzt.\\
Auch die stabileren Ausführungen von Baum und Box konnten nun montiert werden. Zunächst wurden die Äste des Baums an ihren jeweils dicksten Stellen mit einer 
feinen Holzsäge getrennt. An beiden so entstandenen Verbindungsstellen wurden 
mit einem Bohrer Löcher geschaffen, die in ihrem Durchmesser leicht über die 
Maße einer M3-Schraube hinaus gehen. Solche Schrauben wurden nun durch die 
Löcher geführt und die Äste mit Muttern in Position gebracht. 
Auf diese Weise konnten die Äste beweglich gemacht werden. 
Der Baum selbst wurde mit Hilfe eines einfachen Winkels an seiner endgültigen 
Position fixiert.
Auf die gleiche Weise wurde der in \ref{sec-ita4-visualization} erdachte 
Zwischenboden montiert. Im Anschluss konnten die Servomotoren hierauf angebracht 
werden. Um diese etwas kostspieligeren Komponenten wiederverwendbar zu halten, 
kam erneut die Klebepistole zum Einsatz.\\
Die Verbindung zwischen den Servomotoren und den Ästen, die sie bewegen sollen, 
übernahm konventioneller Faden, auch wenn die Befestigung über Knoten 
unerwartet zeitintensiv war. Der Grund hierfür war, dass es sich schwierig 
gestaltete, ein Gleichgewicht zwischen erforderlichem Halt und  
optisch ansprechender Anfangs- sowie Endposition zu finden.\\
Weiter fand die Steuerung der Visualisierung ihren Platz auf Abstandhaltern auf 
dem Zwischenboden, welche ebenfalls mit Schmelzkleber fixiert wurden.
In die Außenwand der Kiste wurde auf dieser Höhe ein Loch gebohrt, um die 
Stromversorgung ins Innere führen zu können. 
Abschließend wurde der LED-Streifen um den Baum herum montiert, wobei statt der 
oberen Hülle der Box nun die Unterseite des Zwischenbodens gewählt wurde. 
Auch hier konnte sicher gestellt werden, dass das Bauteil erneut verwendbar 
ist, indem die Befestigung mit doppelseitigem Klebeband realisiert wurde. Um den Fokus des Betrachters nicht vom Baum abzulenken, wurde weiter eine 
Blende installiert, welche die Vorgänge auf dem Zwischenboden verbirgt.\\
Die Konfiguration der Fahrzeuge und des Baums wurden zu diesem Zeitpunkt lediglich optimiert. Zusätzlich wurden für alle Komponenten Prototyp-Platinen gefertigt, welche die Montage erleichtern und eine bessere Übersichtlichkeit gewährleisten. 
\end{document}

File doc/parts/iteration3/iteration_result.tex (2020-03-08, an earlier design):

% !TeX spellcheck = de_DE
\documentclass[.../Dokumentation.tex]{subfiles}
\begin{document}
\subsection{Ergebnis}\label{sec-ita3-result}
Obgleich die gewünschten Freiräume im Fahrzeuginneren erhalten werden konnten, 
indem ohne Stützmaterial gedruckt wurde, ergaben sich hierdurch neue Probleme.
Da nun gar keine Stützen mehr gesetzt wurden, konnten einige Außenflächen wie 
beispielsweise an der Motorhaube nicht zufriedenstellend gedruckt werden.
Auch die Unterseite des Fahrzeugs ist betroffen, wenn auch weniger stark.
Beide Stellen sind in Abbildung \ref{fig-hood-no-support} zu sehen.
Des Weiteren wurde deutlich, dass sich durch Zusammenspiel aus modellierten 
Maßen und den vom Drucker erreichbaren Präzisionsintervallen Aussparungen 
ergaben, die kleiner als geplant produziert wurden.
Hiervon betroffen waren die Scheinwerfer und der Hall-Sensor.
\begin{figure}[H]
\begin{center}
    \includegraphics[
        width=0.5\linewidth,
    ]{imgs/hood_without_support.jpg}
    \caption{Probleme beim Druck ohne Stützmaterial}
    \label{fig-hood-no-support}
\end{center}
\end{figure}
\noindent
Während der neue Ansatz zur Visualisierung konzeptionell durchaus 
vielversprechend schien, so konnte mit den in Abbildung \ref{fig-tree-in-box} 
gezeigten Bauteilen nicht fortgefahren werden. Sowohl die Box als auch der Baum selbst wurden aus Holzplatten von 3mm 
Stärke ausgeschnitten. Insbesondere der Baum war auf Grund der Kombination 
aus filigranen Blättern und Ästen mit dem zu schwach gewählten Material nicht 
weiter zu verwenden. Bereits durch den Transport aus den Räumlichkeiten 
des \textit{FabLab} verlor er eine Vielzahl an Blättern. Weiter hätten die Äste 
geteilt werden müssen, um das in \ref{sec-ita3-visualization} vorgestellte 
Konzept umzusetzen. Die Box selbst wurde als zu instabil beurteilt, als dass sie die Montage der Motoren und des Raspberry Pi hätte verkraften können.\\
Die Fahrzeugschaltung wurde um einen \textit{Step-Up Boost-Converter} erweitert. Hierdurch ist der reibungslose Betrieb auch bei Stromversorgung durch den Akku gewährleistet. Des Weiteren wurde auf Basis der Hardware der Visualisierung eine Schaltung erstellt und entsprechender Programmcode implementiert. Die Kommunikation zwischen den einzelnen Komponenten ist ab diesem Zeitpunkt funktionsfähig, sodass Verschmutzungswerte ausgewertet und dargestellt werden können.
\end{document}

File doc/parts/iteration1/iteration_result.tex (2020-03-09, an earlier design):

% !TeX spellcheck = de_DE
\documentclass[.../Dokumentation.tex]{subfiles}
\begin{document}
\subsection{Ergebnis}\label{sec-ita1-result}
Obwohl die in \ref{sec-ita1-cars} gezeigte Skizze die Dimensionen der zu 
installierenden Komponenten genau berücksichtigte, war der im Inneren des 
Fahrzeugs vorgesehene Platz nicht ausreichend bemessen.
Zu sehen ist diese Abweichung in Abbildung \ref{fig-car-too-small}.
Der Grund hierfür ist, dass die Spezifikationen des gewählten Akkus nicht 
berücksichtigten, dass der Akku selbst zusätzlich in einer schützenden Hülle 
verpackt ist. 
Um diese Hülle nicht entfernen zu müssen, wurden die 
Maße der Aussparung im Inneren des Fahrzeugs angepasst. Dadurch ergab 
sich weiter der Bedarf, diesen Zuwachs auch auf die Außenmaße anzuwenden. 
Außerdem wurde deutlich, dass das beispielsweise für die Radkästen benötigte
Stütz\-material auch in den Hohlräumen der Befestigungsvorrichtung 
eingesetzt wurde. \textit{Cura} verfügt nicht über die Option, Stützmaterial nur 
punktuell einzusetzen. Es wird entweder an jeder ermittelten Stelle verwendet 
oder an keiner. 
\begin{figure}[H]
    \begin{center}
    \includegraphics[
        width=0.5\linewidth,
    ]{imgs/car_too_small.jpg}
    \caption{Abweichende Maße des Akkus durch Hülle}
    \label{fig-car-too-small}
    \end{center}
\end{figure}
\noindent
Durch die Wahl einer abstrakteren Art der Darstellung besteht die Möglichkeit, 
dass der persönliche Bezug des Nutzers zu den simulierten Emissionen verloren 
geht.
Die in \ref{sec-concept} zur Sprache gekommene Unterlage verliert so, den damit 
verbundenen Aufwand berücksichtigend, an Wert.
Obwohl also durch die Umsetzung mit Hall-Sensoren 
eine recht präzise Messung der zurückgelegten Distanz möglich gewesen wäre, 
fiel an dieser Stelle die Entscheidung, auf jedwede Art von Untergrund 
für die Fahrzeuge zu verzichten. 
Beim Testen der Fahrzeugschaltung wurde festgestellt, dass die Kombination aus Pegelwandler und dem Pull-Up Widerstand nicht funktioniert und kein Auslesen von Sensorwerten möglich ist.
\end{document}

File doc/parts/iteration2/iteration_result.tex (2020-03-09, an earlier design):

% !TeX spellcheck = de_DE
\documentclass[.../Dokumentation.tex]{subfiles}
\begin{document}
\subsection{Ergebnis}\label{sec-ita2-result}
Während das in \ref{sec-ita1} zum Vorschein gekommene Problem des 
Platzmangels im Fahrzeuginneren gelöst werden konnte, wurde deutlich, 
dass es nicht möglich ist, wie in \ref{sec-ita2-cars} beschrieben, 
alle Komponenten in einem Druckvorgang herzustellen. 
Obwohl die beiden Hälften des Fahrzeugs mit einer Füllmaterialdichte von 
30\% eine ausreichende Stabilität erreichen, ist dies bei den Achsen und 
Bolzen zur Befestigung nicht der Fall. Bereits bei der zweiten Montage sind 
die an den Rädern befindlichen Achsen, wie in Abbildung 
\ref{fig-not-enough-filling} gezeigt, gebrochen. 
\begin{figure}[H]
\begin{center}
    \includegraphics[
        width=0.5\linewidth,
    ]{imgs/no_enough_filling.jpg}
    \caption{Achsbruch durch Mangel an Füllmaterial}
    \label{fig-not-enough-filling}
\end{center}
\end{figure}
\noindent
Darüber hinaus konnte auch das Problem des Stützmaterials in eigentlich 
dringend benötigten Hohlräumen zur Befestigung noch nicht behoben werden.
Auch die in \ref{sec-ita2-visualization} beschriebene Lösung zur 
Darstellung der Emissionen ist in dieser Form noch nicht zufriedenstellend. Die Tests der Fahrzeugschaltung sind erfolgreich verlaufen und die Grundstruktur für den Programmablauf wurde implementiert.
\end{document}

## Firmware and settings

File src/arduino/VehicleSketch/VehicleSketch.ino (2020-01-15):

#include <WiFiNINA.h>
#include <ArduinoJson.h>

#define PRINTLN(...)  {if(useSerial) {Serial.println(__VA_ARGS__);}};
#define PRINTLNF(...)  {if(useSerial) {Serial.println(F(__VA_ARGS__));}};
#define PRINT(...)  {if(useSerial) {Serial.print(__VA_ARGS__);}};
#define PRINTF(...)  {if(useSerial) {Serial.print(F(__VA_ARGS__));}};


//----------------------------------------------------------------------------------------------------------------------
// Config
//----------------------------------------------------------------------------------------------------------------------

//True if usb is connected. If not Serial must be disabled
//This can be done manually or automatically in the code
bool useSerial = true;

//Pins
const int ledPin1 = 2;
const int ledPin2 = 5;
const int hallSensorPin = 6;

//Network ssid and password
const char ssid[] = "RaspberryWlan";
const char pass[] = "raspi1234";

//Vehicle type
// 1 - Car
// 2 - Bus
const byte vehicleType = 1;

//Backend ip
const char backendIp[] = "192.168.4.1";
const unsigned int backendPort = 5000;
const unsigned long messageDelay = 50;

//----------------------------------------------------------------------------------------------------------------------
// Variables
//----------------------------------------------------------------------------------------------------------------------

//Wlan module status
int status = WL_IDLE_STATUS;

WiFiClient client;

//Sensor ticks
volatile unsigned int hallSensorTicks = 0;

//Json Generator. Size calculated with: https://arduinojson.org/v6/assistant/
StaticJsonDocument<38> doc;

//----------------------------------------------------------------------------------------------------------------------
// Setup, Loop, Interrupts
//----------------------------------------------------------------------------------------------------------------------

void setup() {
    //Set the led pinMode
    pinMode(ledPin1, OUTPUT);
    pinMode(ledPin2, OUTPUT);
    pinMode(hallSensorPin, INPUT);

    //Initialize Serial
    useSerial = initializeSerial(useSerial, 2500);

    PRINTF("Vehicle type: ");
    PRINTLN(vehicleType);

    if (!checkWifi()) {
        while (true) {};
    }

    //Connect to wifi
    connectToWifi();
    printNetworkInformation();

    turnOnLeds(true);
    PRINTLNF("Setup completed. Continue by activating the hall sensor...");
    while (digitalRead(hallSensorPin) == HIGH) {
        delay(1);
    };
    PRINTLNF("Hall sensor activated.");

    //Attach Interrupt
    PRINTLNF("Attaching Interrupts.");
    attachInterrupt(digitalPinToInterrupt(hallSensorPin), hallSensorInterrupt, FALLING);

    PRINTLNF("Starting Loop...");
}

void loop() {
    turnOnLeds(true);
    delay(messageDelay);
    bool cancelExecution = false;

    unsigned long startTime = millis();

    PRINTLNF("--------------------------------------------------");
    PRINTF("Amount of ticks: ");
    PRINTLN(hallSensorTicks);

    //Store the value and remove the amount from the variable
    unsigned int tmpAmountTicks = hallSensorTicks;
    hallSensorTicks -= tmpAmountTicks;

    //If no ticks occurred, stop execution
    if (tmpAmountTicks == 0) {
        PRINTLNF("No hall sensor ticks registered.");
        cancelExecution = true;
    }

    //Check the connection state
    if (!cancelExecution && connectToWifi()) {
        PRINTLNF("New Connection established. Reset values.");
        hallSensorTicks = 0;
        cancelExecution = true;
        turnOnLeds(true);
    }

    //TODO change to !cancelExecution
    if (!cancelExecution) {
        buildJson(vehicleType, tmpAmountTicks);
        PRINTF("Generated Json: ");
        if (useSerial) {
            serializeJson(doc, Serial);
        }
        PRINTLN();

        postSensorData();
    }

    unsigned long endTime = millis();
    PRINTF("Loop execution time (ms): ");
    PRINTLN(endTime - startTime);

}

void hallSensorInterrupt() {
    hallSensorTicks++;
}

//----------------------------------------------------------------------------------------------------------------------
// Private methods
//----------------------------------------------------------------------------------------------------------------------

/**
 * initialize the serial. If no usb connection is made, the process will terminate after the given delay.
 * @param initSerial true if the serial monitor should be initialized. If the value is false, the process will be skipped
 * @param maxDelay the max time in millis to wait for the serial
 * @return true if serial was initialized and can be used
 */
bool initializeSerial(bool initSerial, unsigned long maxDelay) {
    // If useSerial is false, dont initialize Serial
    if (!initSerial) {
        blinkLeds(10, 100);
        return false;
    }

    Serial.begin(9600);
    unsigned long startTime = millis();
    bool toggleLedState = true;

    while (!Serial) {
        if (millis() >= startTime + maxDelay) {
            Serial.end();
            break;
        }

        toggleLedState = toggleLedsAlternately(toggleLedState);
        delay(500);
    }

    //If Serial should be used blink slow 3 times, if not 10 times fast
    if (Serial) {
        PRINTLNF("Serial is initialized.");
        blinkLeds(3, 1000);
        return true;
    } else {
        blinkLeds(10, 100);
        return false;
    }
}

/**
 * toggle the leds alternately
 * @param state the state of the led
 * @return the toggled state
 */
bool toggleLedsAlternately(bool state) {
    if (state) {
        digitalWrite(ledPin1, LOW);
        digitalWrite(ledPin2, HIGH);
    } else {
        digitalWrite(ledPin1, HIGH);
        digitalWrite(ledPin2, LOW);
    }
    return !state;
}

/**
 * turn both leds on or off
 * @param state true if the leds should be turned on
 * @return the inverted state !state
 */
bool turnOnLeds(bool state) {
    if (state) {
        digitalWrite(ledPin1, HIGH);
        digitalWrite(ledPin2, HIGH);
    } else {
        digitalWrite(ledPin1, LOW);
        digitalWrite(ledPin2, LOW);
    }
    return !state;
}

/**
 * blink both leds the given amount of time with the given interval
 * @param amountBlinks the amount how often both leds blink
 * @param interval the time where the leds are on and off
 */
void blinkLeds(int amountBlinks, unsigned int interval) {
    for (int i = 0; i < amountBlinks * 2; i++) {
        turnOnLeds(i % 2 == 0);
        delay(interval);
    }
}

/**
 * check and print the status of the wifi module.
 * @return true if the wifi module is found and can be used
 */
bool checkWifi() {
    //Check if Wifi module exists
    PRINTLNF("Check status of wifi module...");
    if (WiFi.status() == WL_NO_MODULE) {
        PRINTLNF("Communication with WiFi module failed! Execution is stopped!");
        return false;
    } else {
        PRINTLNF("Wifi module found.");
    }

    //Check firmware version
    String fv = WiFi.firmwareVersion();
    if (fv < WIFI_FIRMWARE_LATEST_VERSION) {
        PRINTLNF("Please upgrade the firmware");
    }

    return true;
}

/**
 * Connect to the specified wifi network.
 * If a connection is already established, the connection process will be skipped
 * @return true if a new connection was made, false if the module was already connected
 */
bool connectToWifi() {
    //True if the a connection has to be made
    bool connectionRequired = false;

    status = WiFi.status();
    while (status != WL_CONNECTED) {
        connectionRequired = true;
        PRINTF("Attempting to connect to WPA SSID: ");
        PRINTLN(ssid);
        status = WiFi.begin(ssid, pass);

        // wait 10 seconds for connection and toggle led
        bool ledState = false;
        for (int i = 0; i < 20; i++) {
            ledState = toggleLedsAlternately(ledState);
            delay(500);
        }
    }

    //Print statement only if the connection is new
    if (connectionRequired) {
        PRINTLNF("Connection established.");
        blinkLeds(1, 1000);
    }

    return connectionRequired;
}

/**
 * print the network information
 */
void printNetworkInformation() {
    // print your board's IP address:
    PRINTLN()
    PRINTLNF("--- Wifi und Network Information ---");

    // print the SSID of the network you're attached to:
    PRINTF("SSID: ");
    PRINTLN(WiFi.SSID());

    // print the received signal strength:
    long rssi = WiFi.RSSI();
    PRINTF("Signal strength (RSSI):");
    PRINTLN(rssi);

    // print the encryption type:
    byte encryption = WiFi.encryptionType();
    PRINTF("Encryption Type:");
    PRINTLN(encryption, HEX);
    PRINTLN();

    IPAddress ip = WiFi.localIP();
    PRINTF("IP Address: ");
    PRINTLN(ip);

    PRINTLNF("------------------------------------");
    PRINTLN();
}

/**
 * add the json values in the json document
 * @param id of the vehicle type
 * @param hallSensorTicks the amount of hall sensor ticks
 */
void buildJson(int id, int hallSensorTicks) {
    doc["id"] = id;
    doc["th"] = hallSensorTicks;
}

/**
 * Post the hall sensor data to the server
 * @return true if the data was sent successfully
 */
bool postSensorData() {
    client.stop();

    if (client.connect(backendIp, backendPort)) {
        PRINTLNF("Connected to server");

        client.println("POST /vehicle HTTP/1.1");
        client.print("Host: ");
        client.println(backendIp);
        client.println("Connection: close");
        client.println("Content-Type: application/json");
        client.print("Content-Length:");
        client.println(measureJson(doc));
        client.println();
        serializeJson(doc, client);
        client.println();

        PRINTLNF("Data sent to server");
        return true;
    } else {
        PRINTLNF("Connection to server failed. Aborting!");
        blinkLeds(10, 100);
        return false;
    }
}

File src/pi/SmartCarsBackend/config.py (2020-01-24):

import board
import neopixel

from model.vehicle import Vehicle


class BaseConfig(object):
    DEBUG = False
    TESTING = False
    SECRET_KEY = "it worked"
    AVAILABLE_VEHICLES = [
        Vehicle(id_=1, name='Car', radius_wheel=2.0, amount_magnets=2, pollution_per_cm=5),
        Vehicle(id_=2, name='Bus', radius_wheel=2.0, amount_magnets=2, pollution_per_cm=2)
    ]

    POLLUTION_LOG_DELAY = 20

    # Pollution Min Max Values
    MIN_POLLUTION = 100
    MAX_POLLUTION = 5000

    # Hardware
    HARDWARE_LOOP_SLEEP = 0.1
    LED_STRIPE_PIN = board.D18
    LED_STRIPE_ORDER = neopixel.GRB
    LED_STRIPE_SIZE = 60
    LED_STRIPE_CENTER_LED_RIGHT = 52

    LED_STRIPE_MODE = 1
    SERVO_MOTOR_PINS = [5, 19, 13, 6]


class DevelopmentConfig(BaseConfig):
    DEBUG = True
    TESTING = True


class TestingConfig(BaseConfig):
    DEBUG = False
    TESTING = True

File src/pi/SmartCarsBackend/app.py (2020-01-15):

import logging
import threading
from time import sleep

from flask import Flask, request

from car_service.vehicle_service import VehicleService
from hardware.led_stripe import LedStripe
from hardware.servo_motors import ServoMotors

app = Flask(__name__)

logging.basicConfig(level=logging.DEBUG,
                    format='%(asctime)s %(levelname)s %(name)s %(threadName)s : %(message)s')

app.config.from_object('config.DevelopmentConfig')

with app.app_context():
    car_service = VehicleService()
    led_stripe = LedStripe()
    servo_motors = ServoMotors()


def loop() -> None:
    """Specifies the functionality that should be run in a loop"""

    # Clean the log with a thread lock
    thread_lock = threading.Lock()

    thread_lock.acquire()
    car_service.clean_log()
    thread_lock.release()

    current_pollution = car_service.sum_pollution()
    total_amount_entries = car_service.total_amount_entries_log()
    app.logger.debug(
        "Total Amount Entries: {}, Current Pollution: {}".format(total_amount_entries, current_pollution))

    led_stripe.set_led_stripe(current_pollution)
    servo_motors.set_servo_motors(current_pollution)

    # TODO Add hardware and clean log
    # app.logger.info("Add here hardware functionality")


@app.before_first_request
def activate_job():
    """Start a thread to run the loop function every x seconds. The delay can be specified with the config file"""
    sleep_time = app.config['HARDWARE_LOOP_SLEEP']
    app.logger.info("Hardware loop sleep time is {} second(s)".format(sleep_time))

    def run_job():
        while True:
            loop()
            sleep(0.1)

    thread = threading.Thread(target=run_job)
    thread.start()


@app.route('/')
def hello_world():
    app.logger.info("Hello world called")
    return 'Hello World!'


@app.route('/vehicle', methods=['POST'])
def vehicle_tick():
    json_body = request.get_json(force=True)

    if json_body is None:
        app.logger.warn("Api Request without body! Cancel request")
        return

    vehicle_id = json_body.get('id', 1)
    amount_ticks = json_body.get('th', 1)
    app.logger.debug("Vehicle Tick Body: id={}, ticks={}".format(vehicle_id, amount_ticks))
    car_service.add_vehicle_tick(vehicle_id=vehicle_id, amount_ticks=amount_ticks)
    return "", 200


if __name__ == '__main__':
    app.run(debug=True, use_reloader=False)
    app.logger.info("App finished")

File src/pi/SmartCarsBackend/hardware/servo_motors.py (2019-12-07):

import logging

import RPi.GPIO as GPIO
from flask import current_app as app

import hardware.utils as utils

log = logging.getLogger('servo_motors')


class ServoMotors:

    def __init__(self) -> None:
        """Initialize the servo motor pins with the specified values from the config"""
        self.servo_motor_pins = app.config['SERVO_MOTOR_PINS']
        self.max_pollution = app.config['MAX_POLLUTION']
        self.min_pollution = app.config['MIN_POLLUTION']
        self.initialized_pwm_pins = []

        GPIO.setmode(GPIO.BCM)

        for pin in self.servo_motor_pins:
            GPIO.setup(pin, GPIO.OUT)

            new_initialized_pin = GPIO.PWM(pin, 50)  # 50hz frequency
            new_initialized_pin.start(2.5)
            self.initialized_pwm_pins.append(new_initialized_pin)

        self.last_duty_cycle = 2.5

    def set_servo_motors(self, current_pollution_grade) -> None:
        """
        Set the servo motor positions according to the current pollution grade
        :param current_pollution_grade: the current absolute pollution grade
        :return: None
        """
        relative_pollution = utils.calculate_pollution_grade(current_pollution_grade,
                                                             180,  # the value in degrees
                                                             self.max_pollution,
                                                             self.min_pollution)

        duty_cycle = relative_pollution / 18 + 2.5
        if not duty_cycle == self.last_duty_cycle:
            self.last_duty_cycle = duty_cycle

            for pin in self.initialized_pwm_pins:
                pin.ChangeDutyCycle(duty_cycle)

            logging.debug("Duty cycle: {}".format(duty_cycle))

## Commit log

2019-10-08 first model
    [draft.skp]
2019-10-14 updated material lista nd added sketch for tree
    [MaterialListe.xlsx]
2019-10-16 Modelling and hall specs
    [draft.skp]
2019-10-16 updated material list
    [MaterialListe.xlsx]
2019-10-17 adjustments for new wheels and more space for hardware
    [draft.skp]
2019-10-20 modeling + slides
    [draft.skp]
2019-10-20 add wiring diagram for backend
    [BackendWiring.fzz]
2019-10-20 add wiring diagram for arduino
    [CarWiring.fzz]
2019-10-20 add images to presentation, remvoe placeholder and rename folder
    [BackendWiring.fzz, CarWiring.fzz]
2019-10-20 add wiring image
2019-10-21 car fastening, slides and screenshots
    [draft.skp]
2019-10-27 second fastening + upper part rework + stl export of lower half and printable file
    [draft.skp, lower.stl]
2019-10-28 updated wiring
    [CarWiring.fzz]
2019-11-02 build json message in arduino
2019-11-04 tree model + slides
    [tree.skp]
2019-11-05 update serial initialization to work with battery usage
2019-11-05 add serial print macros
2019-11-09 added 1cm to internal box
    [draft.skp]
2019-11-11 add neopixel library, add led module
2019-11-12 printable files and adjustments
    [draft.skp, fastening_back_back2front.stl, fastening_back_left2right.stl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]
2019-11-18 add led stripe code with fading lights
2019-11-25 wider fastening
    [draft.skp]
2019-11-26 new wheels wider axis
    [draft.skp, lower.stl, upper.stl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]
2019-11-27 second animation fix
    headlights in model
    [draft.skp]
2019-11-27 model changes
    printable files
    wheels and fastening with 80% fill
    [draft.skp, lower.stl, wheel.stl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]
2019-12-04 fastening width
    [draft.skp]
2019-12-04 new place for hall sensor
    alternative lower and upper half with new approach to fastening
    [draft.skp]
2019-12-05 code cleanup arduino
2019-12-05 fixed pin
2019-12-07 turn on led on arduino loop, and blink with connection error, add initial servo motor implementation
    [VehicleSketch.ino, servo_motors.py]
2019-12-07 update servo motor implementation, use multiple pwm pins, add comments
2019-12-07 updated tree wiring
    [BackendWiring.fzz]
2019-12-11 alt model modifications and gcode
    [draft.skp, fastening_vertical_long.stl, fastening_vertical_short.stl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]
2019-12-11 tree and box for cutting
    [box.dxf, tree.dxf]
2019-12-14 update car wiring for final prototype pcb's
2020-01-15 added Bus model and printable gcode for umo and ume2
    [bus_lower.stl, bus_upper.stl, draft.skp]
2020-01-16 update pins for prototype pcb
2020-01-23 add poc of second led stripe animation
2020-01-24 code cleanup for led stripe
2020-01-24 update wiring schematics to final
    [BackendWiring.fzz, CarWiring.fzz]
2020-01-29 add LED resistors to wiring
    [CarWiring.fzz]
2020-02-22 start writing und hard and software second iteration
